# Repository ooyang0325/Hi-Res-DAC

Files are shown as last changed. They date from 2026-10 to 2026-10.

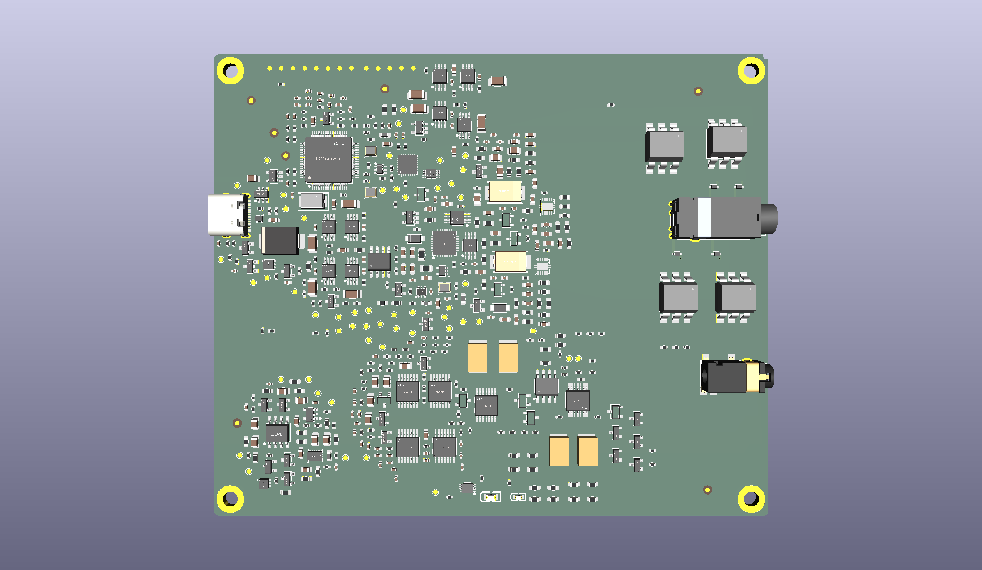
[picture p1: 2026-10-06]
hardware/DAC_HPA_3D_review.png

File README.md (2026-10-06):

# Hi-Res DAC + balanced headphone amplifier

The current layout review candidate is the editable [120 × 100 mm integrated-audio KiCad board](hardware/DAC_HPA_120x100_INTEGRATED_AUDIO_STUDY_ONLY.kicad_pcb), with manual placement and partial routing, paired with the [schematic](hardware/DAC_HPA.kicad_sch). Parts List v0.9 and Calculation Package v1.1 remain the baseline; the [captured ECO](hardware/FUNCTIONAL_ECO_2026-09-28.md) adds buffered supervisor readbacks and local J702 TVS parts. The incoming layout engineer should start with the [29 September handoff](hardware/LAYOUT_ENGINEER_HANDOFF_2026-09-29.md); peer reviewers can use the [reviewer guide](hardware/REVIEWER_START_HERE.md). The full-rate MCU capture guard, physical overlays, output routability and JLCPCB process gates remain open. No PCB manufacturing or PCBA order files are released.

## GitLab CI/CD

`.gitlab-ci.yml` uses the fixed official KiCad 10.0.1 container. Every pipeline checks schematic regeneration, netlist/ERC, the exact ECO delta, attach-charge arithmetic, placement geometry, JLC fabrication/assembly proxies, DRC and 3D model paths. A successful pipeline delivers the nine-page review PDF, the integrated-audio board's 3D GLB and top/L2/L3/bottom SVGs, earlier board GLBs for comparison, reviewer guides, BOM CSVs and a ZIP of the committed source as downloadable artifacts for 30 days.

The GitLab review package is **not** a manufacturing release. The connector and physical gates are tracked in [connector review](hardware/CONNECTOR_REVIEW.md) and [PCBA process review](hardware/PCBA_PROCESS_REVIEW.md). A routed PCB and CPL would be required for a PCBA upload.

The latest [DAC/core checkpoint](hardware/DAC_CORE_ROUTE_STUDY.md) records BCLK/LRCLK/SDATA at 22.213/22.324/22.879 mm and MCLK at 8.381 mm. The current integrated board has 544 footprints, 250 nets, 855 track/via items (143 vias), 864 full ratsnest links, 499 DRC-unconnected items and zero DRC violations. Its manual delta is 138 moves, eight source-copper removals and 828 additions. C622 has local 3V3D and GND copper; the global 3V3D feed remains open. All 12 U609/U610 timer branches pass the ≤8 mm screen without timer-net vias; C635/C636 U609 bypasses are locally connected, while upstream rail feeds and U609 VT/control escapes remain open. The [integrated-audio route study](hardware/INTEGRATED_AUDIO_ROUTE_STUDY.md) covers the DAC/I/V, amplifier-input, U501 and amplifier-to-jack copper including the completed U609/U610 timer branches and U609 local bypass work. Two U202 and five U301 exposed-pad vias are filled and capped; U401/U402 output-amplifier EP thermal routes remain open. The [via-pad audit](hardware/INTEGRATED_AUDIO_VIA_PAD_PROCESS_AUDIT.json) still flags 45 unfilled via-to-SMT-pad sites within 0.35 mm for JLC mask/process review. Full routing, system ESD, EMI and audio tests remain open; zero DRC violations apply to partial copper only.

The [schematic simplification review](hardware/SCHEMATIC_SIMPLIFICATION_REVIEW.md) lists three small DNF options for later review. Both headphone jacks and USB High mode remain required. The [discharge capture review](hardware/DISCHARGE_CAPTURE_REVIEW.md) identifies an open U303 calculation mismatch and links a separate [three-resistor 2512 fit option](hardware/DAC_HPA_120x100_DISCHARGE_FIT_OPTION_ONLY.kicad_pcb); the captured EN connection remains intentional, and the option is not a schematic/BOM change. The [Freerouting probe](hardware/FREEROUTING_PROBE.md) rejected a whole-board route and records two individually reviewed low-speed paths adopted later. The [functional-ECO board](hardware/DAC_HPA_120x100_FUNCTIONAL_ECO_STUDY_ONLY.kicad_pcb) is the preceding placement baseline; the former primary and [macro study](hardware/MACRO_PLACEMENT_REVIEW.md) are earlier comparisons. No PCBA order is authorized.

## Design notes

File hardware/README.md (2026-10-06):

# DAC-HPA KiCad schematic and routing studies

**Sending this design for peer review?** Begin with the [layout handover report](LAYOUT_HANDOVER_REPORT.md) and [REVIEWER_START_HERE.md](REVIEWER_START_HERE.md), then use the [schematic](SCHEMATIC_REVIEW_GUIDE.md), [placement](PLACEMENT_REVIEW_GUIDE.md), and [command-line visual inspection](PCB_CLI_VISUAL_REVIEW.md) guides. The [findings template](REVIEW_FINDINGS_TEMPLATE.md) records actionable review results against one Git commit.

The [functional-ECO placement baseline](DAC_HPA_120x100_FUNCTIONAL_ECO_STUDY_ONLY.kicad_pcb) is a separate 120 × 100 mm review board made from explicit hand-selected coordinates. It includes the [readback, J702 TVS and I/V A/B-channel schematic ECO](FUNCTIONAL_ECO_2026-09-28.md), a tighter DAC bypass row and the local J702 TVS branches. The [integrated audio study](INTEGRATED_AUDIO_ROUTE_STUDY.md) is the current routing review candidate; the newer [DAC/core checkpoint](DAC_CORE_ROUTE_STUDY.md) records its latest clock, I²S and local power routes. The [Freerouting probe](FREEROUTING_PROBE.md) rejects the whole-board result and documents two selectively adopted low-speed routes. [Layout review](FUNCTIONAL_ECO_LAYOUT_REVIEW.md) and [constraint disposition](CONSTRAINT_DISPOSITION_V2.md) state the remaining route work. `DAC_HPA.kicad_pcb` and the [prior macro study](MACRO_PLACEMENT_REVIEW.md) are historical comparisons; they predate the eight added parts.

Open `DAC_HPA.kicad_pro` or `DAC_HPA.kicad_sch` in KiCad 10. The root page links eight circuit sheets following Design Spec v1.1, Schematic Design Notes v1.0, Parts List v0.9, and Capture Update Note v1.0.

`DAC_HPA_review_only.pdf` is a nine-page visual export of the current provisional capture. The expanded protection sheet uses A1; smaller blocks use A2/A3/A4. Each sheet title block identifies v1.1-ECO1 and the open F01/F03/G-1–G-4 holds. The KiCad project is the editable source.

## Current status

- The v0.9 workbook has 526 netlisted designators and 1,445 pin rows; those rows still match Calculation Package v1.1. The [asserted functional ECO](FUNCTIONAL_ECO_2026-09-28.md) adds eight parts and reassigns equivalent U403/U404 A/B channels to match the manual I/V macro. KiCad now has **534 netlisted designators, 1,465 pins, 1,422 connected pins, 43 no-connect pins and 250 named nets**, plus four grounded mounting holes and seven fiducials. The exact **34** workbook-to-capture pin/net differences are checked; they include the earlier D705/D706 polarity fix. J702 pins 5/6 remain no-connect break contacts.
- Per-part MPN, LCSC code, fit class, package, and rating/tolerance properties are included for later [JLCPCB BOM preparation](https://jlcpcb.com/help/article/how-to-generate-the-bom-and-centroid-file-from-kicad). The owner approved changing U403/U404 from workbook OPA2210IDR SOIC-8 to OPA2210IDGKR VSSOP-8, C2876414. `generate_schematic.py` asserts the old workbook entry and applies this explicit override; `IV_7MM_RECHECK.md` records the provisional 7 mm input-route reassessment and sourcing/footprint limitations.
- The review-only JLCPCB BOM contains **463 placed parts**, seven owner-fitted and nine DNF parts. Fourteen placed parts have no LCSC code and need the documented global-sourcing process. The three CSVs are **not** an order package; a routed PCB and CPL are still required.
- The schematic-aligned four-layer **120 × 100 mm functional-ECO baseline** has **544 footprints and 250 named nets**; J703 remains a schematic DNF option with no PCB pads. Its partial copper comprises J701/J702 local TVS branches and the hand-routed X201→R203→U301 MCLK trunk, R227 return and R665→U607 monitor input: **28 F.Cu tracks, seven vias** and one filled L2 GND zone. It has zero geometry DRC violations and 1,144 full ratsnest gaps. The old 536-footprint primary and 100 × 80/100 × 100 mm boards are historical comparisons.
- The [separate 270° output-macro study](OUTPUT_MACRO_ROUTE_STUDY.md) keeps the same schematic/pad map and manually connects all four U401/U402 amplifier outputs and local feedback to K601–K604 relay inputs. Its partial copper passes custom-rule DRC, but the jack outputs, input/T networks, supply returns and L3/L4 audio return remain on hold; it is a comparison, not the primary order board.
- The current [integrated-audio routing study](INTEGRATED_AUDIO_ROUTE_STUDY.md) routes four DAC→I/V inputs, eight I/V→first-T feeds, all eight local input T triplets and all four amplifier-to-jack paths. The current board has **855 track/via items (143 vias), zero DRC violations, 499 DRC-reported unconnected items and 864 full `pcbnew` ratsnest links**. Its manual record has **138 footprint moves, eight removed source-copper items and 828 added items**. DACL/DACLB/DACR/DACRB no-via F.Cu routes measure **4.294/6.030/6.837/4.786 mm** against the provisional 7 mm target, leaving DACR **0.163 mm**. Saved L2 GND is directly below all four input traces at 0.01 mm route samples and offsets 0, ±0.05, ±0.10 mm. The longest I/V→first-T feed is **47.752 mm** on the right; the largest projected 2D I/V feedback area is **4.875 mm²**, excluding vertical and return-current area. DACL's U403→C417 feedback branch still lacks direct L2 for **1.9426 mm** of centreline (**+0.0597 mm** from the like-for-like committed baseline). Central VREF copper reaches **14.422 mm**. Extract summing-node capacitance, the DACL feedback return, 3D loop geometry, right-side cross-layer coupling and VREF noise before I/V sign-off.
- The newer [DAC/core checkpoint](DAC_CORE_ROUTE_STUDY.md) records U202 local bypass routes at 1.103/2.056/3.057 mm, U302 VIN→C301 at 0.875 mm and OUT→C302 at 2.131 mm, and connected U303→DAC 1V3 copper at **25.393 mm with two vias**. C622 at **(108.65, 105.50)** has a **4.615 mm** U604.8→C622.1 path and a **1.020 mm** C622.2→Ø0.7/0.3 mm GND via path at **(110.15, 105.50)**, with saved L2 GND beneath both; the global 3V3D feed remains open. Thirty-five local GND pads reach L2. Two U202 and five U301 EP vias are filled/capped; U401/U402 output-amplifier EP thermal routes remain open. The via-pad audit reports zero unfilled overlaps and zero unfilled gaps below 0.10 mm; **45** unfilled via-to-SMT-pad sites within 0.35 mm need JLC mask/process review. Local film/via/timer geometry gates pass, while those 45 process reviews remain open.
- The integrated checkpoint routes all 12 U609/U610 timer branches under the named-pad ≤8 mm screen without timer-net vias. U609 LP C/Q/R routes are **6.089/5.340/4.943 mm** and LN routes **6.038/5.814/6.685 mm**; U610 LP routes are **6.442/7.607/1.789 mm** and LN routes **7.177/7.712/7.787 mm**. C631/C632/C633/C634 GND returns reach L2 in **3.580/3.656/2.650/2.650 mm**. C635/C636 U609 VPOS/VNEG bypasses connect with 11 new vias (six GND, three VPOS, two VNEG). Upstream rail feeds and U609 VT/control escapes remain open. U605/R675/R676/R679/R677 moved left 1.2 mm and C625 moved beside R666, clearing six measured 5 mm I²S/protection gaps. C638 uses a two-via L3 VNEG bridge to keep the timer paths clear. C636 has a pair-specific **0.60 mm** side-courtyard gap to C631/C632; all four film-cap north/south solder approaches pass at ≥**1.5 mm** (minimum **3.045 mm**) per the [film solder-access audit](INTEGRATED_AUDIO_FILM_SOLDER_ACCESS_AUDIT.json).
- The [schematic simplification review](SCHEMATIC_SIMPLIFICATION_REVIEW.md) lists three small DNF options for later decision. The owner keeps both headphone jacks and USB High mode; no populated output links, relays, protection or hold-up parts are proposed for deletion.
- The [discharge capture review](DISCHARGE_CAPTURE_REVIEW.md) keeps the intended U303 EN=3V3D connection and identifies stale C06/C12 assumptions. A separate [physical fit option](DAC_HPA_120x100_DISCHARGE_FIT_OPTION_ONLY.kicad_pcb) tries three provisional 2512 discharge-resistor bodies. Its [audit](DISCHARGE_FIT_OPTION_SUMMARY.json) passes nominal body-edge, overlap, 3D and DRC screens, but it is not schematic/BOM aligned or a release board; maker/JLC lands, source feeds, thermal behavior and shutdown timing remain open.
- The [29 September layout-engineer handoff](LAYOUT_ENGINEER_HANDOFF_2026-09-29.md) identifies the primary board, CLI inspection sequence, route status, the separate discharge fit option and the next engineer's release gates.
- U501 local switching, VIN, VPOS/VNEG cap and feedback groups now have copper. Three bounded **0.20 mm** WSON VIN escapes precede the wider `5V_ANA_F` feeder. Its B.Cu feeder now detours around F.Cu `N5_FBP`: projected track overlap **0.1663→0 mm²** and unshielded pad-inclusive projection **0.0861→0 mm²**. The original via antipad remains; VIN3→C507 is **6.014 mm** within its 6.1 mm bound. C510/C511 GND vias are **8.160/6.767 mm** from U501's GND via by straight L2 via spacing, not an extracted return path. The board has zero exact or near-90° bends, zero footprint bbox overlaps, and zero classified JLC spacing findings. Full routing, system ESD, EMI/audio tests, measured R-15 and F01–F04/G-3/G-4 remain on HOLD. Courtyard gaps near C423/C426 are **0.150–0.194 mm**; C437/J701/K602 and via mask also need JLC order DFM review.
- Both U401/U402 pin-8 EN inputs have copper to the shared local VPOS bypass network. A custom rule screens 2 mm F.Cu left/right separation before the output links. With the [review-only 1 mΩ-max output-link candidate](OUTPUT_LINK_BOM_ECO.md), conditional worst 4.4 mm estimates are 0.3862/0.3737 Ω (L/R) at 1 kHz and 0.3990/0.3864 Ω in the 20 kHz model sensitivity. Contact/via assumptions, measured R-15 and physical/JLC gates still hold fabrication release.
- Every current footprint/pad net matches the ECO schematic. The new DAC high-frequency capacitors are 1.86–2.30 mm by pad distance from their supply pins; the U621 high-impedance input stubs are 1.69/1.86 mm by pad distance. The J702 TVS signal branches are 3.861/3.250 mm. The custom J701/J702 enlarged slot lands retain ≥0.31 mm worst calculated copper ring under the stated JLC slot tolerance. Physical G-3 overlays and JLC DFM remain open.
- All **478 component bodies** on the current candidate have resolvable 3D models; 66 test/debug/mechanical copper items intentionally have none. `3D_MODEL_REVIEW.md` distinguishes exact JLC/Toshiba sources from approximate oscillator and film-capacitor bodies. Open the current candidate in **View → 3D Viewer**.
- `verify_critical_footprints.py` checks 56 critical pad dimensions, pad types and hole/paste properties, including U202's exposed pad, the new TI DGK and onsemi SOT-23 lands, and J101/J701/J702 slots and locating holes. Physical G-3 overlays are still open.
- `G3_CONNECTOR_OVERLAY_REVIEW_ONLY.svg` and `G3_PART_OVERLAY_REVIEW_ONLY.svg` are printable A4 1:1 overlays for 30 unique footprint patterns, including U621 and the J702 TVS package; first measure each 10 mm reference bar. `G3_OVERLAY_INDEX.md` identifies the patterns and `G3_OVERLAY_CHECKLIST.md` holds editable physical sample results. The two-sample DMM and polarity templates are `G1_G2_CONTINUITY_RECORD.md` and `G4_POLARITY_CHECKLIST.md`.
- KiCad ERC reports zero violations. Confirmed power, logic, oscillator and open-collector outputs are typed; most other generated pins remain passive, so ERC does **not** substitute for a datasheet-level electrical review.
- `verify_design_notes.py` checks 1,002 selected circuit and approved-correction assertions. `SOURCE_RECONCILIATION.md` and the [ECO note](FUNCTIONAL_ECO_2026-09-28.md) record controlled changes from the source set.
- The v1.1 design documents mark schematic capture and provisional placement GO and originally hold routing until G-1–G-4 pass. The owner reports both J101 samples match the USB-C map, both J701 samples match the intended audio and 9/10 switch maps, and both J702 samples match the TRS and break map. On 27 September 2026 the owner waived the G-1/G-2 raw measurement log; these reported results are accepted for layout planning without independent evidence. G-3 overlays and G-4 polarity still hold routing, as do the new routability and audio/EMI placement conflicts. J702 supports TRS plugs only. `PRELAYOUT_GATES.md` tracks the gate evidence and later G-5/G-6 holds. See `CONNECTOR_REVIEW.md` for connector maps and copper-ring decision, `POLARITY_REVIEW.md` for the D705/D706 correction, and `CAD_models_to_upload.md` for exact 3D models still desired.
- `PCBA_PROCESS_REVIEW.md` records the J101/J702 plated slots with no paste apertures and the exact JLCPCB process question to resolve before assembly release. The v1.1 calculation package's starting output-impedance estimates are 0.251 Ω (3.5 mm) and 0.383 Ω (4.4 mm), with 50 mΩ budgeted per output link. The candidate link's 1 mΩ maximum reduces that model term; routed copper and illustrative vias give the current conditional 4.4 mm estimates above. The 3.5 mm signal-only lower bounds are 0.2255/0.2188 Ω (L/R), with sleeve return unextracted. Both jacks still need measurement against R-15, and the 50 mΩ per jack-contact estimate has no maker maximum.

The included JLCPCB library data came from LCSC codes through `dsa-t/jlc-kicad-lib-loader` 1.0.11. `JLC_Source/JLC_DAC_HPA.elibz` now keeps **42 source CAD entries**, including exact C507231 for U621; `JLC_Imported.pretty` contains native KiCad footprints, and `jlc_footprints.json` records pad comparisons. The TI DCK example land and JLC C507231 land differ, so U621 remains a G-3 overlay item. The project footprints are in `DAC_HPA.pretty`; custom land sources are in `FOOTPRINT_SOURCES.md`.

## Regenerate and verify

With Python 3, `openpyxl`, and KiCad 10 installed:

```sh
python3 hardware/audit_jlc_library.py
python3 hardware/derive_connector_footprints.py
python3 hardware/generate_schematic.py
python3 hardware/verify_schematic.py
python3 hardware/verify_design_notes.py
python3 hardware/export_assembly_review.py
python3 hardware/check_attach_charge.py
python3 hardware/check_spi2_capture_contract.py
/Applications/KiCad/KiCad.app/Contents/Frameworks/Python.framework/Versions/Current/bin/python3 hardware/verify_critical_footprints.py
/Applications/KiCad/KiCad.app/Contents/Frameworks/Python.framework/Versions/Current/bin/python3 hardware/audit_placement.py hardware/DAC_HPA_120x100_FUNCTIONAL_ECO_STUDY_ONLY.kicad_pcb --height 100 > /tmp/dac-eco-placement.json
/Applications/KiCad/KiCad.app/Contents/Frameworks/Python.framework/Versions/Current/bin/python3 hardware/audit_dfa_dfm.py hardware/DAC_HPA_120x100_FUNCTIONAL_ECO_STUDY_ONLY.kicad_pcb > /tmp/dac-eco-dfa.json
/Applications/KiCad/KiCad.app/Contents/Frameworks/Python.framework/Versions/Current/bin/python3 hardware/audit_jlc_fab.py hardware/DAC_HPA_120x100_FUNCTIONAL_ECO_STUDY_ONLY.kicad_pcb > /tmp/dac-eco-fab.json
/Applications/KiCad/KiCad.app/Contents/MacOS/kicad-cli pcb drc --format json --severity-error --severity-warning -o /tmp/dac-eco-drc.json hardware/DAC_HPA_120x100_FUNCTIONAL_ECO_STUDY_ONLY.kicad_pcb
/Applications/KiCad/KiCad.app/Contents/Frameworks/Python.framework/Versions/Current/bin/python3 hardware/check_functional_eco_layout.py hardware/DAC_HPA_120x100_FUNCTIONAL_ECO_STUDY_ONLY.kicad_pcb /tmp/dac-eco-placement.json /tmp/dac-eco-dfa.json /tmp/dac-eco-fab.json /tmp/dac-eco-drc.json
/Applications/KiCad/KiCad.app/Contents/Frameworks/Python.framework/Versions/Current/bin/python3 hardware/audit_3d_models.py hardware/DAC_HPA_120x100_FUNCTIONAL_ECO_STUDY_ONLY.kicad_pcb
/Applications/KiCad/KiCad.app/Contents/MacOS/kicad-cli sch export pdf -o hardware/DAC_HPA_review_only.pdf hardware/DAC_HPA.kicad_sch
```

`generate_schematic.py` reads `doc/DAC_HPA_Parts_List_v0.9.xlsx`, asserts the source pin maps, applies the ECO and rewrites the generated sheets/symbol library. Run the CAD audits before regeneration when source data changes. Manual KiCad edits to generated schematic files are replaced on regeneration; edit the generator's asserted ECO or make a controlled new workbook revision. `manual_functional_eco_layout.py` records all additional hand-selected positions and local J702 tracks; its UUIDs may differ on reproduction, while `check_functional_eco_layout.py` checks the committed geometry and schematic pad map. `manual_integrated_audio_study.py` replays the frozen manifest of **138 footprint moves, eight source-copper removals and 828 added copper items**; `check_integrated_audio_study.py` compares them with the review board. The command block above verifies the earlier functional-ECO baseline; the [integrated CI job](../.gitlab-ci.yml) audits the current candidate. `place_board.py --force` is only for historical automatic comparisons.

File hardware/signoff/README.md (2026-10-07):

# Independent sign-off suite

A self-contained review of the Hi-Res DAC board, built from published
criteria rather than from the repository's existing CI. Nothing here imports
or re-uses the other checks in this repo; the intent is a second opinion that
can disagree with the first.

## Running it

```powershell
# Extract the board model (positional argument, not --pcb)
python hardware/signoff/extract.py <board.kicad_pcb> -o hardware/signoff/out/model_integrated.json

# Run every gate
python -m hardware.signoff.run

# A single gate, or skip the simulations
python -m hardware.signoff.run --gate G40
python -m hardware.signoff.run --no-spice
```

Outputs land in `hardware/signoff/out/`:

| File | Contents |
| --- | --- |
| `signoff_result.json` | Full machine-readable result: metrics, findings, assumptions |
| `SIGNOFF_REPORT.md` | Human-readable summary |
| `spice/*.cir` | Every generated LTspice deck |
| `spice/*.log` | Measurement logs backing the simulation verdicts |

The exit code follows the worst gate status, so this works as a CI step.

## Design

```
extract.py   -- the only module that imports pcbnew; emits plain JSON
     |
     v
model_integrated.json  (tool-independent board model)
     |
     +-- geom.py        pad/track/drill geometry
     +-- netgraph.py    resistive network solver per net
     +-- parasitics.py  capacitor ESL/ESR and mounting inductance
     +-- rules.py       published numeric criteria
     +-- design_intent.py  what each net is for
     |
     v
gates_*.py  -->  run.py  -->  JSON + Markdown
```

Keeping KiCad behind `extract.py` means the gates are testable without the
EDA tool, and the same model feeds the geometric checks and the simulations,
so they cannot silently disagree about the board.

## Validation

A review tool that is wrong is worse than no review, so the geometric engine
was checked against KiCad's own DRC before any verdict was trusted:

```powershell
kicad-cli pcb drc --format json --severity-all -o hardware/signoff/out/kicad_drc.json <board.kicad_pcb>
```

| Check | KiCad | This suite |
| --- | --- | --- |
| Unconnected items | 0 | 0 opens across all 12 rails |
| `hole_clearance` errors | 4 (all at J101) | the same 4, same pads, same gaps |

Reaching that agreement found three real bugs in this suite, all of which had
produced confident but wrong output:

1. **T-junctions.** Tracks were modelled as a single endpoint-to-endpoint
   edge, so copper landing part way along another track was treated as
   unconnected. 70 of 333 VPOS endpoints land mid-span, which invented 53
   phantom islands and a 45-billion-millivolt IR drop. Tracks are now split at
   every node that touches them.
2. **Slot drills.** J701/J101 use oval slots. Treating them as circles of the
   major axis produced a false hole-to-hole failure and a physically
   impossible negative annular ring. Slots are now modelled as capsules.
3. **Rounded pad corners.** 762 pads are roundrect. Treating them as sharp
   produced a drill-to-copper violation KiCad did not report; with the real
   corner radius it disappears.

The LTspice measurement parser was likewise validated against a series R-L-C
circuit whose impedance is analytically known, before being pointed at the
board:

| Frequency | Analytic | LTspice via this parser | Error |
| --- | --- | --- | --- |
| 1 MHz | 1.65626 ohm | 1.65656 ohm | 0.02% |
| 10 MHz | 0.50112 ohm | 0.50212 ohm | 0.20% |

That test also caught a regex that let a log preamble line swallow the
following measurement's value.

## What the simulations do differently

`hardware/sim/dac_1v3_bypass.cir` states in its own header that its
inductances are "explicit assumptions" (5 nH and 20 nH). The decks in
`spice/` are generated instead from the board:

- **Capacitance** parsed from the placed part's value field.
- **ESL and ESR** from the actual package (`C_0402_1005Metric` -> 0402).
- **Mounting inductance** from the real via pair under each capacitor --
  measured pitch, measured drill, measured pad-to-via run -- via the
  loop-inductance result in C. R. Paul, *Inductance*.
- **Series resistance and path length** from the solved copper network, so a
  capacitor 33 mm away through copper is modelled as 33 mm away.

Measured mounting inductances come out at 1.0-2.1 nH, so the existing deck's
5 nH best case was pessimistic while its 20 nH case was unrepresentative.

## Handling what cannot be known

The board declares **no stackup**, so the height from the outer layer to the
first plane is unknowable from the design. Rather than pick a number, every
PDN deck sweeps `h` over the plausible construction range (0.09 / 0.12 /
0.20 mm) with `.step` and the gate reports the worst case. The same principle
is applied elsewhere:

- **G10** reports what each conductor would carry at 1 oz inner copper as
  well as the assumed 0.5 oz, which separates findings that survive the
  assumption from those that do not.
- **G40** reports, for every failing rail, the transient current at which it
  *would* pass, so the finding can be settled against a datasheet figure
  instead of against an estimate.

Current budgets in `design_intent.RAILS` are estimates and are marked
`assumed: True`. They should be reconciled with the Calculation Package.

## Gates

| ID | Title | Basis |
| --- | --- | --- |
| G01 | Fabricator process window | JLCPCB capability sheet |
| G02 | Electrical clearance | IPC-2221B Table 6-1 |
| G03 | Plated-hole geometry | IPC-6012 |
| G04 | Assembly geometry | IPC-7351B |
| G05 | Fabrication documentation | IPC-2614 / controlled-impedance practice |
| G06 | Drill-to-copper clearance | JLCPCB 0.28 mm; validated against KiCad DRC |
| G10 | Conductor ampacity | IPC-2221B `I = k dT^0.44 A^0.725` |
| G11 | Via ampacity | IPC-2221B applied to barrel cross-section |
| G12 | DC IR drop | Solved network against a per-rail budget |
| G13 | Decoupling placement and mounted resonance | Mounted self-resonant frequency |
| G20 | USB high-speed pair | USB 2.0 spec: 90 ohm +/-15%, 3.81 mm skew |
| G21 | Clock routing and aggressor spacing | 3W rule; jitter-limited SNR |
| G22 | Return path continuity | Ott, *EMC Engineering* |
| G23 | Switching-node keep-out | Analogue/digital separation floor |
| G30 | Output path resistance and channel matching | Self, *Audio Power Amplifier Design* |
| G31 | I/V and feedback loop geometry | Loop area as a magnetic antenna |
| G32 | External port ESD protection | IEC 61000-4-2 stub let-through |
| G40 | PDN impedance (LTspice) | Smith/Bogatin target impedance |
| G41 | Output loading and damping (LTspice) | Damping factor into the rated load |

`G06`, `G40` and `G41` are the gates with no counterpart in the existing CI.

## Known limits

- Copper weight is assumed (no stackup); G10/G11/G12 inherit that.
- `infer_rail_sources()` is a heuristic. G40 instead identifies regulators by
  their feedback net, which correctly separates the 1V3 LDO (U303, which has
  `N3_1V3_FB`) from the DAC that consumes the rail.
- G40 models each rail at its single worst-case pin, not as a distributed
  plane; it is a lumped study, not a 3D field solve.
- Zones are included in the solved network, but the board routes its rails as
  0.4 mm traces rather than poured planes, so this matters little here.

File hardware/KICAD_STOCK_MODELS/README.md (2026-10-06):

# Bundled KiCad package models

These 12 unchanged STEP models come from the installed KiCad 10 3D library,
whose upstream source is the [official KiCad Packages3D repository](https://gitlab.com/kicad/libraries/kicad-packages3D).
The KiCad community is credited as the library author. The files retain their
original library-relative names and directories. `MODEL_SOURCES.json` lists
each file and SHA-256 digest.

These models are distributed under KiCad's CC BY-SA 4.0 library license and
design exception, reproduced in [LICENSE.md](LICENSE.md). The project copies
only the shapes referenced by the current PCB and the discharge-fit option so
a fresh GitLab runner can resolve them while exporting review-only GLBs. The
2512 resistor body was added for the three-part power fit study. No 3D
geometry was changed.

To refresh this directory from an installed KiCad 10 library, run
`vendor_kicad_stock_3d_models.py` with KiCad's Python interpreter. By default
it scans the primary, integrated and discharge-fit boards; pass board paths
to restrict the scan. Set
`KICAD_STOCK_3D_SOURCE` if the installed 3D library is not in a standard
location. Review upstream revisions and license details before replacing the
copied files.

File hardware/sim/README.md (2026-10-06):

# DAC 1V3 bypass sensitivity (review model)

This study compares the fitted C312 1 µF bulk capacitor in the old remote
placement with the hand-moved position beside U301/C309. The old position was
**unrouted**: its straight pad-to-U301 distance was about 16.3 mm. The trial
position has about 4.3 mm of drawn C312→C309→U301 F.Cu centreline. C310
2.2 µF stays beside regulator U303, so its regulator output capacitance is
preserved. C309 is the DAC's local 100 nF part. The routes and filled L2
ground must be inspected on the current PCB study; these distances alone do
not specify branch inductance.

The latest [DAC/core route audit](../DAC_CORE_ROUTE_AUDIT.json) also reports
a connected U303→DAC 1V3 link whose L3 portion is 25.393 mm, with two
vias, 35 local DAC/CPLD/LDO GND pads connected to L2, and short
U302-to-capacitor routes.
These drawn connections do not supply the upstream ferrite rails or measure
the regulator, capacitor, or return impedance; the simulations below remain
assumption-based sensitivity results.

The [LTspice deck](dac_1v3_bypass.cir) and
[MATLAB sweep](dac_1v3_bypass.m) use three passive capacitor branches at
U301 pin 21. They assume C309 100 nF/50 mΩ/2 nH, C312 1 µF/50 mΩ with
either 5 nH (local) or 20 nH (remote), and C310 2.2 µF/60 mΩ/20 nH.
Inductances include **assumed** capacitor, trace and return effects; they
were not extracted from a quoted stackup or measured board. The 1 GΩ DC
bleeders in LTspice only define the operating point. A 1 A AC test source
therefore makes its simulated node-voltage magnitude equal to impedance in
ohms.

| Frequency | Local 5 nH, MATLAB | Remote 20 nH, MATLAB | LTspice check |
| --- | ---: | ---: | --- |
| 100 kHz | 0.4778 Ω | 0.4769 Ω | Within 0.01% |
| 1 MHz | 0.0832 Ω | 0.0431 Ω | Within 0.57% |
| 10 MHz | 0.0654 Ω | 0.0631 Ω | Within 1.36% |
| 80 MHz | 0.6619 Ω | 0.8249 Ω | Within 0.01% |

Across 100 kHz–80 MHz, the remote case has an **illustrative** 1.045 Ω
antiresonance near 4.66 MHz; the local case's largest sampled value is
0.662 Ω at the 80 MHz upper boundary. Moving a capacitor can also shift a
resonance unfavourably: the local case is higher at 1 MHz. See the
[MATLAB plot](dac_1v3_bypass_sweep.png),
[sweep data](dac_1v3_bypass_sweep.csv), and
[LTspice log](dac_1v3_bypass_ltspice.log).

The model excludes the regulator's output impedance, power-plane geometry,
MLCC capacitance versus bias/temperature, DAC load spectrum, other rail
coupling, dielectric loss and any audio transfer function. It does not
predict hum, RF ingress, jitter, or THD+N. Extract the routed supply and
ground loop, obtain capacitor impedance/derating data and measure ripple at
U301 under operating loads before accepting the rail.

There is a separate **component-value hold**. [ESS's ES9018K2M datasheet,
DVDD Supply](https://www.esstech.com/wp-content/uploads/2024/09/ES9018K2M-Datasheet-v3.7.pdf)
recommends a 2.2 µF ±20% local DVDD decoupler that retains at least 1 µF
at 1.2 V over operating temperature. Fitted C312 is 1 µF nominal. The
remote C310 is 2.2 µF, but cannot establish a local high-frequency return
by capacitance alone. Review a 2.2 µF C312 ECO or another local bulk part,
using verified effective-capacitance data and an updated schematic/BOM.
The captured 2.2 µF Samsung part is a 0603 X5R 16 V MLCC; its [manufacturer
page](https://product.samsungsem.com/mlcc/CL10A225KO8NNN.do) lists the
nominal ratings but does not establish the required effective capacitance
at this board's bias and temperature.

## Reproduce

On macOS with the installed tools, run from the repository root:

```sh
cp hardware/sim/dac_1v3_bypass.cir /tmp/dac_1v3_bypass.cir
/Applications/LTspice.app/Contents/MacOS/LTspice -b /tmp/dac_1v3_bypass.cir
/Applications/MATLAB_R2025a.app/bin/matlab -batch "run('hardware/sim/dac_1v3_bypass.m')"
```

The LTspice log reports AC magnitude in dB; convert with `10^(dB/20)` to
obtain ohms for its 1 A source. LTspice 26.0.2 and MATLAB R2025a completed
on 29 September 2026. Direct simulator invocation required normal macOS app
registration on this host; a sandboxed CLI launch had failed before either
simulation started.

# EMS review simulations (30 September 2026)

These review models support [EMS_VERIFICATION_2026-09-30.md](../EMS_VERIFICATION_2026-09-30.md).
They are assumption-based sensitivity studies, not extracted or measured
results. LTspice 26.0.2 (Windows build under Wine) runs from macOS with:

```bash
CX_BOTTLE_PATH="$HOME/Library/Application Support/LTspice/Bottles" \
  /Applications/LTspice.app/Contents/SharedSupport/ltspice/LTspice/wine --bottle=ltspice \
  --wait-children 'C:\Program Files\ADI\LTspice\LTspice.exe' -b -ascii 'Z:\path\to\deck.cir'
```

| Deck | Question | Result |
| --- | --- | --- |
| [ems_headphone_rf.cir](ems_headphone_rf.cir) | RF on the headphone cable (150 Ω common-mode source) reaching the OPA1622 inverting input, 10 MHz–6 GHz; R417 0 Ω vs ferrite bead, with/without a LEG C0G | As built, the output network (TVS 12 pF, relay and trace inductance, OPA1622 open-loop Z<sub>O</sub> 5.5 Ω + 63 nH from datasheet Fig. 40) resonates near 350–450 MHz with about 0 dB coupling. Coupling is −30 dB at 900 MHz and −61 dB at 2.4 GHz ([log](ems_headphone_rf_ltspice.log)). |
| [ems_rf_sweep.cir](ems_rf_sweep.cir), [ems_rf_best.cir](ems_rf_best.cir) | Bead impedance and LEG capacitor sweep | [sweep log](ems_headphone_rf_sweep_ltspice.log), [best-case log](ems_headphone_rf_best_ltspice.log) |
| [ems_5vana_filter.cir](ems_5vana_filter.cir) | FB501 + R531/C513 damper feeding the LM27762 | With the damper and 10 µF parts derated to 40 %, the line-transfer peak falls from +5.4 dB to +1.8 dB and the U501 input impedance peak from 1.25 Ω to 0.74 Ω. The 2 MHz charge-pump ripple stays 52–60 dB down on 5V_ANA ([log](ems_5vana_filter_ltspice.log)). |

[ems_budget.m](ems_budget.m) (MATLAB R2025a) turns the RF transfer into an output-referred
217 Hz buzz with TI's EMIRR square law. It uses the OPA2210 EMIRR curve as a proxy,
because the OPA1622 publishes none, and a −20 dB cable common-mode to tip conversion.
It also computes the USB-ripple and VREF paths from the LM27762, LP5907 and OPA1622 PSRR
curves ([summary](ems_budget_summary.txt), [plot](ems_rf_demod.png)). Regenerate
`ems_headphone_rf.raw` with the command above before running it.
[../review_output_rf_filter.py](../review_output_rf_filter.py) checks the proposed output
filter with the unchanged calibrated OPA1622 model from Calculation Package v1.1
([results](../OUTPUT_RF_FILTER_STABILITY_REVIEW.json)).

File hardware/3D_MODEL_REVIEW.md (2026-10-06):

# PCB 3D model review

The current **120 × 100 mm** schematic-aligned board is
`DAC_HPA_120x100_INTEGRATED_AUDIO_STUDY_ONLY.kicad_pcb`. Open it in KiCad 10 and
choose **View → 3D Viewer**. GitLab CI exports
`DAC_HPA_INTEGRATED_AUDIO_REVIEW.glb` for this candidate; the functional-ECO,
output-macro, macro-study and primary GLBs are earlier comparisons. A separate
[discharge fit option](DAC_HPA_120x100_DISCHARGE_FIT_OPTION_ONLY.kicad_pcb)
exports `DAC_HPA_DISCHARGE_FIT_OPTION_REVIEW.glb` with three provisional 2512
resistor bodies; it is not schematic/BOM aligned. Its GLB uses the bundled
KiCad stock 2512 STEP, while the separately retained [exact JLC R2512 STEP](EASYEDA_MODELS/R2512_L6.3-W3.2-H0.6.step)
and [CAD audit](DISCHARGE_JLC_CAD_AUDIT.json) support a later land/model
comparison. The prior
[full-board preview](DAC_HPA_3D_review.png) and [J101 closeup](DAC_HPA_J101_3D_detail.png)
show the historical primary after the USB-C model alignment correction.

The [manual macro-placement study](MACRO_PLACEMENT_REVIEW.md) has the older 536-footprint population. The [functional-ECO placement baseline](DAC_HPA_120x100_FUNCTIONAL_ECO_STUDY_ONLY.kicad_pcb) added D707/D708 with the existing SOD-523 model and U621 with a new exact-JLC C507231 SC70-6 body; the integrated board retains that 544-footprint population. These models remain subject to G-3 fit and JLC order checks.

## Coverage and sources

`audit_3d_models.py` checks model paths, file headers, and the JLC file hashes.
On the current integrated-audio board, **478 component bodies resolve**
(474 STEP and four VRML), while 66 copper-only items intentionally have no
model. Of the 478, 385 use KiCad stock models and 93 use project-local files.
The five historical review boards each have 536 footprints: **470 component bodies resolve**
(466 STEP and four VRML), while 66 copper-only items intentionally have no
model (53 test pads, seven fiducials, four mounting holes, and J201/J202 debug
pads). Of the 470, 380 use KiCad 10 stock models and 90 use files kept in this
project. The 90 project-file instances are 82 instances of 30 JLC package
models, four Toshiba relays, and four Panasonic body envelopes. The 380 stock
instances use only 11 distinct KiCad STEP files; unchanged copies are bundled
in `KICAD_STOCK_MODELS` for headless CI, with KiCad's license and hashes. The
fit option adds a twelfth distinct stock STEP shape for 2512 resistors; its
CI artifact includes the 3D audit, which resolves 478 populated bodies.

| Parts | 3D source and alignment | Confidence for 3D inspection |
| --- | --- | --- |
| J701, J702 and the imported JLC footprints | STEP from the component's EasyEDA/JLC CAD entry. The 31 files, source URLs, LCSC codes, conversions, and SHA-256 hashes are in `EASYEDA_MODELS/MODEL_SOURCES.json`. | Source package bodies; the modified jack copper and slots still require G-3 sample overlay and JLC DFM. |
| U621 | Exact C507231 JLC SC70-6 body and native pad geometry, normalized to STEP. | Model and pads match the JLC CAD entry, but TI's DCK example land has a wider pad-row span. Resolve the physical G-3/JLC DFM discrepancy before order. |
| J101 | KiCad 10 `USB_C_Receptacle_GCT_USB4105-xx-A_16P_TopMnt_Horizontal.step`, with −1.295 mm local Y offset for the custom footprint origin. A J101-only STEP probe puts the shell front at x = 40.03 mm beside the x = 40.00 mm board edge. | Exact connector family body; visually aligned in KiCad 3D Viewer. The footprint and solder lands remain at the GCT PCB-edge datum. G-3 physical overlay still open. |
| K601–K604 | User-supplied Ultra Librarian `TLP3545A_LF1__TOS.step`, stored as `DAC_HPA_3D/TLP3545A_LF1_UltraLibrarian.step`. Local Z rotation is −90° to align the model's pad-1 side to the custom LF1 footprint. | Exact Toshiba LF1 body; visually aligned in KiCad 3D Viewer. Source STEP SHA-256: `3534740be81c87bf067b67926e57872bb9693455f3bbc5ab0c75e69f7ab00c74`. |
| X201–X203 | KiCad stock `Crystal_SMD_2520-4Pin_2.5x2.0mm.step`. | 2520 four-pad package approximation; maker-exact oscillator bodies remain desirable. |
| C631–C634 | `DAC_HPA_3D/ECHU1H224GX9_envelope_only.wrl`, a 6.0 × 4.1 × 2.8 mm Panasonic body envelope. | Review-only shape without terminals. It renders in KiCad 3D Viewer but is omitted from non-mesh STEP export. Maker STEP remains desirable. |
| D102 and other stock-footprint parts | KiCad 10 standard package STEP models. | Package shapes for 3D inspection; confirm exact part dimensions at G-3. |

The original user-downloaded Ultra Librarian ZIP is not required by KiCad after
extracting its STEP. Its source ZIP SHA-256 is
`9c409738e9fb11241a2306db80b8167d6a3af8ac0be0cab408640a1d2ce81f1d`.
`fetch_jlc_3d_models.py` can restore the original 30 JLC STEP files from the saved
`JLC_Source/JLC_DAC_HPA.elibz` identifiers when network access is available;
it does not move footprints. `attach_3d_models.py` adds the twelve custom
model links to the five board snapshots if absent. GitLab CI sets
`KICAD10_3DMODEL_DIR` to the bundled stock library so its GLB includes the
same package shapes as the KiCad desktop installation, including the option's
new 2512 model.

## Limits

The 3D view verifies that model files load and permits visual package and
clearance review. It does **not** prove pad numbering, solder-joint geometry,
height tolerance, connector mating, or routability. G-3 overlays, the JLCPCB
DFM review, and routing/ESD gates in `PRELAYOUT_GATES.md` remain open. The
current integrated-audio board is a partial-route review, not a PCBA
release package.

KiCad's GLB exporter currently skips the four VRML film-capacitor envelopes;
use the KiCad 3D Viewer to see those bodies. An earlier primary-board GLB was
checked with Assimp as a valid 480-node, 6,042-mesh model after correcting
J101's offset.

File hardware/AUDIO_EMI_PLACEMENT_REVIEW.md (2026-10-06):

# Audio integrity and EMI placement review — 27 September 2026

For the current hand-placed 120 × 100 mm primary and its routed J701 TVS escapes, see `MANUAL_PLACEMENT_REVIEW.md`. The pad-gap findings below describe the earlier 100 × 100 mm automatic baseline unless that review reports a correction.

The later [manual macro-placement candidate](MACRO_PLACEMENT_REVIEW.md) regroups the most sensitive analog/protection parts; [constraint disposition](CONSTRAINT_DISPOSITION_V2.md) proposes an effective shared-return impedance test in place of treating a 3 mm strip width as a sign-off. This file's routed-audio discussion remains a primary-board historical screen until the candidate's full paths are drawn.

**Historical baseline status: HOLD.** The earlier 100 × 100 mm board had no tracks, ground plane, power pours or stitching vias. Its analog/digital isolation, impedance, channel separation, noise and crosstalk could not be certified from placement. `PLACEMENT_100x100_BASELINE_AUDIT.json` is its reproducible pad-level screen. The new primary has an L2 GND zone and four TVS routes but remains mostly unrouted and unqualified for audio or EMI performance.

## Ground and return architecture to implement

The v1.1 Spec R07/R10 and Notes §9.3.2 specify **one GND net and an unbroken L2 ground plane**. Digital devices stay west, analog signal paths east, and power conversion south-west. Separation comes from component placement and controlled signal/return paths; no ground-plane split is permitted. L1 carries USB, clocks, I²S and audio; L3 carries regional power and slow controls, L4 slow analog/control over a stitched GND pour. The historical 100 × 100 mm baseline had no copper. The 120 × 100 mm primary now has one filled L2 GND zone, four TVS signal tracks, four GND stubs and four vias; the remaining architecture is still a routing requirement.

At the DAC, DGND, AGND and AGND_L/R need local L2 vias and the exposed pad needs five vias. Each fast signal must retain its L2 return beneath the entire route, including at the digital-to-DAC boundary. The earlier source rule prescribed a dedicated ≥3 mm L1 headphone-return strip with at least four L2 vias at each jack ground pin. The new [constraint disposition](CONSTRAINT_DISPOSITION_V2.md) requires an effective shared-impedance and crosstalk assessment instead; a wide L1 strip may supplement the continuous L2 plane. USB surge, LED-string and jack ESD currents must be kept away from quiet analog/reference returns. These are concrete topology checks for eventual copper, not connections inferred from the GND net name.

## Measured placement conflicts

The earlier audit measured minimum copper-to-copper gaps between *pad bounding rectangles* on high-impedance protection nets and clock nets. It found **15 nets below the Notes' 5 or 10 mm separation targets** on the historical 100 × 100 mm automatic board, versus 19 on the 100 × 80 mm comparison. The current 120 × 100 mm manual primary reports zero pad-gap findings; routed-copper review is still required. The earlier examples are:

| Sensitive pad/net | Clock pad/net | Pad gap | Required separation |
| --- | --- | ---: | ---: |
| R680.2 `N6_V3AG_A` | C624.1 `N6_MCK_BUF` | 0.96 mm | 5 mm |
| R678.1 `N6_V3R_A` | C624.2 `N6_PMP` | 1.02 mm | 5 mm |
| R939.1 `N6_VLLP` | TP715.1 `BCLK` | 1.20 mm | 10 mm |
| R947.2 `N6_TWRPN` | J703.2 `BCLK` | 1.79 mm | 5 mm |
| R932.2 `N6_LWRP` | J703.4 `SDATA` | 1.98 mm | 5 mm |
| U620.3 `N6_VLLN` | D609.3 `N6_PMP` | 3.08 mm | 10 mm |

Moving R940/R941 away from the MCLK corridor removed the previous 0.83 mm `N6_VLLN`–`N6_MCK_IN` pad conflict. In that historical baseline, C624, D609 and their 80 MHz surveillance network were scattered around the LPW/high-impedance group rather than clustered around U607. J703 was a DNF service header with copper pads and branches on high-speed I²S nets. A fixed-footprint search found no free position near U202; the nearest alternative was about 24 mm from the CPLD centre, adding a long clock branch. The owner subsequently removed J703's physical pads from the 120 × 100 mm primary while keeping the schematic DNF option; that board reports zero pad-level sensitive-to-clock gap findings.

The independent 0.20 mm grid probes estimate R204/R205/R206 to DAC BCLK/LRCLK/SDATA at 19.60/18.57/21.10 mm, within 25 mm individually. They omit the three signal branches and do not establish 3W spacing, length matching within 5 mm, uninterrupted L2 returns or guard copper. FAM_CLK probes at 3.25 mm, also individually. The USB pair has no valid probe result because the conservative rectangular obstacle model cannot resolve the fine-pitch connector escape; a real 0.235/0.15 mm, 90 Ω pair with permitted short neck-downs and zero vias must be routed and field-solver checked.

## Quiet DAC/I/V and headphone output

The owner-approved VSSOP U403/U404 gives four independent 0.20 mm DAC-to-I/V grid estimates of 6.37/5.73/4.01/4.81 mm, below a **provisional** 7 mm input limit. It does not yet show simultaneous routes, matched DAC output neighbourhoods, GND guards, the 2 mm no-digital-copper envelope, a four-way VREF star, or the <5 mm² Rf/Cf feedback loops. Feedback-part pad distances reach 6.85 mm in the present placement, so loop area needs an explicit copper-polygon calculation after routing. The model recheck and its limitations are in `IV_7MM_RECHECK.md`.

The headphone output rule calls for 0.5 mm L1 paths from each relay through the jack ESD pad to the jack contact, each ≤20 mm, L/R never interleaved and separated by ≥2 mm with grounded copper between. Moving K602/K604 closer to J701 improved their individual 0.5 mm probes to 12.74/7.94 mm while preserving the 1.5 mm soldering-iron clearance. K601→J702 probes at 19.50 mm. The same conservative probe still found `JACK_LP` K601→J701 at 20.48 mm, `JACK_RP` K603→J701 at 27.69 mm, and K603→J702 blocked. These are screening estimates, but the placement cannot be called routable. J701's second contact pads on the same nets also need local copper branches, and the jack sleeve return needs its own wide L1 path. Relay LED-current routing must keep ≥2 mm from the audio output copper.

## Route acceptance checks

1. Keep J703's service-header pads off the primary and resolve the MCLK test-point path. A no-stub X201→R203→DAC path probes at 9.60 mm; forcing TP711 through it has a 10.77 mm straight-line lower bound against the absolute 10 mm rule.
2. Preserve the primary's zero pad-level U607/C624/D609 versus LPW/3V3A gap findings while routing the clock monitor. Rerun the copper-gap audit after traces and pours are drawn. Keep MCLK and I²S above continuous L2 GND.
3. Route the four DAC inputs together with guards, VREF, feedback and supply decoupling; measure actual lengths, neighbourhood symmetry, feedback-loop copper area and the 2 mm digital exclusion. Recheck the provisional 7 mm model envelope with extracted capacitance.
4. Route every relay-to-ESD-to-jack output with at least 0.5 mm pad neck-downs and show length, L/R separation, ESD return and actual shared-return impedance. The earlier 20 mm output target is replaced by a full conductor/load/crosstalk budget in the [constraint disposition](CONSTRAINT_DISPOSITION_V2.md); report actual copper length and width.
5. Fill and inspect L2/L4, place the local ground/stitch vias, run full KiCad DRC, review return-current continuity and near-field/crosstalk risk, then validate noise, THD+N, output impedance and channel separation on hardware against the Spec's limits.

Manufacturer guidance is consistent with the source documents' continuous return-plane approach: [TI's mixed-signal grounding note](https://www.ti.com/lit/an/slyt512/slyt512.pdf) and [Analog Devices' mixed-signal grounding article](https://www.analog.com/en/resources/technical-articles/2022/07/16/11/32/successful-pcb-grounding-with-mixedsignal-chips--follow-the-path-of-least-impedance.html). The numerical distances and hold decisions above come from the project's design notes and KiCad geometry audit.

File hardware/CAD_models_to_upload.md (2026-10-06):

# Exact CAD models still useful

The command-line JLCPCB KiCad loader supplied 42 LCSC CAD entries, including TI TLV3402IDGKR, TI SN74AUP2G17DCKR and onsemi MMBT3904LT1G. Manufacturer drawings supplied the 2D land dimensions for D102, X201–X203, C631–C634, K601–K604 and the connector slot corrections. All assigned footprints pass the symbol-pin/pad-number check. **No CAD upload is needed to continue schematic capture.**

The boards now resolve 3D bodies for every component footprint; see
`3D_MODEL_REVIEW.md`. The user-supplied exact Toshiba LF1 STEP is integrated.
No additional CAD upload is needed for the KiCad 3D view. These manufacturer
models would improve fidelity where a generic package or body envelope is used:

| Designators | Exact MPN | Optional upload |
| --- | --- | --- |
| X201 | Kyocera KC2520K80.0000C1GE00 | Manufacturer STEP |
| X202 | NDK NZ2520SDA-49.152MHZ-NSC5083D | Manufacturer STEP |
| X203 | NDK NZ2520SDA-45.1584MHZ-NSC5083D | Manufacturer STEP; X202 geometry may be reused after checking |
| C631–C634 | Panasonic ECH-U1H224GX9 | Manufacturer STEP |

A 3D body cannot replace the G-3 physical sample overlay or the remaining
pad-number checks. D102 already displays with KiCad's SMC package STEP.

## Physical and electrical decisions still required

- **J101:** The GCT USB4105 drawing has 12 PCB solder lands, four shell stakes, and two locating holes. JLCPCB C3020560 CAD splits four paired solder lands into separate pad IDs. The project footprint follows GCT's composite 12-land map. The owner reports both G-1 samples match but waived the raw log; G-3 physical overlay remains open.
- **J701:** Parts List v0.9 carries the approved 12-pad G-Switch map. The custom footprint keeps the maker slots and pad centres, enlarges copper for ≥0.31 mm worst ring under JLC's +0.13 mm slot tolerance, and adds two NPTH peg holes. Pads 11/12 are soldered mounting tabs with no-connect flags. The owner reports two-sample G-2 continuity (tabs common with bushing and isolated from sleeve); G-3 still checks the physical overlay and enlarged copper.
- **J702:** Parts List v0.9 carries the HRO maker map: pins 1/2 GND, 3 `JACK_RP`, 4 `JACK_LP`, and 5/6 break contacts with no-connect flags. The custom footprint keeps the slots and pad centres, enlarges copper for a 0.30 mm ring, and adds two NPTH peg holes. The owner reports both samples match the TRS contact and break behavior and waived the G-2 raw log; G-3 overlay and G-6 slot soldering remain open.

Do not release PCB manufacturing or PCBA data from the provisional connector mapping.

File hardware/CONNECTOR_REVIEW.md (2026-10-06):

# Connector pin-map review (capture v1.1)

The schematic follows Parts List v0.9 for connectivity. J701 and J702 use the maker-drawing maps recorded in that workbook. The owner reports two-sample G-1/G-2 continuity checks and explicitly waived their raw measurement log on 27 September 2026; these are owner-accepted results, not independently evidenced passes. G-3 overlays remain open before routing.

| Ref | Finding | Current capture | Required action |
| --- | --- | --- | --- |
| J101 | The [GCT USB4105 drawing](https://mm.digikey.com/Volume0/opasdata/d220001/medias/docus/5492/USB4105.pdf) gives 12 PCB solder lands: A1/B12, A4/B9, A5–A8, B1/A12, B4/A9, B5–B8; four shell-stake slots; and two 0.65 mm locating holes. JLCPCB C3020560 CAD splits the four shared lands into separate touching pads, giving 16 signal-pad IDs. | Workbook composite pad labels and nets are retained. `DAC_HPA:J101_USB4105-GF-A_12lands_4stakes` is a provisional footprint from the GCT layout, with all 16 named pads plus two unnumbered locating holes. Its four plated shell slots currently have no F.Paste apertures. | G-1 two-sample result is owner-accepted without raw log; G-3 1:1 overlay remains, then confirm pin-in-paste process and apertures with JLCPCB at G-6. |
| J701 | The [G-Switch GT-3321667P-01 drawing](https://atta.szlcsc.com/upload/public/pdf/source/20210324/C2762984_895B09C838D8EF4D4228BF97BFC29634.pdf) maps pad 1 to GND, 2/3 to R−, 4/5 to R+, 6 to L−, and 7/8 to L+. Pads 9/10 are switch/detect contacts; 11/12 are mounting tabs. | Parts List v0.9 carries the approved 12-pad map. Pads 9–12 have no-connect flags, yet 11/12 retain solder lands. `DAC_HPA:J701_GT-3321667P-01_maker_slots` keeps the maker's 0.50 × 1.40 mm plated slots and pad centres, adds two Ø1.20 mm NPTH peg holes, and uses owner-approved 2.15 × 1.25 mm copper pads. | The owner reports both samples: tabs 11/12 short to each other and bushing, open to sleeve; switch pads 9/10 short without plug, open inserted, changing during insertion/removal while isolated from audio pads 1–8 in both end states. G-2 raw log waived; G-3 checks revised copper, slots, holes and pegs. |
| J702 | The [HRO PJ-332A-6A drawing](https://datasheet.lcsc.com/datasheet/pdf/ae194aee17b3d1e2f10994958208a91f.pdf?productCode=C2848643) maps pad 1 to sleeve, 2 to ring 2, 3 to ring 1, 4 to tip, and 5/6 to break contacts. | Parts List v0.9 assigns 1/2 to GND, 3 to `JACK_RP`, 4 to `JACK_LP`, and 5/6 to no-connect. **Never connect 5/6 to GND:** with no plug, they close to the driven contacts. `DAC_HPA:J702_PJ-332A-6A_peg_holes` keeps the 0.60 × 1.50 mm slots and pad centres, enlarges the copper on pads 1/2 to 2.25 × 1.35 mm, and adds two Ø1.20 mm NPTH peg holes. | The owner reports both physical samples match the TRS contact and break maps; G-2 raw log waived. TRRS use is excluded. G-3 overlays revised copper, slots and pegs. JLCPCB confirms slot soldering at G-6. |

The workbook's internal clean check and KiCad ERC confirm capture consistency; neither verifies a connector's physical contact map. No manufacturing data follows from the provisional connector assignments.

## J701 correction approved and captured

| JLC/G-Switch pad | Published contact name | Captured DAC-HPA net |
| --- | --- | --- |
| 1 | GND | `GND` |
| 2, 3 | R− | `JACK_RN` on both |
| 4, 5 | R+ | `JACK_RP` on both |
| 6 | L− | `JACK_LN` |
| 7, 8 | L+ | `JACK_LP` on both |
| 9 | SWITCH | No-connect flag |
| 10 | DETECT | No-connect flag |
| 11, 12 | `ep` in JLC symbol; mounting tabs in maker drawing | No-connect flags; soldered lands; owner reports both samples short to each other and bushing, open to sleeve pad 1 |

The map is now present in Parts List v0.9 and captured without a J701 override. The owner reports two-sample checks of pads 9/10 and waived the raw G-2 log before schematic freeze.

## Slot-pad copper ring decision

Design Spec v1.1 left the maker-pad copper rings open: J701 0.25 mm nominal and 0.20 mm at the source's +0.10 mm slot tolerance; J702 0.20 mm. On 27 September 2026, the owner chose to enlarge **copper only** before G-3. JLCPCB's published plated-slot tolerance is +0.13/−0.08 mm, so the review footprints use J701 2.15 × 1.25 mm copper around unchanged 1.40 × 0.50 mm slots and J702 pads 1/2 2.25 × 1.35 mm around unchanged 1.50 × 0.60 mm slots. Both have ≥0.31 mm worst ring at the +0.13 mm size tolerance. Pad centres and locating holes stay fixed. The closest J701 copper-to-copper gap is 0.25 mm between pads 7 and 10. `verify_critical_footprints.py` checks the pad dimensions; G-3 must still verify the physical overlay and JLCPCB DFM must accept the revised lands and gap. The ring calculation does not include slot-to-copper registration error. [JLCPCB's capabilities page](https://jlcpcb.com/capabilities/pcb-capabilities) lists a multilayer 1 oz PTH-ring absolute minimum of 0.15 mm and recommends 0.20 mm; this design retains the separate 0.30 mm target and uses ENIG, pending project-specific DFM review.

## J702 sample check reported by the owner

The owner reports that **both J702 samples** show pads 3–5 and 4–6 closed with no plug and open with the intended TRS plug fully inserted. With that plug inserted, pads 1/2 contact the sleeve, pad 3 the right ring, and pad 4 the left tip, with no other pad-to-contact connections. On both samples, a slow insertion/removal check found only the expected break-pair transitions; pads 5/6 did not touch the sleeve or the opposite audio channel. Neither sample has an accessible metal shell to probe. The owner decided that J702 supports **TRS plugs only**, so a TRRS contact test is outside the accepted use. The owner waived sample IDs, raw DMM readings and a signed table for G-2; these results are accepted for layout planning without independent evidence.

The owner also reports that **both J701 samples** match the intended 4.4 mm plug contacts: pad 1 sleeve, 2/3 R−, 4/5 R+, 6 L−, and 7/8 L+. The owner meter-tested both samples: pads 11↔12 and each pad↔metal bushing are short, while pads 11/12↔sleeve pad 1 are open; pad 9↔10 is short with no plug, open when fully inserted and changes during slow insertion/removal; each remains open to audio pads 1–8 in both end states. This replaces an earlier documentation-only inference for pads 9/10. Pads 9–12 remain no-connect in KiCad, and the mechanical bushing is not deliberately tied to audio GND by those pads. The owner waived sample IDs, raw readings and the signed G-2 table for layout planning.

## G-2 continuity protocol retained for reproducibility

The original protocol calls for two samples of each jack, labelled physical terminals using the JLC footprint top view, and a signed continuity table with no plug, fully inserted and slow insertion/removal. For J702, the intended TRS plug is used; TRRS use is excluded. The owner-reported results above are now the accepted basis for the provisional pin map, with the raw table waived. Any future evidence of a different contact or common pair requires a net/footprint correction before routing or fabrication.

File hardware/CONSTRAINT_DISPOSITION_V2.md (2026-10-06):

# Routing and fabrication constraints for the integrated-audio study

**Status:** engineering review policy for the 120 × 100 mm candidate. The [DAC/core checkpoint](DAC_CORE_ROUTE_STUDY.md) and [audit](DAC_CORE_ROUTE_AUDIT.json) supersede this document's earlier DAC/CPLD route measurements. The current board has 855 track/via items (143 vias), 864 full ratsnest links, 499 DRC-unconnected items and zero DRC violations; current geometry checks find zero exact/near-90° bends, zero bbox overlaps and zero classified JLC spacing findings. It remains partial copper and is not a manufacturing release. The four-layer stack keeps one continuous L2 GND plane; analog/digital separation is by placement and controlled current paths, with no ground-plane split.

| Topic | Disposition for the next route trial | Evidence still needed |
| --- | --- | --- |
| USB D+/D− | Keep 90 Ω differential target, L1 and no vias. `USB_DIFF` now sets 0.235 mm nominal width, 0.15 mm gap and 0.15 mm clearance; short local 0.15 mm neck-downs remain allowed. | Fix JLC stack-up/copper/mask and use a field solver, then check actual width, spacing, skew and continuous L2 return. KiCad netclass values are router settings, not an impedance proof. |
| MCLK | Keep ≤10 mm and controlled probe loading. The hand-drawn L1 X201→R203→TP711→U301 path is **8.381 mm** total (1.832 + 6.549 mm), with no vias. R227's oscillator-side branch is 1.509 mm and has a local L2 GND via; R665→U607 pin 2 is connected. DNF R703 remains unrouted. | Extract/load the complete clock network, inspect L2 return and oscillator supply loop, then measure edge shape, duty and DAC/monitor behavior. The geometric route pass is not a signal-integrity sign-off. |
| I²S | Keep the 25 mm path target and ±5 mm matching screen, with no unnecessary meanders. The drawn U202→R204/R205/R206→U301 BCLK/LRCLK/SDATA paths measure **22.213/22.324/22.879 mm**, with **0.666 mm** spread, on 0.15 mm F.Cu and no vias. Their central parallel lanes have 0.45 mm copper-edge gaps and sampled L2 support. | Complete remaining branches and controls, then check edge-rate timing, actual branch loading and the L2 return. Path and spacing screens do not establish signal integrity. |
| Local clock/power bypass | C213/C214/C215→U202 pins 32/16/6 measure **1.103/2.056/3.057 mm**. U302 VIN→C301 is **0.875 mm**, OUT→C302 **2.131 mm**, and OUT→FB302 **5.025 mm**. U303→DAC 1V3 PWR is connected at **25.393 mm with two vias**. C622 at **(108.65, 105.50)** has 4.615 mm U604.8→C622.1 and 1.020 mm C622.2→GND-via paths, with saved L2 beneath both; its global 3V3D feed remains open. Thirty-five local GND pads reach L2. | Finish upstream ferrite/source rails, the global 3V3D feed and remaining bypass routes; extract supply/return impedance and verify under load. These are local 2D copper measures, not rail qualification. |
| VBUS/5V_SYS High-mode feeds | Retain the ≥1.0 mm power-trunk rule. The two 0.60 mm J101 VBUS lands may launch one ≥0.50 mm, ≤2.0 mm L1 neckdown each. U102 pins 1/6 and U504 pin 6 may launch one ≥0.30 mm, ≤1.2 mm L1 neckdown each before widening. The [pad-escape audit](audit_power_pad_escapes.py) checks actual pad endpoints and lengths; the current board has no such escapes yet. | Route the complete feeds, then calculate worst-case High-mode voltage drop, heating and attach/inrush behavior from actual copper and obtain JLC DFM acceptance. Courtyard-local DRC exceptions alone do not bound neckdown length. |
| Exposed pads and nearby vias | The current board has **143 vias**; two U202 and five U301 exposed-pad vias are flagged filled and capped. The via-pad process audit still finds 45 unfilled via-to-SMT-pad sites closer than 0.35 mm, zero unfilled pad overlaps and zero unfilled gaps below 0.10 mm. | Obtain JLC mask/process review for the 45 sites and order-specific acceptance, pricing, stencil-aperture and assembly confirmation for via-in-pad. U401/U402 output-amplifier exposed-pad thermal routing remains open. |
| DAC → I/V | Keep the owner-approved **provisional** ≤7 mm bound. The [explicit schematic ECO](FUNCTIONAL_ECO_2026-09-28.md) assigns DACL/DACR to physical amplifier B and DACLB/DACRB to A. No-via F.Cu routes measure **DACL 4.294, DACLB 6.030, DACR 6.837, DACRB 4.786 mm**; DACR has **0.163 mm** margin. At 0.01 mm route samples and offsets 0, ±0.05, ±0.10 mm, saved filled L2 GND is directly below all four input traces. Central VREF copper reaches **14.422 mm**. | Extract summing-node capacitance against the 6 pF model envelope, verify guards/2 mm digital-copper separation, VREF noise and actual return impedance, then test step response. Sampled L2 support is not an extracted return path. |
| Bypass/feedback | Replace “every capacitor within 1 mm” with a short supply-and-return **loop** requirement for HF bypass, local regulator output capacitors and directly placed feedback components. Bulk reservoirs may sit behind local HF parts. U403/U404 R423–R426/C417–C420 feedback copper is drawn; its maximum **projected 2D centreline** area is **4.875 mm²** with straight part/pad closures. DACL's U403→C417 feedback branch still lacks direct L2 beneath **1.9426 mm** of centreline, **0.0597 mm** more than the like-for-like prior committed baseline. | Extract vertical and return-current loop area, pad-to-via/plane paths and output-capacitor stability requirements; test I/V stability. The plan-view area is not a 3D or stability proof; the DACL return detour remains on HOLD. C423/C426 courtyard gaps of **0.150–0.194 mm** need assembly review. |
| I/V → output-amplifier input T | Four I/V output nets now reach all eight first T resistors; the longest feed is **47.752 mm** (`N4_IVR_P`→R409). The right `N4_IVR_N` feeds to R411/R413 measure **27.289/41.648 mm**. All eight local T triplets have F.Cu copper to U401/U402 inputs with L2 shunt returns. Routed local maxima are 6.53/7.25/8.29 mm (Rin→Rout/capacitor→Rout/Rout→amplifier). | Extract the long right-side cross-layer feed capacitance, coupling and return path, then test stability and loaded behavior. R444/C433 avoid T/ground crossings; inspect C437/J701/K602 clearance and via mask in JLC DFM. Copper connectivity does not prove analog performance. |
| U501 local charge pump and feedback | Switching capacitors, VIN, VPOS/VNEG caps, dividers and GND-to-L2 connections have local copper. Permit only three bounded **0.20 mm** `5V_ANA_F` WSON pin escapes at U501 pins 12/3/8 (1.050/0.860/1.146 mm); the remaining feeder stays ≥0.8 mm. C510/C511 GND vias sit **8.160/6.767 mm** from U501's GND via by straight L2 spacing. A B.Cu feeder detour removes projected overlap with F.Cu `N5_FBP` (track **0.1663→0 mm²**; unshielded pad-inclusive **0.0861→0 mm²**) while VIN3→C507 rises to **6.014 mm**, below its 6.1 mm bound. | Extract switching supply-and-return current loops and noise; the original power-via antipad remains and via spacing is not a return-current path length. Complete upstream input and main amplifier VPOS/VNEG distribution, then test regulation and stability. |
| U609/U610 protection timer branches | All 12 named-pad timer branches pass the ≤8 mm screen without timer-net vias. U609 LP C/Q/R routes are **6.089/5.340/4.943 mm** and LN routes **6.038/5.814/6.685 mm**; U610 LP is **6.442/7.607/1.789 mm** and LN **7.177/7.712/7.787 mm**. C631/C632/C633/C634 GND returns reach L2 in **3.580/3.656/2.650/2.650 mm**. C635/C636 U609 VPOS/VNEG local bypasses connect through 11 vias (six GND, three VPOS, two VNEG). | Complete upstream rail feeds and U609 VT/control escapes; check leakage, cleaning/guarding and coupled clock noise. Timer copper connectivity is not a powered or EMI qualification. |
| U605 readback and timer clearances | U605/R675/R676/R679/R677 moved **1.2 mm** left and C625 moved near R666, clearing six measured 5 mm I²S/protection gaps. | Recheck the actual U605/U610 corridor and local mask/solder access at board review; timer signal branches pass, while U609 VT/control escapes remain open. |
| Film-cap bypass clearance | C638 uses a short two-via L3 VNEG bridge to keep timer routes clear. C636 has a pair-specific **0.60 mm** side-courtyard gap to C631/C632. All four film capacitors C631–C634 retain at least **1.5 mm** north/south solder approach (minimum **3.045 mm**) per the [film solder-access audit](INTEGRATED_AUDIO_FILM_SOLDER_ACCESS_AUDIT.json). | Review the exception against the actual film-cap body and soldering process at G-3/JLC order DFM. It is a project-specific allowance, not a published JLC package-pair limit. |
| Sensitive nets versus clocks | The 10 mm clearance covers high-value `N6_VLL*` and `N6_VOR*` divider nodes. The 5 mm clearance covers analog `N6_V3*` nodes, timer `N6_TW*`/`N6_LW*` nodes and the six OR analog nodes, including `N6_ORTB`/`N6_ORQC`. Four U621 buffered logic readbacks (`N6_V3AG_{A,B}_{BUF_OUT,MCU}`) are exempt from this analog keepout. The placement audit and KiCad DRC now classify the same nets. | Route these branches with L2 return, inspect coupling and verify the supervisor readback thresholds with clocks active. The spacing rule is a susceptibility screen, not a complete EMI qualification. |
| Headphone conductors | Treat the old blanket 20 mm length as a screening target. U401/U402 VSON output pads have 0.50 mm pitch and 0.30 mm pad width: a 0.50 mm trace at the pad violates the 0.20 mm clearance rule. Permit an explicit **0.25 mm local pad escape for at most about 1 mm**, then widen to ≥0.50 mm and trial 1.0–1.5 mm trunks where room permits. Keep `LEG_*` and `JACK_*` on L1. The [integrated audio study](INTEGRATED_AUDIO_ROUTE_STUDY.md) trials four low-impedance `N4_*_OUT` L4 trunks with eight signal vias and all four jack paths; its custom DRC also requires 2 mm F.Cu left/right clearance for pre-link `N4_*_OUT` against the opposite channel. K601/R417 shifted 2.4 mm with rerouted output copper; this remains review-only. | A 0.25 mm neck at a centred pad leaves 0.225 mm clearance to its neighbour, just 0.025 mm over the current rule. Review JLC process tolerance, reserve the L3/L4 return corridor, then extract the complete jack output-impedance budget, amplifier stability and L/R coupling from actual copper. With the [review-only 1 mΩ-max output links](OUTPUT_LINK_BOM_ECO.md), the 4.4 mm model's conditional 20 kHz worst paths are 0.3990/0.3864 Ω (L/R), assuming the same ≤0.5 Ω limit applies there. The 3.5 mm 0.2255/0.2188 Ω signal-only lower bounds omit sleeve return. Jack-contact maxima, L3/L4 returns and measured R-15 remain open. |
| Headphone return | Keep L2 continuous and connect jack sleeves locally with robust vias. Assess effective common impedance instead of treating a ≥3 mm L1 strip as proof of isolation. An L1 strip can supplement L2, without cutting the plane. | Extract or measure common resistance/inductance including vias and contacts, and measure loaded crosstalk. Target ≤5.7 mΩ shared impedance for −75 dB into 32 Ω in the simple resistive estimate. |
| J701/J702 ESD | Keep all six TVS branches under the provisional ≤4.2 mm routed limit and system ESD gate. The [named-pad copper audit](LOCAL_TVS_ROUTE_AUDIT.json) measures the current J701 paths at 3.83–4.03 mm and J702 paths at 3.255/3.864 mm. A generic KiCad `length` rule reported false excesses when a JACK net acquired paired contacts and relay branches; the six limits are now enforced by `audit_local_tvs_paths.py` in CI. | Complete [J702 local TVS review](J702_LOCAL_TVS_OPTION.md): discharge/ground return, capacitance/leakage/nonlinearity, JLC assembly, full routes and IEC system ESD. |
| Thermal/density | Treat 15 mm heat separation and 60% room fill as warning screens. The current study has 0.150–0.194 mm courtyard gaps near C423/C426 despite zero bounding-box overlaps. | Evaluate losses, thermal copper and access on the real placed/routed board; obtain JLC order DFM for the tight I/V group and retain required body and solder-access clearances. |

## KiCad and JLCPCB geometry reconciliation

`DAC_HPA.kicad_pro` now uses a Ø0.60/0.20 mm default signal via and a Ø0.80/0.40 mm power preset; both give a 0.20 mm nominal ring. A separate `FINE_ESCAPE` class offers 0.15 mm width/clearance when deliberately assigned during fanout. No 0.10 mm track is approved by the current project floor. The integrated board's U501 courtyard rule permits only its three short 0.20 mm VIN escapes below the usual 0.8 mm `5V_ANA_F` width; the checker bounds each branch. The scoped J101/U102/U504 VBUS/5V_SYS exceptions above preserve ≥1 mm trunks and are checked by [a separate pad-level audit](audit_power_pad_escapes.py). The jack's elongated plated-slot ring target ≥0.30 mm is a **different** mechanical land rule and is not imposed on every signal via. [Routing-policy check](verify_routing_policy.py) verifies the settings and actual USB/power/audio net assignments.

The published [JLCPCB multilayer capability limits](https://jlcpcb.com/capabilities/Capab) include 0.09/0.09 mm trace/space for 1 oz and a 0.15 mm absolute / 0.20 mm recommended PTH ring. The project retains 0.15 mm track/clearance and 0.20 mm via-ring design floors. The [JLC impedance calculator](https://jlcpcb.com/help/article/user-guide-to-the-jlcpcb-impedance-calculator) requires the quoted stack-up and spacing; no one width guarantees 90 Ω for every order. [JLC assembly terms](https://jlcpcb.com/help/article/terms-and-conditions-of-jlcpcb-assembly-service) and its package-spacing table still require an order-specific review, particularly for edge connectors and plated slots.

At 50 °C, the calculation package uses 0.551 mΩ per square for 35 µm copper. Thus 20 mm × 0.5 mm and 60 mm × 1.5 mm are both about 22.0 mΩ, while 50 mm × 1.0 mm is 27.5 mΩ. A 1 mm × 0.25 mm VSON escape is about 2.20 mΩ, approximately 1.10 mΩ more than a 1 mm × 0.5 mm segment. These are **DC resistance comparisons only**. A standalone 40 mm × 3 mm strip is about 7.35 mΩ before vias, beyond the simple 5.7 mΩ common-return ceiling; the real L2 plane contributes parallel paths and requires extraction/measurement.

The source Spec/Notes and older reviews still state some superseded 20 mm/3 mm/1 mm numerical instructions. This table is the routing-study disposition; their controlled document revision remains open before manufacturing freeze. Physical G-3/G-4 and JLC process gates do not change.

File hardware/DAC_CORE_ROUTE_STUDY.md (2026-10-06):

# DAC core and CPLD clock routing checkpoint

**29 September 2026 · Review only · 120 × 100 mm, four layers.** The
[integrated PCB](DAC_HPA_120x100_INTEGRATED_AUDIO_STUDY_ONLY.kicad_pcb) is
the current editable partial routing candidate. Every new component position
and copper waypoint was chosen manually and recorded in the
[replay manifest](INTEGRATED_AUDIO_MANUAL_DELTA.json). It has **544
footprints, 250 named nets, 855 track/via items (143 vias), zero KiCad DRC
violations, 499 DRC-reported unconnected items and 864 full ratsnest links**.
The current manual delta records 138 moves, eight removed source-copper items and 828
added copper items. The
[critical-route audit](DAC_CORE_ROUTE_AUDIT.json) is the numeric evidence;
these partial-board results do not authorize a PCBA order.

## What moved and what now has copper

- All 12 U609/U610 named-pad timer signal branches now pass the ≤8 mm limit
  without timer-net vias. U609 LP C/Q/R measures **6.089/5.340/4.943 mm**
  and LN **6.038/5.814/6.685 mm**; see the integrated route study for U610
  lengths. C631/C632 GND returns reach L2 in
  **3.580/3.656 mm**. C635/C636 local U609 VPOS/VNEG bypasses connect through
  11 vias (six GND, three VPOS, two VNEG); upstream rails and U609 VT/control
  escapes remain open.

- C622 moved to **(108.65, 105.50, 0°)**. Its 0.30 mm F.Cu path from
  U604.8 to C622.1 is **4.615 mm**; C622.2 reaches a Ø0.7/0.3 mm GND via at
  **(110.15, 105.50)** in **1.020 mm**. The saved continuous L2 GND plane
  supports both paths. The global 3V3D feed remains open.

- U202 was rotated **270° in place**. Its physical pins 20/19/18 now face
  east in SDATA/LRCLK/BCLK order, matching U301's west-edge pin order.
  R204/R205/R206 and TP715/TP716 were hand-regrouped below it. TP712 now
  lies on the R215→U202 FAM_CLK path. C214 was moved to U202 pin 16 and
  given its own L2 GND via. U302/C302 shifted west to reserve three straight
  I²S lanes. C213→U202 pin 32, C214→pin 16 and C215→pin 6 are locally routed
  at 1.103/2.056/3.057 mm. Two U202 exposed-pad GND vias are flagged filled
  and capped. The schematic pin map and resistor values did not change.
- The five U301 100 nF capacitors C305–C309 now form a 1.45 mm pitch row
  with supply pads facing their matching DAC pins. Four 0.25 mm north-side
  source paths enter the row through 0.75 mm gaps between GND via copper.
  C303/C304 and C439/C440 were regrouped above them, and R301/R302 now
  face their analog output rails south. U301's nine perimeter GND pins join
  its exposed pad; **five 0.70/0.30 mm GND vias inside the EP are explicitly
  filled and capped** in KiCad. Across U202 and U301, seven EP vias are
  explicitly filled and capped. C312 1 µF moved beside C309, while C310
  2.2 µF remains at U303's output.
- U303, C311, C310 and its R533/R534 feedback divider now form a local
  regulator group. VIN1/VIN3, the output capacitor, divider, and their
  GND connections to the single L2 polygon have drawn copper. The L3 portion
  of the U303→DAC 1V3 link is **25.393 mm**, with two through vias. R305 was parked
  away from this group; its final reset pull-up placement and route remain
  to be reviewed with DAC_RESETB.
- Local supply-cap routes include U302 VIN→C301 at **0.875 mm** copper
  contact, U302 OUT→C302 at **2.131 mm**, and U302 OUT→FB302 at **5.025 mm**.
  Thirty-five DAC/CPLD/LDO local GND pads connect to L2 in the route audit.
- Filtered DVCC and VCCA use two short **L3** feeders from FB301/FB302
  toward the bulk capacitors, underneath continuous L2 GND. Their F.Cu
  escapes stay outside the I²S passage. The ferrites' upstream 3V3D/3V3A
  pins remain unconnected to their upstream source rails; local U303-to-DAC
  1V3 copper is now connected as measured above.

## Critical-route measurements

| Path | Current drawn result | Screen |
| --- | ---: | ---: |
| U202→R204→U301 BCLK, including resistor pad span | 22.213 mm | ≤25 mm |
| U202→R205→U301 LRCLK, including resistor pad span | 22.324 mm | ≤25 mm |
| U202→R206→U301 SDATA, including resistor pad span | 22.879 mm | ≤25 mm |
| I²S length spread | 0.666 mm | ≤5 mm |
| X201→R203→U301 MCLK | 8.381 mm (1.832 + 6.549) | 2/8/10 mm segments/total |
| R215→U202 FAM_CLK | 3.039 mm | Review, no separate limit |
| MCLK-to-DACR F.Cu track edge gap beyond U301 courtyard | 2.1468 mm | Provisional ≥2 mm |
| MCLK-to-DACR track edge gap inside the U301 fanout | 1.6264 mm | Provisional ≥1 mm |

The I²S source and output traces use **0.15 mm F.Cu with no vias**. Their
parallel central lanes have **0.45 mm copper-edge gap = 3 × trace width**
at y = 74, 76, 78 and 80 mm. Pin and component fanouts have their own
package-clearance limits. The saved filled L2 polygon lies directly below
MCLK, FAM_CLK and all six I²S net segments at 0.01 mm centreline samples
and ±0.075 mm offsets. This screen does not extract return impedance or
prove digital timing. The eight source/post segments coexist with the
regrouped DAC supply and L3 feed copper under KiCad's current rules.

The Notes contain both a 2 mm DAC/digital separation paragraph and a 1 mm
MCLK-specific clearance. This review uses **2 mm outside U301's fixed
package courtyard and 1 mm for F.Cu fanout tracks inside it**. The
[audit](DAC_CORE_ROUTE_AUDIT.json) clips the tracks at that boundary and
also checks outside MCLK pads against DAC-input tracks. The closest
external pad-to-track gap is 2.1329 mm. A different interpretation of the
Notes needs a controlled constraint update before routing freeze.

The four DAC-to-I/V input lengths are now
**4.294/6.030/6.837/4.786 mm** for DACL/DACLB/DACR/DACRB, all below the
owner-approved provisional 7 mm limit. DACR retains **0.163 mm** of that
screen. Their sampled L2 support remains complete. The separate DACL
feedback branch still has **1.9426 mm without direct L2 beneath its
centreline**; its three-dimensional return and I/V loop stability remain
unqualified.

## Electrical and manufacturing holds

1. **DVDD capacitance:** The fitted C312 is 1 µF nominal. [ESS's ES9018K2M
   datasheet](https://www.esstech.com/wp-content/uploads/2024/09/ES9018K2M-Datasheet-v3.7.pdf)
   calls for a local nominal 2.2 µF DVDD decoupler that retains at least
   1 µF at 1.2 V over operating temperature. C310 is 2.2 µF at U303 and
   must remain a local LDO output capacitor. Review a C312 2.2 µF
   schematic/BOM ECO with verified effective-capacitance data. The
   [LTspice/MATLAB passive sweep](sim/README.md) compares assumed loop
   inductances; it is not a measured supply impedance or audio result.
2. **Via and EP assembly:** [JLCPCB's via-covering guidance](https://jlcpcb.com/help/article/pcb-via-covering)
   treats filled/capped vias as suitable for via-in-pad, and asks the
   customer to identify them in the order. The current board has 143 vias;
   two U202 and five U301 EP vias are flagged filled/capped in the PCB. The
   [via-pad process audit](INTEGRATED_AUDIO_VIA_PAD_PROCESS_AUDIT.json)
   identifies 45 unfilled via-to-SMT-pad sites closer than 0.35 mm. It finds
   zero unfilled SMT-pad copper overlaps and zero unfilled gaps below 0.10 mm;
   those 45 sites still need JLC mask/process review. Confirm via-in-pad process,
   price, stencil aperture and QFN solder result in the order preview; DRC
   does not establish acceptance.
3. **Incomplete power and return:** the listed U202 bypass and U302 local
   capacitor paths, and the U303→DAC 1V3 trunk, are drawn. Upstream ferrite
   source feeds and U401/U402 main VPOS/VNEG distribution remain open, as do
   the U401/U402 output-amplifier exposed-pad thermal routes. The 35 audited
   local GND-to-L2 connections do not mean every fitted GND pad is routed.
   Co-route and extract the L3/L4 audio returns before judging hum, RF pickup,
   crosstalk or output impedance.
4. **Clock/capture function:** The U205→R215 clock source, R228–R230
   capture taps, CPLD SPI/capture links, reset controls and most of the
   digital network remain open. Check each branch's stub/loading, final
   edge shape and timing. The all-rate post-CPLD guard is still a separate
   functional ECO with absent verified firmware/RTL.
5. **Release:** USB routing/90 Ω stackup, protection timer/reset branches,
   DACL feedback return, I/V and output-stage stability, G-3/G-4 physical
   gates, system ESD, EMI, measured jack impedance and audio/RF/hum tests
   remain open. There are 864 full ratsnest links; zero DRC violations and
   499 DRC-reported unconnected items describe partial-board status only and
   do not authorize Gerber/CPL/PCBA release.

The separate [Freerouting probe](FREEROUTING_PROBE.md) rejected the bulk
session. Its input copy had 753 track/via items; the imported session had
2,460, but also 53 reported violations and lost named KiCad custom rules.
Only two reviewed low-speed local paths were adopted afterward; the bulk
session did not replace the board. Its historical 962→499 unrouted count
uses a different connectivity definition from the current 864 ratsnest links
and 499 DRC unconnected items.

## Review visually from the command line

```sh
KICAD_CLI=/Applications/KiCad/KiCad.app/Contents/MacOS/kicad-cli \
  bash hardware/make_review_views.sh /tmp/dac-critical-review \
  hardware/DAC_HPA_120x100_INTEGRATED_AUDIO_STUDY_ONLY.kicad_pcb

/Applications/KiCad/KiCad.app/Contents/Frameworks/Python.framework/Versions/Current/bin/python3 \
  hardware/check_dac_core_routes.py \
  hardware/DAC_HPA_120x100_INTEGRATED_AUDIO_STUDY_ONLY.kicad_pcb
```

Zoom the exported F.Cu and L2 SVGs together around x = 78–95, y = 62–85 mm.
Inspect U202→R204–R206→U301, TP712/715/716, the C305–C309 returns, the
five EP vias, and the L3 DVCC/VCCA routes. The [general visual workflow](PCB_CLI_VISUAL_REVIEW.md)
also exports mirrored B.Cu and a 3D GLB. State every finding by reference,
pad, layer and board coordinate.

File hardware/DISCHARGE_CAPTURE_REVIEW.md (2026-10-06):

# Discharge capture and calculation review · 29 September 2026

**Release state: HOLD.** This is a source-to-model discrepancy report for the
current review-only schematic and PCB. It does not change the owner-supplied
Parts List, Spec, Notes or calculation ZIP. Use the machine-readable
[capture audit](DISCHARGE_CAPTURE_AUDIT.json) to see the exact fitted parts and
capacitor inventory read from the v0.9 workbook.

## Captured circuit versus the calculation package

| Item | Captured source / latest design intent | Calculation package v1.1 |
| --- | --- | --- |
| U504 EN pin 4 | `AUD_EN` | `AUD_EN` |
| U303 EN pin 3 | `3V3D`, tied to its IN | `c06_discharge.py` and `c12_u303_tlv758p.py` assume `AUD_EN` |
| 1V3 discharge | R530/Q506 can load U303 while 3V3D is falling | C06 assumes U303 is already disabled, then quotes 1V3 <0.1 V by 0.134 ms |
| Current prose | [Spec v1.1](../doc/DAC_HPA_Design_Spec_v1.1.docx) §3.2 deliberately ties EN to 3V3D to protect DVDD/DVCC rail order, yet still prints the 0.134 ms result. [Notes v1.0](../doc/DAC_HPA_Schematic_Design_Notes_v1.0.docx) describes an approximately 0.76 ms 1V3 sequence. | `verify_release.py` reproduces the shipped C06 output but does not compare its EN assumption with the captured netlist. |

The EN tie was an intentional later design correction for 3V3D fault and
hard-unplug ordering. Keep the present U303 pin map while rebuilding the
discharge evidence. Connecting EN back to `AUD_EN` would reopen the DAC supply
order fault that the latest Spec says was closed.

## Source-derived inventory and first power screen

The workbook connects **11.81 µF nominal directly to 3V3D**, **1.30 µF** on
the FB202 CPLD branch and **2.30 µF** on the FB301 DVCC branch, including
C439's 2.2 µF. The total is **15.41 µF nominal** or **16.951 µF** if each is
10% high. The package's C06 high-capacitance expression evaluates to
**15.09 µF including its 1 µF reserve**, and does not enumerate all the
captured capacitors. Voltage bias, supplier tolerance and bead dynamics still
need a qualified model.

For illustration only, if U504 is already off and the rail acts as one
16.951 µF capacitor discharged through 10.1 Ω plus 55.2 mΩ FET resistance,
an assumed 89 µs gate delay gives **0.693 ms** to 0.1 V from 3.333 V. Adding
a separate 1 µF reserve gives **0.728 ms**. These are **not guaranteed shutdown
times**: they exclude U303 sourcing current into R530, regulator turn-off
delay, reverse current, load variation and rail separation by the beads.

| Fitted resistor | Initial electrical screen | Why it remains open |
| --- | ---: | --- |
| R527, 10 Ω 0603, 0.1 W | 1.145 W at 3.366 V and −1% R | Pulse rating for this exact part and regulator overlap need verification. |
| R529, 10 Ω 0603, 0.1 W | 1.122 W at 3.333 V and −1% R | The summed 3V3D capacitor energy alone is 94.2 µJ at +10% C, before any LDO drive; the workbook's 0.1 mJ pulse annotation lacks an identified manufacturer pulse limit. |
| R530, 4.7 Ω 0603, 0.1 W | 0.400 W at 1.365 V and −1% R | U303 can regulate into this load while its 3V3D input remains high enough. |

The power figures are *instantaneous* (V²/R), not proof of damage or a
qualified pulse rating. The capacitor energy is not an upper bound on the
energy in R529 if a regulator continues to supply the rail.

## Physical ECO study and next evidence

The [separate 120 × 100 mm fit-option board](DAC_HPA_120x100_DISCHARGE_FIT_OPTION_ONLY.kicad_pcb)
uses provisional KiCad 2512 lands for **all three** discharge resistors. Its
[replay script](manual_discharge_fit_option.py) records hand-selected positions
R527 (44.4, 113.0, 270°), R529 (44.4, 125.5, 90°), R530 (57.3, 135.8,
180°), plus moves to R512/C514/R531/TP738/Q506/R535. A 0.50 mm F.Cu track
joins R527.2→Q503.3 in **5.600 mm**, and a 0.30 mm track joins
Q506.3→R530.2 in **4.862 mm**. The upstream
3V3A/3V3D/1V3 feeds and R529 discharge leg remain open.

The [fit audit](DISCHARGE_FIT_OPTION_SUMMARY.json) and KiCad DRC report **zero
geometry violations**. R527/R529/R530 F.Fab body-to-board-edge clearances
measure **2.75/2.75/2.55 mm** against [JLCPCB's 2.5 mm assembly term](https://jlcpcb.com/help/article/terms-and-conditions-of-jlcpcb-assembly-service).
R530's nominal body gap to Q506 is only **0.945 mm** and its edge margin only
**0.05 mm**. Part-body tolerance, panel process, actual solder access and
heat-spreading copper need review; this is a fit study, not manufacturability
approval. All **478** populated model bodies resolve, including a newly
bundled KiCad 2512 STEP model. The GitLab review artifact carries the option
GLB and raw 3D audit.

The JLC-listed 10 Ω candidate for R527/R529 is [Milliohm HoCR2512-2W-10R-1%,
C5123624](https://jlcpcb.com/partdetail/Milliohm-HoCR2512_2W_10R_1/C5123624),
2 W, ±1%. The currently stocked 4.7 Ω candidate for R530 is [FOJAN
FRC2512J4R7 TS, C2907584](https://jlcpcb.com/partdetail/FOJAN-FRC2512J4R7TS/C2907584),
1 W, ±5%. At 1.365 V and −5% R, its initial V²/R power is **0.417 W**;
its tolerance also requires a new discharge-time analysis. The latter page
showed stock at the 29 September 2026 lookup, which must be rechecked at
ordering. Both JLC entries share the exact [imported R2512 land](JLC_Imported.pretty/R2512.kicad_mod)
and [STEP model](EASYEDA_MODELS/R2512_L6.3-W3.2-H0.6.step), retained with the
[source archive](JLC_Source/JLC_Discharge_2512.elibz) and a reproducible
[CAD audit](DISCHARGE_JLC_CAD_AUDIT.json). The JLC land has a **4.8505 mm
inner gap** and **7.4155 mm outer span**. The [FOJAN maker datasheet linked
from its JLC listing](https://jlcpcb.com/partdetail/FOJAN-FRC2512J4R7TS/C2907584)
(printed page 12) recommends **3.60–4.20 mm** and **7.60–8.60 mm** respectively.
Thus the imported JLC land also needs a resolved maker/JLC assembly review;
it is not an approved replacement for the option board's provisional KiCad
lands. The Milliohm maker land drawing and both 1:1 body overlays remain open.
These are **fit-study candidates**, not approved BOM substitutions; the main
schematic and integrated PCB still carry 0603 parts.

Before replacing the 0603 parts or claiming discharge timing:

1. Rebuild C06/C12 from the captured U303 EN=3V3D topology and complete
   3V3D/1V3 capacitor inventory. Include U504 turn-off and U303 output/load
   behavior, MOSFET gate timing, fault cases and bead branches.
2. Resolve the Spec's 0.134 ms statement against the later Notes' approximate
   0.76 ms sequence. Keep the ≥1 ms firmware re-enable interval unless a new
   worst-case bound and DAC rail-order analysis justify a change.
3. Select pulse/steady-rated R527/R529/R530 parts with current JLC assembly
   availability. Resolve the maker/JLC land conflict, then fit, route and
   thermally check the qualified footprints.
4. Scope 3V3D, DVCC, 1V3, `AUD_EN`, Q505/Q506 gates and 5V_SYS current during
   reset, suspend, unplug, brown-out and a 3V3D fault. Measure resistor and
   U303/U504 temperatures through repeated cycling. Do not label a C06 rerun
   or a zero-DRC partial board as electrical qualification.

The [TI TLV758P datasheet](https://www.ti.com/lit/ds/symlink/tlv758p.pdf)
specifies its enable and output-discharge behavior; its 95 Ω internal
pulldown figure is typical, so the captured R530/Q506 path remains relevant.

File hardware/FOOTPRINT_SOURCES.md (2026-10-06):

# Custom footprint source record

These 2D land patterns support schematic capture and pad-number checking. G-3 still requires a 1:1 drawing overlay and physical sample check before PCB routing. `3D_MODEL_REVIEW.md` records the separate model sources and inspection limits.

| KiCad footprint | Source and dimensions used | Local change or unresolved check |
| --- | --- | --- |
| `J101_USB4105-GF-A_12lands_4stakes` | [GCT USB4105 drawing](https://mm.digikey.com/Volume0/opasdata/d220001/medias/docus/5492/USB4105.pdf): 12 electrical solder lands, four shell stake slots, two Ø0.65 locating holes | Four shared contacts use workbook composite pad IDs; JLC CAD splits them. The owner reports both G-1 samples match and waived the raw log. G-3 overlay and JLC pin-in-paste confirmation remain open. |
| `J701_GT-3321667P-01_maker_slots` | [G-Switch GT-3321667P-01 drawing](https://atta.szlcsc.com/upload/public/pdf/source/20210324/C2762984_895B09C838D8EF4D4228BF97BFC29634.pdf) and JLCPCB C2762984 CAD: 12 plated 0.50 × 1.40 mm slots, two Ø1.20 mm peg holes; maker copper 1.00 × 1.90 mm | `derive_connector_footprints.py` keeps the JLC pad centres and maker slot drills and converts graphical peg holes to NPTH. The owner chose 2.15 × 1.25 mm copper pads to give ≥0.31 mm worst ring at JLC's +0.13 mm slot tolerance. Pads 9–12 have no nets; 11/12 are soldered mounting tabs. G-3 overlay and JLC DFM of the enlarged copper remain open. |
| `J702_PJ-332A-6A_peg_holes` | [HRO PJ-332A-6A drawing](https://datasheet.lcsc.com/datasheet/pdf/ae194aee17b3d1e2f10994958208a91f.pdf?productCode=C2848643) and JLCPCB C2848643 CAD: pads 1/2 plated 0.60 × 1.50 mm slots, maker copper 1.00 × 1.90 mm; pads 3–6 surface lands, two Ø1.20 mm peg holes | `derive_connector_footprints.py` keeps JLC pad centres and slot drills, enlarges only pads 1/2 to 2.25 × 1.35 mm copper for a ≥0.31 mm ring at JLC's +0.13 mm slot tolerance, replaces graphical peg holes with NPTH, and moves a partial board-edge guide to Dwgs.User. The imported silkscreen is trimmed clear of the enlarged pads. Pins 5/6 remain no-connect break contacts. Pads 1/2 have no F.Paste until G-6 resolves soldering. G-3 overlay and JLC DFM remain open. |
| `VSSOP-8_L3.0-W3.0-P0.65-LS5.0-BL` (U403/U404, U613–U620) | JLCPCB C140314 CAD for TI TLV3402IDGKR; DGK 3.0 × 3.0 mm body, 0.65 mm pitch. [TI's OPA2210 D/DGK pin table](https://www.ti.com/lit/ds/symlink/opa2210.pdf) confirms pins 1–8 for owner-approved OPA2210IDGKR/C2876414. | The same TI DGK package land is reused for U403/U404; the exact C2876414 CAD was not imported. JLC pads are about 1.662 × 0.364 mm at 4.262 mm row spacing; TI's example land is 1.4 × 0.45 mm at 4.4 mm row spacing. Resolve the final land at G-3/JLC DFM. U605's SOIC-8 land is not reused. |
| `SOT-23-3_L2.9-W1.6-P1.90-LS2.8-BR` (Q623–Q627) | JLCPCB C81464 CAD for onsemi MMBT3904LT1G | Imported with the supplied JLC loader; pad numbers 1 B, 2 E, 3 C checked against the workbook. G-3 overlay remains open. |
| `Capacitor_SMD:C_1206_3216Metric` (C647–C654) | KiCad nominal IPC land for FH 1206CG104J500NT, 100 nF C0G 50 V | New low-level persistence timers need C0G in 1206. G-3 checks sample or maker land. |
| `Resistor_SMD:R_2512_6332Metric` (R527/R529/R530 **fit option only**) | KiCad 10 IPC nominal: two 1.225 × 3.35 mm pads at x=±2.9625 mm, provisional 6.35 × 3.10 mm body. Candidate JLC parts are [Milliohm C5123624](https://jlcpcb.com/partdetail/Milliohm-HoCR2512_2W_10R_1/C5123624) for R527/R529 and [FOJAN C2907584](https://jlcpcb.com/partdetail/FOJAN-FRC2512J4R7TS/C2907584) for R530. | The [separate option board](DAC_HPA_120x100_DISCHARGE_FIT_OPTION_ONLY.kicad_pcb) is not schematic/BOM aligned. Its pads are not the [exact JLC import](JLC_Imported.pretty/R2512.kicad_mod). The [CAD audit](DISCHARGE_JLC_CAD_AUDIT.json) finds that the exact JLC A/B land dimensions conflict with FOJAN's maker recommendation; Milliohm's maker land remains unavailable. Body tolerance and 1:1 overlays remain open; R530 has only 0.05 mm nominal margin over JLC's 2.5 mm body-edge condition. |
| `D102_SMDJ12A_HandSolder` | KiCad's `Diode_SMD:D_SMC` base footprint and [Littelfuse SMDJ12A package](https://www.littelfuse.com/products/overvoltage-protection/tvs-diodes/surface-mount/smdj/smdj12a) | Outer pad toes extended 0.3 mm for owner soldering; sample polarity and clearance G-3/G-4 remain open. |
| `X201_KC2520K80_Kyocera` | [Kyocera KC2520K80 drawing](https://ele.kyocera.com/assets/products/crystal-device/specification/KC2520K80.0000C1GE00_e.pdf): recommended pad centres 1.85 × 1.45 mm, pads 1.05 × 0.95 mm | Replaced JLC's larger 1.9 × 1.5 mm pitch and 1.2 × 1.1 mm pads. |
| `X202_X203_NDK_NZ2520SDA` | [NDK NZ2520SDA drawing](https://www.ndk.com/en/products/upload/lineup/pdf/NDKT02-00008_en.pdf): recommended pad centres 1.65 × 1.25 mm, pads 1 × 1 mm | Pin 1 is standby; same geometry used for both frequency variants. |
| `QFN-32_L4.0-W4.0-P0.40-BL-EP2.7_EP` (U202) | [AGM AGRV2K datasheet, Fig. 5-4](https://datasheet.lcsc.com/datasheet/pdf/ba442eca75b078e6f12a3031e72261a3.pdf?productCode=C18208899): exposed metal D2/E2 = 2.60 min, 2.70 nominal, 2.80 max mm | The JLC land is 2.8 × 2.8 mm, despite `EP2.7` in its name; U202 `EP` is on GND. This is consistent with the maker's maximum metal size but still needs G-3 overlay/X-ray review. |
| `C631_ECHU1H224GX9_D4` | [Panasonic ECH-U data](https://industrial.panasonic.com/cdbs/www-data/pdf/RDI0000/ABD0000C173.pdf): D4 6.0 × 4.1 mm body, land dimensions A=4.0 mm inner gap, B=7.0 mm overall, C=3.8 mm pad height | Two 1.5 × 3.8 mm lands at x=±2.75 mm; L-13 reflow-time gate remains open. |
| `K601_TLP3545A_LF1_HandSolder` | [Toshiba DIP6(LF1) land diagram](https://toshiba.semicon-storage.com/ap-en/semiconductor/design-development/package/detail.DIP6%28LF1%29.html): x pitch 2.54 mm, row pitch 8.7 mm, 1.5 × 1.6 mm lands; [TLP3545A datasheet](https://toshiba.semicon-storage.com/info/TLP3545A_datasheet_en_20230526.pdf?did=60318&prodName=TLP3545A) confirms LF1/11-7A801S package | Each pad is 0.3 mm longer at the outer toe per Parts List v0.9; courtyard includes 1.5 mm iron clearance. G-3 sample overlay remains open. |

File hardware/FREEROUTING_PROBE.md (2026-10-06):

# Freerouting routeability probe

**29 September 2026 · Whole-board session rejected.** A copy of the 120 × 100 mm
integrated study was exported through KiCad 10's Specctra DSN API and routed
with locally installed Freerouting 2.4.1. The `.ses` result was imported into
another temporary PCB for inspection. The bulk result was not promoted to the
[review board](DAC_HPA_120x100_INTEGRATED_AUDIO_STUDY_ONLY.kicad_pcb).

| Probe measure | Input copy | Imported session |
| --- | ---: | ---: |
| Fully pad-connected nets with at least two pads | 44 / 249 | 112 / 249 |
| KiCad connectivity links | 896 | 472 |
| Tracks and vias | 753 | 2,460 |
| Vias | 125 | 228 |

The one-pass, no-fanout, no-optimizer run started with 962 Freerouting
unrouted items and ended with **499 unrouted and 53 Freerouting-reported
violations** after 3 min 10 s. Peak Java heap was about 1.22 GB. These counts
use different connectivity definitions from KiCad's partial-board DRC and are
not interchangeable. The protected-wire DSN experiment produced the same
session apart from its header; it did not preserve existing copper.

The result is **not a routable replacement**. The exported DSN has the four
layers, a GND plane, and four basic net classes, but omits the project's
named `.kicad_dru` constraints. In the imported copy, `LEG_LP` and `LEG_LN`
each gained two vias and B.Cu traces despite the L1-only rule. Some new
`VBUS` and `5V_SYS` tracks are below the required 1.0 mm width. Freerouting
also changed 57 existing copper items. Its new vias left the original saved
L2 zone fill stale until KiCad refilled it. The imported board has no
successful KiCad DRC: the temporary headless DRC crashed in macOS AppKit.

The probe is useful as a **congestion signal**: even with custom rules lost,
137 of 249 multi-pad nets remained incomplete. The next placement pass should
inspect the failed corridors and move complete subcircuits manually.

## Selective low-speed adoption after review

Only two local, low-speed paths from a disposable imported copy were selected
for the current study. Their unchanged pad locations and nets were checked
against the captured schematic, then their exact 0.20 mm F.Cu segments were
recorded in the [frozen route manifest](INTEGRATED_AUDIO_MANUAL_DELTA.json):

| Path | Selected segments | Named-pad copper length | Vias |
| --- | ---: | ---: | ---: |
| `N2_AUD_EN_MCU`, R237.1→U201.51 | 5 | 4.285 mm | 0 |
| `N7_LEDR_A`, R702.2→D706.1 | 2 | 4.649 mm | 0 |

The selected paths keep saved filled L2 GND under their centreline and
±0.075/0.10 mm offsets at 0.01 mm samples. KiCad DRC reports zero geometry
violations, the integrated track-bend screen finds no exact or near-90°
corners, and the full `pcbnew` ratsnest fell **866→864**. KiCad's separate
DRC-unconnected count remains 499; these metrics have different definitions.
No placement was automated. USB, clock, audio, protection, and high-current
power paths from the bulk Freerouting result remain rejected. `CC2` had sharp
corners in the selective probe; `N5_DIS_D_R` is deferred because the R529
discharge-resistor footprint is under review.

## Reproduce on a disposable copy

KiCad's Python API exports DSN on this host; the `kicad-cli pcb export` menu
does not expose Specctra. The command-line flags follow the
[Freerouting CLI documentation](https://github.com/freerouting/freerouting/blob/master/docs/command_line_arguments.md)
and [settings reference](https://github.com/freerouting/freerouting/blob/master/docs/settings.md).

```sh
/Applications/KiCad/KiCad.app/Contents/Frameworks/Python.framework/Versions/Current/bin/python3 - <<'PY'
import pcbnew
board = pcbnew.LoadBoard('hardware/DAC_HPA_120x100_INTEGRATED_AUDIO_STUDY_ONLY.kicad_pcb')
pcbnew.ExportSpecctraDSN(board, '/tmp/dac-route-probe.dsn')
PY

/Applications/freerouting.app/Contents/runtime/Contents/Home/bin/java \
  -Djava.awt.headless=true -Xmx4g \
  -jar /Applications/freerouting.app/Contents/app/freerouting-executable.jar \
  -de /tmp/dac-route-probe.dsn -do /tmp/dac-route-probe.ses \
  --gui.enabled=false --router.fanout.enabled=false \
  --router.optimizer.enabled=false -mp 1 -mt 1
```

Keep the output outside the repository and import it into a disposable KiCad
board only. Refill L2 and apply the project DRC, placement, via-process and
critical-route audits before interpreting any proposed copper. Transfer only
individually accepted segments to the explicit route manifest.

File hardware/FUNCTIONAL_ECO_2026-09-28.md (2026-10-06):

# Functional schematic ECO: readbacks, J702 ESD and I/V channel assignment

**Status:** captured in the KiCad schematic and review BOM, with the I/V channel assignment updated on 29 September 2026. The unchanged Parts List v0.9 and Calculation Package v1.1 remain the baseline. `generate_schematic.py` asserts the baseline pin maps before applying this ECO; `verify_schematic.py` checks the exact 34 source-to-schematic pin/net differences. This is a review capture, not a schematic or fabrication release. The full-rate capture guard, measured 3V3M attach current and physical gates remain open.

## I/V macro: equivalent amplifier channels reassigned

The two channels of each OPA2210IDGKR are functionally equivalent. The manually selected VSSOP placement assigns each positive DAC current leg to physical amplifier B and each negative leg to amplifier A. The feedback R/C, clamps, common-mode taps, DAC pads and downstream T inputs remain on their original named nets; only four U403 pins and four U404 pins change net assignment. This is an explicit schematic ECO so the PCB pad map can be checked against the captured circuit.

| Op amp | Physical A: pins 2 input / 1 output | Physical B: pins 6 input / 7 output |
| --- | --- | --- |
| U403 | `DACLB` / `N4_IVL_N` | `DACL` / `N4_IVL_P` |
| U404 | `DACRB` / `N4_IVR_N` | `DACR` / `N4_IVR_P` |

The [integrated route study](INTEGRATED_AUDIO_ROUTE_STUDY.md) checks the corresponding copper and the provisional ≤7 mm DAC-to-I/V routes. Its plan-view feedback-area screen is a placement check, not extracted stability or a fabrication approval.

## F02: supervisor readback isolation

The independent functional review identified insufficient worst-case logic margin where U605's open-collector 3V3A-good outputs reach U201 PA12/PB9 through R688/R689 = 470 kΩ. These resistors remain in place to avoid changing the comparator's existing pull-up/hysteresis network. A dual noninverting Schmitt buffer now senses the isolated nodes and drives the MCU inputs:

| Reference | Value / JLC code | Pin or connection |
| --- | --- | --- |
| R688/R689 | Existing 470 kΩ | Pin 1 stays on `N6_V3AG_A/B`; pin 2 now goes to `N6_V3AG_A/B_BUF_IN`. |
| U621 | TI SN74AUP2G17DCKR, C507231 | Pin 1 = A input; 2 = GND; 3 = B input; 4 = B output; 5 = 3V3M; 6 = A output. Noninverting channels preserve the existing fault-high polarity. |
| R952/R953 | 10 kΩ, C25744 | Between each U621 output and the existing MCU readback net `N6_V3AG_A/B_MCU`. |
| R954/R955 | 100 kΩ, C25741 | From 3V3M to each MCU-side readback net; an open U621 output reads high. |
| C667 | 100 nF, C1525 | 3V3M to GND at U621 pin 5; placement must keep the supply/return loop local. |
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

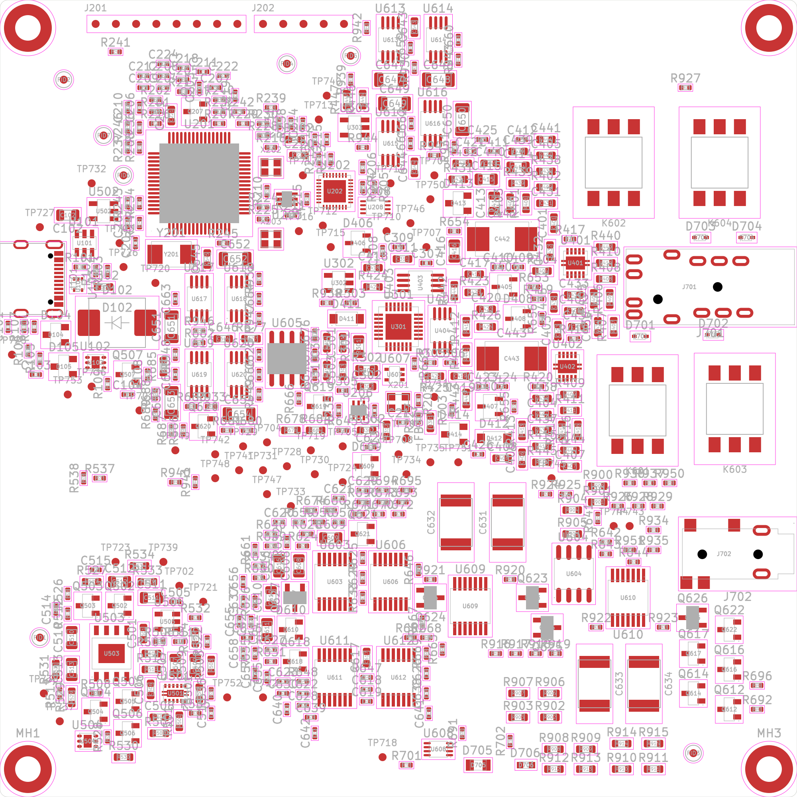
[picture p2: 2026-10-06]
hardware/DAC_HPA_100x100_timer_preview.png

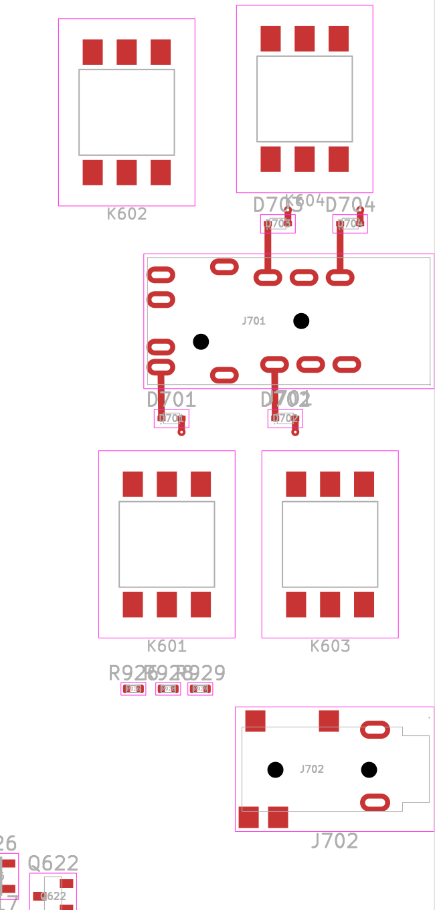
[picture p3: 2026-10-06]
hardware/DAC_HPA_120x100_output_zoom.png

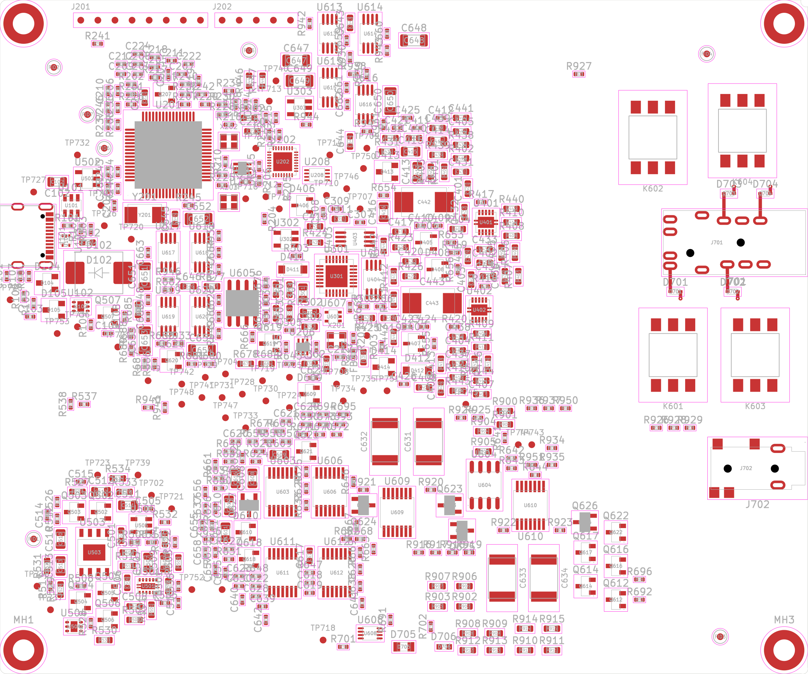
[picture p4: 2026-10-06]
hardware/DAC_HPA_placement_preview.png

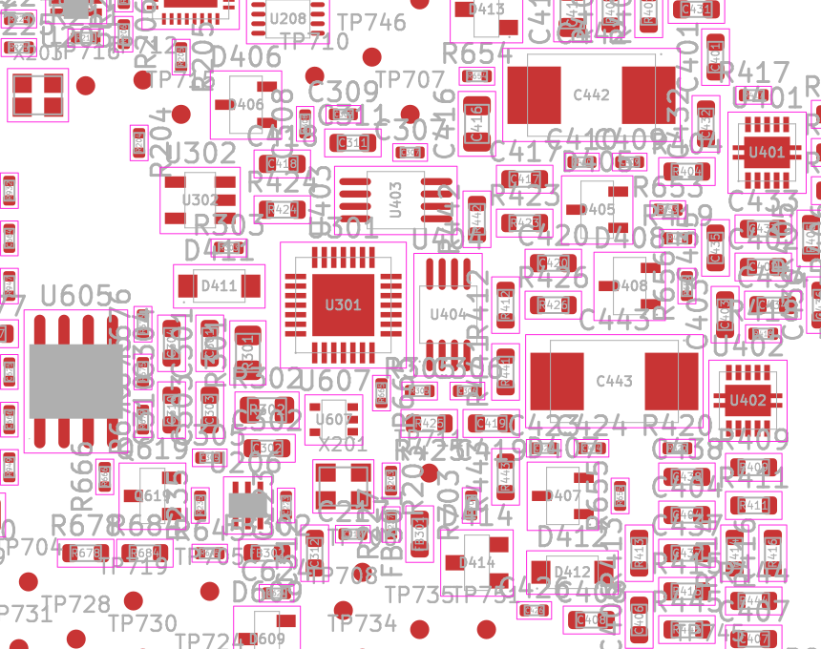
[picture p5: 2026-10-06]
hardware/DAC_HPA_120x100_clock_zoom.png

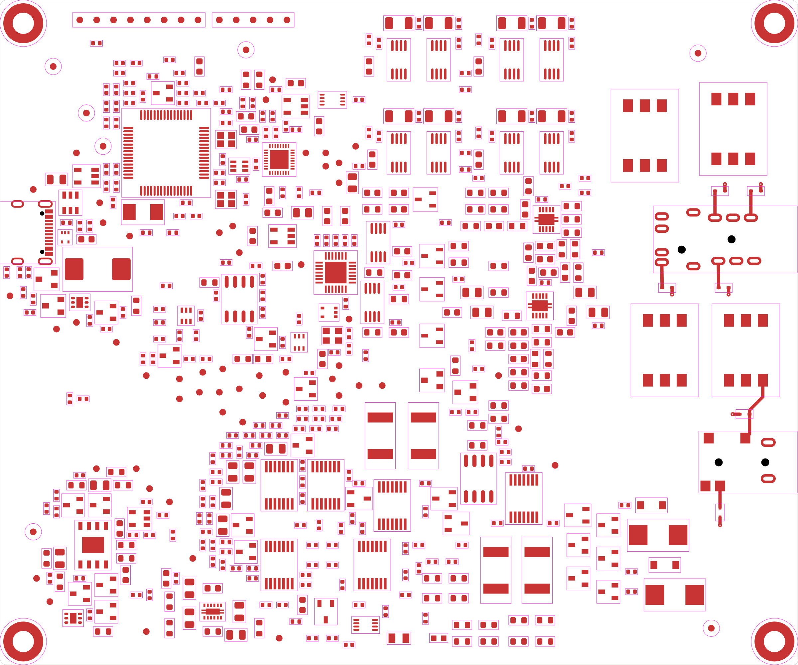
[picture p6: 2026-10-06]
hardware/DAC_HPA_FUNCTIONAL_ECO_PLACEMENT_REVIEW.png

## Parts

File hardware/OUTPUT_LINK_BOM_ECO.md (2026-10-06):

# R417–R420 output-link BOM candidate — 28 September 2026

This is a review-only, same-value substitution for the four removable 0 Ω
design-for-test links. The pin nets and `R_0402_1005Metric` land stay the same.
R107, the USB shield link, remains on the original part. The controlled v0.9
Parts List and v1.1 Calculation Package remain unchanged; the generated
schematic and review BOM assert this overlay explicitly.

| Item | Source workbook | Review candidate |
| --- | --- | --- |
| R417–R420 | UNI-ROYAL 0402WGF0000TCE, JLC C17168, 0 Ω / ≤50 mΩ link budget | [YAGEO PA0402-R-070RL, JLC C4044221](https://jlcpcb.com/partdetail/YAGEO-PA0402_R070RL/C4044221), 0 Ω / [≤1 mΩ manufacturer maximum](https://www.yageogroup.com/content/Resource%20Library/Datasheet/PYU-PA_JUMPER_L_51_ROHS.pdf) |
| Assembly | 0402 SMT | 0402, JLC Extended SMT; stock was observed on 28 September 2026 and must be checked again at order |

Yageo's PA0402 code-07 table rates the jumper at 11 A and 1/8 W. JLC's
catalogue instead displays 62.5 mW, so the power-field discrepancy needs
order-stage clarification. The PCB trace, pads and relay contacts have their
own current and thermal limits; the component rating does not establish a
board rating. Check the actual JLC land/rotation and paste preview against
the current generic 0402 footprint before assembly release.

## Electrical budget

The v1.1 R-15 model uses **50 mΩ per fitted output link**. Replacing that
term with the Yageo **1 mΩ maximum** subtracts 49 mΩ per leg or 98 mΩ
from a balanced loop. The model's nominal starting values consequently
change from 0.25133 to 0.20233 Ω at the 3.5 mm jack and from 0.38266 to
0.28466 Ω at the 4.4 mm jack, before this PCB's routed-copper adjustment.
This is a comparison of specified maxima in an engineering model. It does
not predict a 49 mΩ measured improvement over the original physical
jumpers, whose actual resistance may be well below their maximum.

For the [manually routed integrated study](INTEGRATED_AUDIO_ROUTE_STUDY.md),
the [copper audit](INTEGRATED_AUDIO_TRACE_BUDGET.json) replaces the model's
20 mΩ trace allowance with the routed signal-path estimate and illustrative
via barrels. Its worst J701 pad paths with the candidate are:

| Channel | 1 kHz model | 20 kHz model sensitivity |
| --- | ---: | ---: |
| Left | 0.3862 Ω | 0.3990 Ω |
| Right | 0.3737 Ω | 0.3864 Ω |

The 20 kHz estimate uses the calculation package's OPA1622 closed-loop
output impedance. It is conditional on the **50 mΩ per jack-contact
engineering estimate**, 35 µm copper at 50 °C, illustrative via plating,
and the modelled amplifier response. The 3.5 mm audit gives signal-only
lower bounds of 0.2255 Ω left and 0.2188 Ω right; its sleeve return is not
routed/extracted. No maker maximum for the jack contact is available.
**Neither jack has a measured ≤0.5 Ω R-15 result.**

## Model sensitivity beyond R-15

An isolated temporary extraction of the v1.1 calculation package was used.
For `r2_power.py` and `r10_fixes.py`, `r2_common.R_LINK` and its derived
series terms were rebound from 0.050 to 0.001 Ω in memory. Temporary
copies of `r3_fixes.py` and `stability_switch.py` changed only their
0.05 Ω output-link element to 0.001 Ω; their 5 nH link/trace parasitic
stayed fixed. The rounded High-mode peak
power changed from 54.9 to 55.0 mW at the 3.5 mm/32 Ω load and from
114.3 to 114.7 mW at the 4.4 mm/60 Ω load. At a **fixed Default
firmware/leg-drive ceiling**, the 3.5 mm/32 Ω jack rises from 38.000 to
38.116 mW. The modelled `5V_ANA` peak including `ANA_SENSE` rises from
178.961 to 179.114 mA, reducing the thin eFuse margin from 1.090 to
0.937 mA. Retuning the drive to hold exactly 38 mW would instead reduce
the current slightly, but that is a separate firmware action and is not
assumed for this BOM-only ECO. The eFuse/current result depends on the
LM27762 and auxiliary-current estimates and remains a bench gate.
The closed-switch amplifier/cable model retained about 51.3° phase margin,
with gain margin changing from 7.7 to 7.6 dB; its 2 nF case changed
from 47.2° to 47.1° phase margin. These are model sensitivities with the
same assumed parasitics, not a routed-board stability result.

The LEG protection taps sit after the links. At the calculation package's
190 mA output-current bound, the lower maximum link drop shifts LEG by at
most 9.31 mV relative to the amplifier output. Detector thresholds and
timers are unchanged, but normal-content false trips and fault timing
still require the stated bring-up tests.

The package's protection-energy equations use ideal load `V²/R` and do
not take credit for the old 50 mΩ link. A separate fixed-source illustrative
32 Ω balanced case changed from 14.546 to 14.634 mJ, below the 15 mJ
screen, but the existing no-swing-credit High-mode frozen-word case can
still exceed it. A-45 and the short-circuit gate remain **open**. The
lower-DCR jumper is not a fuse and does not provide the optional ferrite's
33 Ω at 100 MHz ESD impedance.

## Acceptance before choosing the part for PCBA

1. Recheck JLC assembly stock, exact footprint/rotation and the power
   catalogue discrepancy, then confirm the intended four designators in the
   final BOM and placement file. A stock count from 28 September cannot
   reserve order quantity.
2. Recheck the above model sensitivities against the finalized output-stage
   copper, cable/load parasitics and fault timing. Preserve the removable
   link function for rail-stuck emulation. The 50 mΩ source model is not
   a qualified contact, relay or fault-energy bound for the new board.
3. Route the remaining amplifier power, input/T and return networks, then
   extract both jack paths and measure output impedance, stability, THD+N,
   crosstalk and system ESD. The optional 33 Ω-at-100 MHz ferrite is a
   separate ESD design alternative, not part of this substitution.

The review BOM selects C4044221 so that the four output links can be
evaluated as a concrete assembly candidate. It is **not a fabrication
approval**; G-3/G-4, JLC DFM and the board-level qualification remain open.

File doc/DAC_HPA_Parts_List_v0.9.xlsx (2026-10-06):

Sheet: Parts list
Parts list — every BOM line, grouped by block
One part per line, grouped by block. Fit: Yes = placed by JLCPCB; Owner = owner-fitted (bought by the owner, hand-soldered after delivery, not in the JLCPCB order); No = DNF; Pads = copper only; No part = layout items; Board = bare PCB. Unit prices in US$ (LCSC/JLCPCB sample tier; distributor prices for global-sourced and owner-bought parts). No spare-parts stock: JLCPCB lines buy the exact 5-board quantity plus attrition (Cost sheet inputs); a pre-ordered LCSC line buys at least its LCSC order quantity. Helper columns Z–AG feed the Checks sheet (AC–AG: the value decoded from the part number against the Value column).
Block | Designators | Qty per board | Description | Value | Package | Rating / tolerance | Part number (MPN) | LCSC no. | JLCPCB class | Source | Stock and sourcing | Fit (Yes = JLCPCB, Owner = owner-fitted) | Leadless (X-ray) | SMT joints per part | Through-hole joints per part | Unit price US$ | Qty for 5 boards | Line cost US$, 5 boards (exact) | Attrition rule | LCSC order quantity (input) | Qty to buy (5 boards + attrition) | Line cost US$ (qty to buy) | Datasheet | Notes | Designator list (helper) | Designators on line (helper) | New MPN (helper) | Value-code family (helper) | Value code (helper) | Value from part number, Ω or F (helper) | Value as entered, Ω or F (helper) | Value check (helper)
1 USB-C input, OVP and sensing | C101 | 1 | DNF: shell-to-GND RF capacitor (only if R107 becomes a bleed resistor) | 4.7 nF | 0402 | 50 V X7R | FH 0402B472K500NT | C1538 | Basic | — (DNF) | As in Parts List v0.6 | No |  | 2 | 0 | 0.0020 | 0 | 0.00 | — |  | 0 | 0.00 | https://www.lcsc.com/product-detail/C1538.html | Unchanged | ,C101, | 1 | 0 | FH | 472 | 4.7e-09 | 4.7e-09 | OK
1 USB-C input, OVP and sensing | C102 | 1 | VBUS input capacitor at J101 / U102 IN, also the U502 input capacitor (attach region A ≤ 29.6 µC with the 3V3M charge; hard-short kick with D102: U102 IN ≤ 17.08 V) | 2.2 µF | 0805 | 25 V X5R ±10 % | Samsung CL21A225KAFNNNE | C87994 | Extended | JLCPCB library | LCSC C87994; DigiKey 80,862 (23 Sep 2026) — confirm the stock in the JLCPCB BOM tool at order | Yes |  | 2 | 0 | 0.0200 | 5 | 0.10 | Passive: +5 %, min +2 |  | 7 | 0.14 |  | Changed 4.7 µF → 2.2 µF (suspend power cut: the 3V3M capacitors now charge at plug-in through U502) | ,C102, | 1 | 1 | Samsung CL | 225 | 2.2e-06 | 2.2e-06 | OK
1 USB-C input, OVP and sensing | C103 | 1 | VBUS_SENSE ADC input capacitor at PA1 (tau 3.6 µs with R105/R106; brown-out watchdog acts before the MCU reset) | 100 pF | 0402 | 50 V C0G ±5 % | Samsung CL05C101JB5NNNC | C1546 | Basic | JLCPCB library | JLCPCB Basic | Yes |  | 2 | 0 | 0.0020 | 5 | 0.01 | Passive: +5 %, min +2 |  | 7 | 0.01 | https://www.lcsc.com/product-detail/C1546.html | Changed from 10 nF X7R to 100 pF C0G (fast brown-out detection) | ,C103, | 1 | 1 | Samsung CL | 101 | 1e-10 | 1e-10 | OK
1 USB-C input, OVP and sensing | C104 | 1 | U102 EN delay capacitor (EN to GND, with R109 470 k): U102 switches on 3.31–55.3 ms after plug-in at every corner | 100 nF | 0402 | 16 V X7R ±10 % | Samsung CL05B104KO5NNNC | C1525 | Basic | JLCPCB library | JLCPCB Basic | Yes |  | 2 | 0 | 0.0045 | 5 | 0.02 | Passive: +5 %, min +2 |  | 7 | 0.03 | https://www.lcsc.com/product-detail/C1525.html | New; the two plug-in charge regions stay ≥ 1.96 ms apart | ,C104, | 1 | 1 | Samsung CL | 104 | 1e-07 | 1e-07 | OK
1 USB-C input, OVP and sensing | D102 | 1 | VBUS TVS at J101 (VBUS-GND, unidirectional, cathode to VBUS): U102 IN ≤ 17.08 V at a 5V_SYS hard short with no tIOS credit (20 V absolute maximum); VRWM 12 V so a mis-set 9 V source is below stand-off | 12 V | DO-214AB (SMC) | VRWM 12 V, VBR 13.3-14.7 V, VC 19.9 V at 150.8 A, IR ≤ 2 µA at 12 V (25 °C), 3000 W | Littelfuse SMDJ12A | — | — | Owner purchase (DigiKey) | Owner purchase (DigiKey): 5,498 in stock (Sep 2026), US$ 1.01 at 10+; LCSC SMDJ12A (MDD C2994091, TSC C3717799) out of stock; LGE C5806873 not adopted (IR/VBR maximum not verifiable) | Owner |  | 2 | 0 | 1.0100 | 5 | 5.05 | Owner purchase: 5 × qty |  | 5 | 5.05 | https://www.littelfuse.com/products/overvoltage-protection/tvs-diodes/surface-mount/smdj/smdj12a | Owner-fitted: hand-soldered after delivery, not placed by JLCPCB; fitted first, before the first USB plug-in; SMC lands with toes +0.3 mm, ≥ 1.5 mm iron clearance, ≤ 5 mm from J101; polarity gate G-4 (band = cathode = VBUS) | ,D102, | 1 | 1
1 USB-C input, OVP and sensing | J101 | 1 | USB-C receptacle, USB 2.0: 16 contacts on the 12 composite GCT solder lands (shared A1/B12, A4/B9, B4/A9, B1/A12; single A5, A6, A7, A8, B5, B6, B7, B8) plus the plated shell stakes S1–S4; the provisional footprint uses the 16 JLCPCB pad IDs (each shared land is two touching pads on one net), plus two Ø0.65 mm non-plated locating holes; pin-in-paste on S1–S4 only after JLCPCB confirms the process and the aperture geometry (G-6); fallback: the owner hand-solders S1–S4 from the bottom side before the first plug-in (the stakes carry the shell and the mechanical retention); shell to GND via R107 | — | SMD horizontal top mount, 0.95 mm shell stakes | 48 V DC (GCT page; drawing 20 V), VBUS 5 A, GND 6.25 A, others 0.25 A, 40 mΩ max; solder peak 255 °C (-0/+5) max 5 s | GCT USB4105-GF-A | C3020560 | Extended | Global sourcing | LCSC out of stock (14 Sep 2026); DigiKey 127,933 (24 Sep 2026) → JLCPCB global sourcing; JLCPCB lists it as Economic and Standard, assembly difficulty high | Yes |  | 12 | 4 | 1.0900 | 5 | 5.45 | Other: +1 |  | 6 | 6.54 | https://gct.co/connector/usb4105 (drawing text: https://www.mouser.com/datasheet/2/837/USB4105-1948910.pdf) | Changed from the SHOU HAN receptacle; pads named by contact per the GCT drawing; Standard PCBA reflow 240 °C (JLCPCB to confirm the dwell, order remark); provisional footprint J101_USB4105-GF-A_12lands_4stakes (label ↔ JLCPCB pad-ID mapping on the Notes sheet); gates G-1 continuity (2 samples) and G-3 1:1 overlay; the S1–S4 soldering process is a G-6 order-release item | ,J101, | 1 | 1
1 USB-C input, OVP and sensing | R101, R102 | 2 | CC1/CC2 Rd pull-down (USB-C sink) | 5.1 kΩ | 0402 | 1 % | UNI-ROYAL 0402WGF5101TCE | C25905 | Basic | JLCPCB library | As in Parts List v0.6 | Yes |  | 2 | 0 | 0.0020 | 10 | 0.02 | Passive: +5 %, min +2 |  | 12 | 0.02 | https://www.lcsc.com/product-detail/C25905.html | Unchanged | ,R101,R102, | 2 | 1 | UNI-ROYAL | 5101 | 5100 | 5100 | OK
1 USB-C input, OVP and sensing | R103, R104 | 2 | CC1/CC2 series resistor to MCU ADC (CC1_ADC, CC2_ADC) | 10 kΩ | 0402 | 1 % | UNI-ROYAL 0402WGF1002TCE | C25744 | Basic | JLCPCB library | As in Parts List v0.6 | Yes |  | 2 | 0 | 0.0020 | 10 | 0.02 | Passive: +5 %, min +2 |  | 12 | 0.02 | https://www.lcsc.com/product-detail/C25744.html | Unchanged | ,R103,R104, | 2 | 1 | UNI-ROYAL | 1002 | 10000 | 10000 | OK
1 USB-C input, OVP and sensing | R105 | 1 | VBUS_SENSE divider top, from 5V_SYS | 100 kΩ | 0402 | 1 % | UNI-ROYAL 0402WGF1003TCE | C25741 | Basic | JLCPCB library | As in Parts List v0.6 | Yes |  | 2 | 0 | 0.0033 | 5 | 0.02 | Passive: +5 %, min +2 |  | 7 | 0.02 | https://www.lcsc.com/product-detail/C25741.html | Now on 5V_SYS (after the OVP) | ,R105, | 1 | 1 | UNI-ROYAL | 1003 | 100000 | 100000 | OK
1 USB-C input, OVP and sensing | R106 | 1 | VBUS_SENSE divider bottom (k = 0.3197; 5.55 V → 1.77 V) | 47 kΩ | 0402 | 1 % | UNI-ROYAL 0402WGF4702TCE | C25792 | Basic | JLCPCB library | As in Parts List v0.6 | Yes |  | 2 | 0 | 0.0020 | 5 | 0.01 | Passive: +5 %, min +2 |  | 7 | 0.01 | https://www.lcsc.com/product-detail/C25792.html | Unchanged value | ,R106, | 1 | 1 | UNI-ROYAL | 4702 | 47000 | 47000 | OK
1 USB-C input, OVP and sensing | R107 | 1 | USB-C shell to GND (0 Ω) | 0 Ω | 0402 | jumper | UNI-ROYAL 0402WGF0000TCE | C17168 | Basic | JLCPCB library | As in Parts List v0.6 | Yes |  | 2 | 0 | 0.0020 | 5 | 0.01 | Passive: +5 %, min +2 |  | 7 | 0.01 | https://www.lcsc.com/product-detail/C17168.html | Unchanged | ,R107, | 1 | 1 | UNI-ROYAL | 0000 | 0 | 0 | OK
1 USB-C input, OVP and sensing | R108 | 1 | U102 current-limit resistor (IOS 870/970/1077 mA ≥ the 760.77 mA of state S4: +109 mA to the minimum; 765.27 mA with the NDK X201 second source) | 100 kΩ | 0402 | 1 %, 62.5 mW | UNI-ROYAL 0402WGF1003TCE | C25741 | Basic | JLCPCB library | JLCPCB Basic (same type as R105, R303, R511–R513) | Yes |  | 2 | 0 | 0.0033 | 5 | 0.02 | Passive: +5 %, min +2 |  | 7 | 0.02 | https://www.lcsc.com/product-detail/C19709.html | Cost patch: changed 86.6 k (Extended) → 100 k (Basic) | ,R108, | 1 | 0 | UNI-ROYAL | 1003 | 100000 | 100000 | OK
1 USB-C input, OVP and sensing | R109 | 1 | U102 EN pull-up to VBUS (TI: ≥ 300 k; with C104, U102 switches on 3.3–55 ms after plug-in) | 470 kΩ | 0402 | 1 %, 62.5 mW | UNI-ROYAL 0402WGF4703TCE | C25790 | Basic (not verified) | JLCPCB library | Same type as R532 | Yes |  | 2 | 0 | 0.0020 | 5 | 0.01 | Passive: +5 %, min +2 |  | 7 | 0.01 | https://www.lcsc.com/product-detail/C25774.html | Cost patch: changed 300 k → 470 k (one part type less); USB D+ attach ≤ 79.2 ms against the 100 ms USB limit | ,R109, | 1 | 1 | UNI-ROYAL | 4703 | 470000 | 470000 | OK
1 USB-C input, OVP and sensing | U101 | 1 | ESD array D+/D−; VBUS pin (5) tied to 3V3M (5V_SYS is off in suspend; on 5V_SYS the D+ pull-up would back-feed it through the upper diode) | — | SOT-23-6 | IRM ≤ 150 nA at 5.25 V, 3.5 pF | ST USBLC6-2SC6 | C7519 | Extended | JLCPCB library | As in Parts List v0.6 | Yes |  | 6 | 0 | 0.1844 | 5 | 0.92 | Other: +1 |  | 6 | 1.11 | https://www.st.com/resource/en/datasheet/usblc6-2.pdf | Pin 5 moved from 5V_SYS to 3V3M (suspend power cut) | ,U101, | 1 | 1
1 USB-C input, OVP and sensing | U102 | 1 | Input OVP eFuse: 5.25-5.55 V output clamp, OVLO 6.8-8.45 V, 20 V abs max IN, 99 mΩ max, built-in soft start | — | WSON-6 2 × 2 (DRV) + pad | IOS 0.87–1.08 A with R108 100 k | TI TPS25200DRVR | C128401 | Extended | JLCPCB library | JLCPCB 19,166 available (Aug 2026) | Yes | Yes | 7 | 0 | 0.4400 | 5 | 2.20 | Other: +1 |  | 6 | 2.64 | https://www.ti.com/lit/ds/symlink/tps25200.pdf | New: VBUS → 5V_SYS; FAULT (pin 3) not connected; pad to GND | ,U102, | 1 | 1
1 USB-C input, OVP and sensing | U103 | 1 | CC1/CC2 ESD, 2 channels, low capacitance, at J101 | — | SOT-5X3 (DRL) 5-pin | VRWM 5.5 V, VBR ≥ 6.5 V, 10 nA at 2.5 V, 1.5 pF, IEC ±25 kV | TI TPD2E2U06DRLR | C1972959 | Extended (not verified) | JLCPCB library | JLCPCB 4,257 (Apr 2025); DigiKey 87,628 | Yes |  | 5 | 0 | 0.2200 | 5 | 1.10 | Other: +1 |  | 6 | 1.32 | https://www.ti.com/lit/ds/symlink/tpd2e2u06.pdf | New; pin 1/2 NC, 3 CC1, 4 GND, 5 CC2 | ,U103, | 1 | 1
2 USB audio bridge (CH32V307 + AGRV2K CPLD + clocks) | C201, C202 | 2 | Crystal load capacitors | 33 pF | 0402 | 50 V C0G | FH 0402CG330J500NT | C1562 | Basic | JLCPCB library | JLCPCB Basic | Yes |  | 2 | 0 | 0.0020 | 10 | 0.02 | Passive: +5 %, min +2 |  | 12 | 0.02 | https://www.lcsc.com/product-detail/C1562.html | 2 × (20 − 3.5) pF | ,C201,C202, | 2 | 1 | FH | 330 | 3.3e-11 | 3.3e-11 | OK
2 USB audio bridge (CH32V307 + AGRV2K CPLD + clocks) | C203-C210, C212-C215, C218, C219, C222-C224 | 17 | 100 nF: decoupling (MCU ×8, CPLD ×3, X202/X203, U205, U206, U208) and NRST filter C212 | 100 nF | 0402 | 16 V X7R | Samsung CL05B104KO5NNNC | C1525 | Basic | JLCPCB library | JLCPCB Basic | Yes |  | 2 | 0 | 0.0045 | 85 | 0.38 | Passive: +5 %, min +2 |  | 90 | 0.40 | https://www.lcsc.com/product-detail/C1525.html | C216 retired; C213–C215 at CPLD pins 6/16/32; C212 = NRST filter; C217 now its own 10 nF line; C224 new (U208) | ,C203,C204,C205,C206,C207,C208,C209,C210,C212,C213,C214,C215,C218,C219,C222,C223,C224, | 17 | 0 | Samsung CL | 104 | 1e-07 | 1e-07 | OK
2 USB audio bridge (CH32V307 + AGRV2K CPLD + clocks) | C211 | 1 | MCU 3V3M bulk | 2.2 µF | 0402 | 6.3 V X5R (≈ 1.1 µF at 3.3 V DC bias) | Samsung CL05A225MQ5NSNC | C12530 | Basic | JLCPCB library | JLCPCB Basic | Yes |  | 2 | 0 | 0.0050 | 5 | 0.03 | Passive: +5 %, min +2 |  | 7 | 0.04 | https://www.lcsc.com/product-detail/C12530.html | Kept (counted in the attach-charge budget) | ,C211, | 1 | 1 | Samsung CL | 225 | 2.2e-06 | 2.2e-06 | OK
2 USB audio bridge (CH32V307 + AGRV2K CPLD + clocks) | C217 | 1 | X201 high-frequency bypass at the VCC pad | 10 nF | 0402 | 50 V X7R | Samsung CL05B103KB5NNNC | C15195 | Basic | JLCPCB library | JLCPCB Basic | Yes |  | 2 | 0 | 0.0020 | 5 | 0.01 | Passive: +5 %, min +2 |  | 7 | 0.01 | https://www.lcsc.com/product-detail/C15195.html | Changed 100 nF → 10 nF; Kyocera: "mount high frequency type capacitor 0.01 µF to the nearest position of oscillator" | ,C217, | 1 | 1 | Samsung CL | 103 | 1e-08 | 1e-08 | OK
2 USB audio bridge (CH32V307 + AGRV2K CPLD + clocks) | C220, C221 | 2 | Bulk: CPLD FB202 branch; MCU VDDA | 1 µF | 0603 | 50 V X5R | Samsung CL10A105KB8NNNC | C15849 | Basic | JLCPCB library | JLCPCB Basic | Yes |  | 2 | 0 | 0.0060 | 10 | 0.06 | Passive: +5 %, min +2 |  | 12 | 0.07 | https://www.lcsc.com/product-detail/C15849.html |  | ,C220,C221, | 2 | 1 | Samsung CL | 105 | 1e-06 | 1e-06 | OK
2 USB audio bridge (CH32V307 + AGRV2K CPLD + clocks) | FB202 | 1 | Ferrite bead 3V3D → CPLD VDD33/VDDA33 (AGM: bead-isolated feed) | 600 Ω @ 100 MHz | 0603 | 200 mA, 0.45 Ω | Sunlord GZ1608D601TF | C1002 | Basic | JLCPCB library | JLCPCB Basic | Yes |  | 2 | 0 | 0.0127 | 5 | 0.06 | Passive: +5 %, min +2 |  | 7 | 0.09 | https://www.lcsc.com/product-detail/C1002.html | ≤ 40 mA CPLD budget → 18 mV drop | ,FB202, | 1 | 1
2 USB audio bridge (CH32V307 + AGRV2K CPLD + clocks) | J201 | 1 | Pads: MCU 2-wire SDI debug (WCH-LinkE) + BOOT0 + USART1 | — | 8 SMD pads | — | PCB pads (no component) | — | — | PCB copper | — | Pads |  | 0 | 0 | 0.0000 | 0 | 0.00 | — |  | 0 | 0.00 |  | Copper pads only — exclude from the JLCPCB BOM/CPL; pin 1 = N2_J201_3V3 via the DNF R241 (never power the board from the probe) | ,J201, | 1 | 0
2 USB audio bridge (CH32V307 + AGRV2K CPLD + clocks) | J202 | 1 | Pads: CPLD 2-wire Compact-JTAG (J-Link / AGM DAP-Link) | — | 5 SMD pads | — | PCB pads (no component) | — | — | PCB copper | — | Pads |  | 0 | 0 | 0.0000 | 0 | 0.00 | — |  | 0 | 0.00 |  | Copper pads only — exclude from the JLCPCB BOM/CPL; 3V3D sense only | ,J202, | 1 | 0
2 USB audio bridge (CH32V307 + AGRV2K CPLD + clocks) | Q207 | 1 | N-MOSFET, open-drain DAC_RESETB driver (on = DAC reset; gate PA8 + R240 pull-up to 3V3M) | AO3400A | SOT-23 | 30 V, VGS ±12 V, VGS(th) 0.65-1.45 V, RDS(on) ≤ 48 mΩ at 2.5 V | AOS AO3400A | C20917 | Basic | JLCPCB library | JLCPCB Basic (same part as Q502-Q506, Q616, Q617) | Yes |  | 3 | 0 | 0.0524 | 5 | 0.26 | Other: +1 |  | 6 | 0.31 | https://www.aosmd.com/res/datasheets/AO3400A.pdf | New; replaces R233; pins 1 G, 2 S, 3 D (as Q502–Q506) | ,Q207, | 1 | 1
2 USB audio bridge (CH32V307 + AGRV2K CPLD + clocks) | R201, R202, R207, R208, R212, R213, R216-R218, R227, R231, R232, R234, R236, R238, R239 | 16 | 10 k: pull-ups/downs (NRST, BOOT0, BOOT1, I²C SCL/SDA, osc enables, mux inputs, MCLK_EN, MCLK, CPLD_NRST, MCLK_PERMIT, JTMS, JTCK) and the AVCC_EN series R236 | 10 kΩ | 0402 | 1 % | UNI-ROYAL 0402WGF1002TCE | C25744 | Basic | JLCPCB library | JLCPCB Basic | Yes |  | 2 | 0 | 0.0020 | 80 | 0.16 | Passive: +5 %, min +2 |  | 84 | 0.17 | https://www.lcsc.com/product-detail/C25744.html | R212/R213/R218 changed from 2.2 k; R216/R217 now fitted; R227, R231, R232, R234, R236, R238, R239 new; R207/R208 changed to 10 k (I²C at 100 kHz) | ,R201,R202,R207,R208,R212,R213,R216,R217,R218,R227,R231,R232,R234,R236,R238,R239, | 16 | 0 | UNI-ROYAL | 1002 | 10000 | 10000 | OK
2 USB audio bridge (CH32V307 + AGRV2K CPLD + clocks) | R203-R206, R210, R211, R215, R224, R225 | 9 | Series source terminations (MCLK, I²S, osc→mux, mux→CPLD, link) | 33 Ω | 0402 | 1 %, 62.5 mW | UNI-ROYAL 0402WGF330JTCE | C25105 | Basic | JLCPCB library | JLCPCB Basic | Yes |  | 2 | 0 | 0.0020 | 45 | 0.09 | Passive: +5 %, min +2 |  | 48 | 0.10 | https://www.lcsc.com/product-detail/C25105.html | R215 now fitted | ,R203,R204,R205,R206,R210,R211,R215,R224,R225, | 9 | 1 | UNI-ROYAL | 330J | 33 | 33 | OK
2 USB audio bridge (CH32V307 + AGRV2K CPLD + clocks) | R228-R230, R242-R246 | 8 | 330 Ω: I²S capture taps to MCU I²S2 (CPLD side); ADC pin injection limiters PC0-PC4 | 330 Ω | 0402 | 1 %, 62.5 mW | UNI-ROYAL 0402WGF3300TCE | C25104 | Basic | JLCPCB library | JLCPCB Basic | Yes |  | 2 | 0 | 0.0020 | 40 | 0.08 | Passive: +5 %, min +2 |  | 42 | 0.08 | https://www.lcsc.com/product-detail/C25104.html | R242–R246 new (at the MCU pins); LCSC C25104, JLCPCB Basic | ,R228,R229,R230,R242,R243,R244,R245,R246, | 8 | 1 | UNI-ROYAL | 3300 | 330 | 330 | OK
2 USB audio bridge (CH32V307 + AGRV2K CPLD + clocks) | R235, R240 | 2 | 100 k: pull-down at U206 Y (X201 INH / PB1 readback / Q616 gate via R645); Q207 gate pull-up to 3V3M | 100 kΩ | 0402 | 1 % | UNI-ROYAL 0402WGF1003TCE | C25741 | Basic | JLCPCB library | JLCPCB Basic | Yes |  | 2 | 0 | 0.0020 | 10 | 0.02 | Passive: +5 %, min +2 |  | 12 | 0.02 | https://www.lcsc.com/product-detail/C25741.html | R235 and R240 new; same part as R646/R648 | ,R235,R240, | 2 | 0 | UNI-ROYAL | 1003 | 100000 | 100000 | OK
2 USB audio bridge (CH32V307 + AGRV2K CPLD + clocks) | R237 | 1 | AUD_EN series resistor from MCU PC10 | 4.7 kΩ | 0402 | 1 % | UNI-ROYAL 0402WGF4701TCE | C25900 | Basic | JLCPCB library | JLCPCB Basic | Yes |  | 2 | 0 | 0.0020 | 5 | 0.01 | Passive: +5 %, min +2 |  | 7 | 0.01 | https://www.lcsc.com/product-detail/C25900.html | New (lets the 3V3A-good supervisor override the MCU); LCSC number to be confirmed at order | ,R237, | 1 | 1 | UNI-ROYAL | 4701 | 4700 | 4700 | OK
2 USB audio bridge (CH32V307 + AGRV2K CPLD + clocks) | R241 | 1 | J201 pin 1 link to 3V3M (DNF: WCH-LinkE 3V3 is a power output) | 0 Ω | 0402 | jumper | UNI-ROYAL 0402WGF0000TCE | C17168 | Basic | — (DNF) | JLCPCB Basic | No |  | 2 | 0 | 0.0020 | 0 | 0.00 | — |  | 0 | 0.00 | https://www.lcsc.com/product-detail/C17168.html | New DNF link; net N2_J201_3V3 | ,R241, | 1 | 0 | UNI-ROYAL | 0000 | 0 | 0 | OK
2 USB audio bridge (CH32V307 + AGRV2K CPLD + clocks) | U201 | 1 | MCU, RISC-V V4F 144 MHz, USB2.0 HS PHY, own UAC2 firmware | CH32V307RCT6 | LQFP-64M 10 × 10 | 3.3 V, -40…85 °C | WCH CH32V307RCT6 | C2988083 | Extended | JLCPCB library | JLCPCB 364 / LCSC 193 (Sep 2026): thin stock, single source — pre-order 6 (5 boards + 1) | Yes |  | 64 | 0 | 3.4700 | 5 | 17.35 | Other: +1 |  | 6 | 20.82 | https://www.wch-ic.com/downloads/CH32V307DS0_PDF.html | MSL 3 (bake) | ,U201, | 1 | 1
2 USB audio bridge (CH32V307 + AGRV2K CPLD + clocks) | U202 | 1 | CPLD 2K LUT (AG32 silicon): SPI link, FIFO, I²S master, osc/mux/MCLK enables | AGRV2KQ32 | QFN-32 4 × 4, EP 2.7 | 3.3 V, TJ -40…85 °C | AGM AGRV2KQ32 | C18208899 | Extended | JLCPCB library | LCSC 980 (Sep 2026): thin stock, single source — pre-order 6 (5 boards + 1) | Yes | Yes | 33 | 0 | 1.6503 | 5 | 8.25 | Other: +1 |  | 6 | 9.90 | https://www.ag32mcu.com/wp-content/uploads/2026/02/AGRV2K_Rev_3_0.pdf | Programmed via J202 (J-Link / AGM DAP-Link); AGM ships AGRV2K parts marked as the AG32VF303 of the same package (order remark); exposed-pad size and net checked at gate G-3; X-ray | ,U202, | 1 | 1
2 USB audio bridge (CH32V307 + AGRV2K CPLD + clocks) | U205 | 1 | 2:1 clock mux (family select), now fitted | 74LVC1G157 | SOT-363 (TSSOP6) | 1.65-5.5 V, IOFF | Nexperia 74LVC1G157GW,125 | C135822 | Extended | JLCPCB library | LCSC stock | Yes |  | 6 | 0 | 0.2106 | 5 | 1.05 | Other: +1 |  | 6 | 1.26 | https://assets.nexperia.com/documents/data-sheet/74LVC1G157.pdf | S = OSC44_EN; S = L → I0 (X202) | ,U205, | 1 | 1
2 USB audio bridge (CH32V307 + AGRV2K CPLD + clocks) | U206 | 1 | 3-input AND: X201 E/D = MCLK_EN AND AVCC_EN AND MCLK_PERMIT (hardware MCLK stop) | 74LVC1G11 | SOT-363 (TSSOP6) | 1.65-5.5 V, IOFF, inputs 5.5 V tolerant, Schmitt action, tpd ≤ 4.9 ns | Nexperia 74LVC1G11GW-Q100H | C548242 | Extended | JLCPCB library | LCSC 3,690 (Sep 2026) | Yes |  | 6 | 0 | 0.0768 | 5 | 0.38 | Other: +1 |  | 6 | 0.46 | https://assets.nexperia.com/documents/data-sheet/74LVC1G11.pdf | Was 74LVC1G08GW (C12512, SOT353 5-pin); 6-pin SOT363-2 footprint: 1 A, 2 GND, 3 B, 4 Y, 5 VCC, 6 C; input B = N2_AVCC_EN_G; VOH ≥ VCC − 0.1 V vs Kyocera VIH 0.7 VCC; Y also feeds R645 → Q616 | ,U206, | 1 | 1
2 USB audio bridge (CH32V307 + AGRV2K CPLD + clocks) | U208 | 1 | Triple buffer, Ioff (partial power-down), 3V3M → 3V3D domain crossing of LINK_SCK/LINK_MOSI/LINK_FRAME, placed at U202 | 74LVC3G34 | VSSOP-8 0.5 mm (SOT765-1, DC) | 1.65–5.5 V, Ioff ±10 µA (VCC = 0, VI/VO 5.5 V), inputs 5.5 V tolerant, tpd 1.4–4.1 ns (3.3 V ± 0.3 V, −40…85 °C), ICC ≤ 10 µA, MSL 1 260 °C | TI SN74LVC3G34DCUR | C130024 | Extended | JLCPCB library | LCSC 550 (25 Sep 2026), min/multiple 5 — pre-order 10 | Yes |  | 8 | 0 | 0.2012 | 5 | 1.01 | Other: +1 | 10 | 10 | 2.01 | https://assets.nexperia.com/documents/data-sheet/74LVC3G34.pdf | Cost patch: replaces the Nexperia 74LVC3G34DC,125 (C548774, US$ 0.7647) — same DCU pinout 1 1A, 2 3Y, 3 2A, 4 GND, 5 2Y, 6 3A, 7 1Y, 8 VCC (TI datasheet pin table); the Nexperia part is the approved alternate | ,U208, | 1 | 1
2 USB audio bridge (CH32V307 + AGRV2K CPLD + clocks) | X201 | 1 | Oscillator 80 MHz CMOS SPXO (crystal), stand-by pin 1 (oscillation stop) - DAC MCLK only | 80.000 MHz | 2.5 × 2.0 mm 4-pad, plain 2520 land (no 3225 pads) | ±50 ppm (-40…85 °C incl. initial/temp/supply/load/1-yr aging), ICC ≤ 8.0 mA loaded 15 pF (2.8-3.63 V, over temp), stand-by ≤ 5 µA, SYM 45-55 %, tr/tf ≤ 4.5 ns (10-90 %), t_dis ≤ 200 ns, enable/start-up ≤ 2 ms (spec; 3 ms catalogue), VIH ≥ 0.7 VCC, VIL ≤ 0.3 VCC, abs max 4.0 V, reflow 260 °C ×2, MSL 1 | Kyocera KC2520K80.0000C1GE00 | C1988889 | Extended | Global sourcing | LCSC C1988889 not stocked → JLCPCB global sourcing: DigiKey 2,964 (Aug 2026), Mouser 1,375 (+10,000 on order) | Yes | Yes | 4 | 0 | 1.3900 | 5 | 6.95 | Other: +1 |  | 6 | 8.34 | https://ele.kyocera.com/assets/products/crystal-device/specification/KC2520K80.0000C1GE00_e.pdf | Replaces the obsolete Epson SG-210STF 75 MHz (25 Sep 2026); conditional second source NDK NSC5338D-80M (bring-up checks of disable time and edges; 12.7 mA budget; 2520 land; no R509 change); TXC 7X-80.000MBE-T withdrawn; SCTF SX3M80 (C5179978, 3225) not approved and has no land; stand-by driven by U206 | ,X201, | 1 | 1
2 USB audio bridge (CH32V307 + AGRV2K CPLD + clocks) | X202 | 1 | Oscillator 49.152 MHz ultra-low phase noise, stand-by (Hi-Z, osc stops) | 49.152 MHz | 2.5 × 2.0 mm 4-pad, plain 2520 land | ±50 ppm overall, 15 mA max, 35 µA stand-by | NDK NZ2520SDA-49.152MHZ-NSC5083D | — | Extended | Global sourcing | JLCPCB global sourcing: DigiKey 644-NSC5083D-49.152M, 3,438 in stock (24 Sep 2026); JLCPCB record C9900006427 | Yes | Yes | 4 | 0 | 2.0000 | 5 | 10.00 | Other: +1 |  | 6 | 12.00 | https://www.ndk.com/en/products/upload/lineup/pdf/NDKT02-00008_en.pdf | Replaces the 24.576 MHz OT3225 (C2831388); compliant second source SiT8008BI-xx-33S-49.152000 (2.5 × 2.0 mm, 4.3 µA stand-by); SCTF SX3M49.152M20F30TNN (C2901591, 3225) is a non-compliant fallback (output-disable only, both oscillators run, +25 mA: Default power targets not met) and does not fit the 2520 land | ,X202, | 1 | 1
2 USB audio bridge (CH32V307 + AGRV2K CPLD + clocks) | X203 | 1 | Oscillator 45.1584 MHz ultra-low phase noise, stand-by (Hi-Z, osc stops) | 45.1584 MHz | 2.5 × 2.0 mm 4-pad, plain 2520 land | ±50 ppm overall, 15 mA max, 35 µA stand-by | NDK NZ2520SDA-45.1584MHZ-NSC5083D | — | Extended | Global sourcing | JLCPCB global sourcing: DigiKey NSC5083D-45.158M 3,166 (Sep 2026), 24-week factory lead | Yes | Yes | 4 | 0 | 2.0000 | 5 | 10.00 | Other: +1 |  | 6 | 12.00 | https://www.ndk.com/en/products/upload/lineup/pdf/NDKT02-00008_en.pdf | Replaces the 22.5792 MHz SX2M (C5452663); compliant second source SiT8008BI-xx-33S-45.158400; SCTF SX3M45.1584M20F30TNN (C2901589, 3225) is a non-compliant fallback (output-disable only, both oscillators run, +25 mA: Default power targets not met) and does not fit the 2520 land | ,X203, | 1 | 1
2 USB audio bridge (CH32V307 + AGRV2K CPLD + clocks) | Y201 | 1 | Crystal, MCU HSE (USBHS PLL ref = HSE/2 = 4 MHz) | 8 MHz | 5.0 × 3.2 mm 2-pad | ±10 ppm, CL 20 pF | YXC X50328MSB2GI | C115962 | Basic | JLCPCB library | JLCPCB Basic | Yes |  | 2 | 0 | 0.2452 | 5 | 1.23 | Other: +1 |  | 6 | 1.47 | https://www.lcsc.com/product-detail/C115962.html | Kept | ,Y201, | 1 | 1
3 DAC (ES9018K2M) and its supplies | C301 | 1 | LP5907 input (5V_SYS); ≥ 1.04 µF effective at 5.5 V | 2.2 µF | 0603 | 16 V X5R ±10 % | Samsung CL10A225KO8NNNC | C23630 | Basic | JLCPCB library | JLCPCB Basic | Yes |  | 2 | 0 | 0.0120 | 5 | 0.06 | Passive: +5 %, min +2 |  | 7 | 0.08 | https://www.lcsc.com/product-detail/C23630.html | Changed 1 µF → 2.2 µF | ,C301, | 1 | 1 | Samsung CL | 225 | 2.2e-06 | 2.2e-06 | OK
3 DAC (ES9018K2M) and its supplies | C302 | 1 | LP5907 output (3V3A total ≤ 7.6 µF upper bound ≤ 10 µF) | 2.2 µF | 0603 | 16 V X5R ±10 % | Samsung CL10A225KO8NNNC | C23630 | Basic | JLCPCB library | JLCPCB Basic | Yes |  | 2 | 0 | 0.0120 | 5 | 0.06 | Passive: +5 %, min +2 |  | 7 | 0.08 | https://www.lcsc.com/product-detail/C23630.html | Changed 1 µF → 2.2 µF | ,C302, | 1 | 0 | Samsung CL | 225 | 2.2e-06 | 2.2e-06 | OK
3 DAC (ES9018K2M) and its supplies | C303, C304, C310, C439, C440 | 5 | AVCC_L, AVCC_R and DVDD bulk at the DAC pins; C439 DVCC / C440 VCCA after FB301/FB302 | 2.2 µF | 0603 | 16 V X5R ±10 % | Samsung CL10A225KO8NNNC | C23630 | Basic | JLCPCB library | JLCPCB 3.2 M (Sep 2026) | Yes |  | 2 | 0 | 0.0191 | 25 | 0.48 | Passive: +5 %, min +2 |  | 27 | 0.52 | https://www.lcsc.com/product-detail/C23630.html | C439/C440 new (damp the ferrite / 100 nF resonance) | ,C303,C304,C310,C439,C440, | 5 | 0 | Samsung CL | 225 | 2.2e-06 | 2.2e-06 | OK
3 DAC (ES9018K2M) and its supplies | C305-C309 | 5 | HF decoupling at AVCC_L, AVCC_R, VCCA, DVCC, DVDD pins | 100 nF | 0402 | 16 V X7R ±10 % | Samsung CL05B104KO5NNNC | C1525 | Basic | JLCPCB library | JLCPCB stock | Yes |  | 2 | 0 | 0.0045 | 25 | 0.11 | Passive: +5 %, min +2 |  | 27 | 0.12 | https://www.lcsc.com/product-detail/C1525.html |  | ,C305,C306,C307,C308,C309, | 5 | 0 | Samsung CL | 104 | 1e-07 | 1e-07 | OK
3 DAC (ES9018K2M) and its supplies | C311 | 1 | TLV758P input (3V3D) | 1 µF | 0603 | 50 V X5R ±10 % | Samsung CL10A105KB8NNNC | C15849 | Basic | JLCPCB library | As in Parts List v0.6 | Yes |  | 2 | 0 | 0.0060 | 5 | 0.03 | Passive: +5 %, min +2 |  | 7 | 0.04 | https://www.lcsc.com/product-detail/C15849.html | Unchanged part | ,C311, | 1 | 0 | Samsung CL | 105 | 1e-06 | 1e-06 | OK
3 DAC (ES9018K2M) and its supplies | C312 | 1 | TLV758P output (1V3) | 1 µF | 0603 | 50 V X5R ±10 % | Samsung CL10A105KB8NNNC | C15849 | Basic | JLCPCB library | As in Parts List v0.6 | Yes |  | 2 | 0 | 0.0060 | 5 | 0.03 | Passive: +5 %, min +2 |  | 7 | 0.04 | https://www.lcsc.com/product-detail/C15849.html | Unchanged part | ,C312, | 1 | 0 | Samsung CL | 105 | 1e-06 | 1e-06 | OK
3 DAC (ES9018K2M) and its supplies | C441 | 1 | DNF 3V3A capacitor: slows a current-limited 3V3A rise for power-up pop margin | 1 µF | 0603 | 50 V X5R ±10 % | Samsung CL10A105KB8NNNC | C15849 | Basic | — (DNF) | DNF (JLCPCB stock when fitted) | No |  | 2 | 0 | 0.0000 | 0 | 0.00 | — |  | 0 | 0.00 | https://www.lcsc.com/product-detail/C15849.html | With C440 fitted, 3V3A stays ≤ 10 µF effective (LP5907 limit) only with DC-bias credit — confirm before fitting (fallback for the power-up pop, fitted only after the bring-up measurement) | ,C441, | 1 | 0 | Samsung CL | 105 | 1e-06 | 1e-06 | OK
3 DAC (ES9018K2M) and its supplies | FB301, FB302 | 2 | Ferrite beads: 3V3D → DVCC (FB301, 14.2 mA) and 3V3A → VCCA (FB302, 0.8 mA at 22 MHz, ≤ 2.9 mA at 80 MHz (assumption), XI buffer) | 600 Ω @ 100 MHz | 0603 | 200 mA, 0.45 Ω DCR | Sunlord GZ1608D601TF | C1002 | Basic | JLCPCB library | JLCPCB stock | Yes |  | 2 | 0 | 0.0127 | 10 | 0.13 | Passive: +5 %, min +2 |  | 12 | 0.15 | https://www.lcsc.com/product-detail/C1002.html | FB302 new (VCCA branch) | ,FB301,FB302, | 2 | 0
3 DAC (ES9018K2M) and its supplies | R301, R302 | 2 | AVCC_L / AVCC_R feed from 3V3A (separate branches) | 2.2 Ω | 0805 | 1 %, 0.125 W | UNI-ROYAL 0805W8F220KT5E | C17521 | Basic | JLCPCB library | JLCPCB stock | Yes |  | 2 | 0 | 0.0030 | 10 | 0.03 | Passive: +5 %, min +2 |  | 12 | 0.04 | https://www.lcsc.com/product-detail/C17521.html |  | ,R301,R302, | 2 | 1 | UNI-ROYAL | 220K | 2.2 | 2.2 | OK
3 DAC (ES9018K2M) and its supplies | R303 | 1 | AVCC_EN pull-down (LP5907 EN and Q502 gate) | 100 kΩ | 0402 | 1 % | UNI-ROYAL 0402WGF1003TCE | C25741 | Basic | JLCPCB library | As in Parts List v0.6 | Yes |  | 2 | 0 | 0.0033 | 5 | 0.02 | Passive: +5 %, min +2 |  | 7 | 0.02 | https://www.lcsc.com/product-detail/C25741.html | Unchanged; R307 deleted | ,R303, | 1 | 0 | UNI-ROYAL | 1003 | 100000 | 100000 | OK
3 DAC (ES9018K2M) and its supplies | R305 | 1 | DAC RESETB pull-UP to DVCC for the Q207 open-drain driver; 0.33 mA from DVCC only while Q207 holds reset | 10 kΩ | 0402 | 1 % | UNI-ROYAL 0402WGF1002TCE | C25744 | Basic | JLCPCB library | JLCPCB stock | Yes |  | 2 | 0 | 0.0033 | 5 | 0.02 | Passive: +5 %, min +2 |  | 7 | 0.02 | https://www.lcsc.com/product-detail/C25744.html | Changed from a 100 k pull-down to GND; VIH ≥ DVCC/2 + 0.4 V met with ≥ 3.0 V; VOL ≤ 7 mV with Q207; rise 0.4 µs (10–90 %) | ,R305, | 1 | 0 | UNI-ROYAL | 1002 | 10000 | 10000 | OK
3 DAC (ES9018K2M) and its supplies | R533 | 1 | U303 feedback top (OUT → FB) | 15.0 kΩ | 0603 | 0.1 %, 25 ppm/°C, thin film | YAGEO RT0603BRD0715KL | C326733 | Extended (not verified) | JLCPCB library | LCSC 209,580 (25 Sep 2026) | Yes |  | 2 | 0 | 0.0296 | 5 | 0.15 | Passive: +5 %, min +2 |  | 7 | 0.21 | https://www.lcsc.com/product-detail/C326733.html | New | ,R533, | 1 | 1 | YAGEO | 15K | 15000 | 15000 | OK
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

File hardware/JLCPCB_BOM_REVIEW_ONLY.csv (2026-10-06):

Comment | Designator | Footprint | LCSC Part # | MPN
2.2 µF | C102 | Capacitor_SMD:C_0805_2012Metric | C87994 | Samsung CL21A225KAFNNNE
100 pF | C103,C516,C624 | Capacitor_SMD:C_0402_1005Metric | C1546 | Samsung CL05C101JB5NNNC
100 nF | C104,C203,C204,C205,C206,C207,C208,C209,C210,C212,C213,C214,C215,C218,C219,C222,C223,C224,C305,C306,C307,C308,C309,C409,C410,C411,C412,C423,C424,C425,C426,C505,C515,C618,C619,C622,C623,C626,C627,C628,C630,C635,C636,C637,C638,C655,C656,C657,C658,C659,C660,C661,C662,C663,C664,C665,C666,C667 | Capacitor_SMD:C_0402_1005Metric | C1525 | Samsung CL05B104KO5NNNC
33 pF | C201,C202,C421 | Capacitor_SMD:C_0402_1005Metric | C1562 | FH 0402CG330J500NT
2.2 µF | C211 | Capacitor_SMD:C_0402_1005Metric | C12530 | Samsung CL05A225MQ5NSNC
10 nF | C217,C514,C620,C621 | Capacitor_SMD:C_0402_1005Metric | C15195 | Samsung CL05B103KB5NNNC
1 µF | C220,C221,C311,C312,C501,C506,C508,C617 | Capacitor_SMD:C_0603_1608Metric | C15849 | Samsung CL10A105KB8NNNC
2.2 µF | C301,C302,C303,C304,C310,C439,C440,C502 | Capacitor_SMD:C_0603_1608Metric | C23630 | Samsung CL10A225KO8NNNC
10 pF | C401,C402,C403,C404,C405,C406,C407,C408 | Capacitor_SMD:C_0603_1608Metric | C1634 | Samsung CL10C100JB8NNNC
10 µF | C413,C414,C415,C416,C507,C509,C510,C511,C512 | Capacitor_SMD:C_0805_2012Metric | C15850 | Samsung CL21A106KAYNNNE
820 pF | C417,C418,C419,C420 | Capacitor_SMD:C_0603_1608Metric | C2169093 | KEMET C0603C821J5GACTU
1.8 nF | C431,C432,C433,C434,C435,C436,C437,C438 | Capacitor_SMD:C_0603_1608Metric | C97878 | Murata GRM1885C1H182JA01D
220 µF | C442,C443 | JLC_Imported:CASE-D_7343 | C8024 | Kyocera AVX TAJD227K010RNJ
4.7 µF | C608,C609,C610,C611,C616 | Capacitor_SMD:C_0805_2012Metric | C1779 | Samsung CL21A475KAQNNNE
82 pF | C625 | Capacitor_SMD:C_0402_1005Metric | C45501 | FH (Fenghua) 0402CG820J500NT
1 nF | C629,C639,C640,C641,C642 | Capacitor_SMD:C_0402_1005Metric | C307441 | Samsung CL05C102JB5NNNC
220 nF | C631,C632,C633,C634 | DAC_HPA:C631_ECHU1H224GX9_D4 |  | Panasonic ECH-U1H224GX9
3.3 nF | C643,C644,C645,C646 | Capacitor_SMD:C_0603_1608Metric | C190576 | FH 0603CG332J500NT
100 nF | C647,C648,C649,C650,C651,C652,C653,C654 | Capacitor_SMD:C_1206_3216Metric | C46348 | FH 1206CG104J500NT
Nexperia BAT54,215 | D104,D105 | JLC_Imported:SOT-23_L2.9-W1.3-P1.90-LS2.4-BR | C85084 | Nexperia BAT54,215
BAT54S | D405,D406,D407,D408 | JLC_Imported:SOT-23-3_L3.0-W1.7-P0.95-LS2.9-BR | C47546 | Nexperia BAT54S,215
PMEG2010AEH | D411,D412 | JLC_Imported:SOD-123F_L2.8-W1.8-LS3.7-RD | C110921 | Nexperia PMEG2010AEH,115
BAT54 | D413,D414 | JLC_Imported:SOT-23_L2.9-W1.3-P1.90-LS2.4-BR | C85084 | Nexperia BAT54,215
BAS70-04 | D609,D610 | JLC_Imported:SOT-23-3_L2.9-W1.3-P1.90-LS2.4-BR | C389351 | Nexperia BAS70-04,215
5 V | D701,D702,D703,D704,D707,D708 | JLC_Imported:SOD-523_L1.2-W0.8-LS1.6-BI | C41399463 | GOODWORK LESD5D5.0CT1G
Green | D705 | JLC_Imported:LED0805-R-RD | C2297 | Hubei KENTO KT-0805G
Red | D706 | JLC_Imported:LED-SMD_L1.6-W0.8-R-RD | C2286 | Hubei KENTO KT-0603R
600 Ω @ 100 MHz | FB202,FB301,FB302 | Inductor_SMD:L_0603_1608Metric | C1002 | Sunlord GZ1608D601TF
120 Ω @ 100 MHz | FB501 | Inductor_SMD:L_0603_1608Metric | C14709 | Murata BLM18PG121SN1D
GCT USB4105-GF-A | J101 | DAC_HPA:J101_USB4105-GF-A_12lands_4stakes | C3020560 | GCT USB4105-GF-A
X6511WVS-08H-C60D48R1 | J201 | DAC_HPA:PinHeader_1x08_P2.54mm_SMD_XKB_X6511WVS-08H-C60D48R1 | C2883805 | XKB X6511WVS-08H-C60D48R1
X6511WVS-05H-C60D48R1 | J202 | DAC_HPA:PinHeader_1x05_P2.54mm_SMD_XKB_X6511WVS-05H-C60D48R1 | C2883802 | XKB X6511WVS-05H-C60D48R1
HRO PJ-332A-6A | J702 | DAC_HPA:J702_PJ-332A-6A_peg_holes | C2848643 | HRO PJ-332A-6A
AO3400A | Q207,Q502,Q503,Q504,Q505,Q506,Q616,Q617,Q619,Q620,Q622 | JLC_Imported:SOT-23-3_L2.9-W1.3-P1.90-LS2.4-BR | C20917 | AOS AO3400A
MMBT3904 | Q507,Q612,Q614 | JLC_Imported:SOT-23-3_L2.9-W1.3-P1.90-LS2.4-BR | C20526 | JSCJ MMBT3904 (RANGE:100-300)
2N7002 | Q618,Q621 | JLC_Imported:SOT-23-3_L2.9-W1.3-P1.90-LS2.4-BR | C8545 | JSCJ 2N7002
MMBT3904 | Q623,Q624,Q625,Q626,Q627 | JLC_Imported:SOT-23-3_L2.9-W1.6-P1.90-LS2.8-BR | C81464 | onsemi MMBT3904LT1G
5.1 kΩ | R101,R102 | Resistor_SMD:R_0402_1005Metric | C25905 | UNI-ROYAL 0402WGF5101TCE
10 kΩ | R103,R104,R201,R202,R207,R208,R212,R213,R216,R217,R218,R227,R231,R232,R234,R236,R238,R239,R305,R508,R522,R951,R952,R953 | Resistor_SMD:R_0402_1005Metric | C25744 | UNI-ROYAL 0402WGF1002TCE
100 kΩ | R105,R108,R235,R240,R303,R505,R511,R512,R513,R535,R537,R538,R646,R647,R648,R667,R669,R680,R687,R691,R693,R695,R696,R939,R950,R954,R955 | Resistor_SMD:R_0402_1005Metric | C25741 | UNI-ROYAL 0402WGF1003TCE
47 kΩ | R106,R536 | Resistor_SMD:R_0402_1005Metric | C25792 | UNI-ROYAL 0402WGF4702TCE
0 Ω | R107 | Resistor_SMD:R_0402_1005Metric | C17168 | UNI-ROYAL 0402WGF0000TCE
470 kΩ | R109,R532,R688,R689,R935,R936,R937 | Resistor_SMD:R_0402_1005Metric | C25790 | UNI-ROYAL 0402WGF4703TCE
33 Ω | R203,R204,R205,R206,R210,R211,R215,R224,R225 | Resistor_SMD:R_0402_1005Metric | C25105 | UNI-ROYAL 0402WGF330JTCE
330 Ω | R228,R229,R230,R242,R243,R244,R245,R246,R665 | Resistor_SMD:R_0402_1005Metric | C25104 | UNI-ROYAL 0402WGF3300TCE
4.7 kΩ | R237,R643,R644 | Resistor_SMD:R_0402_1005Metric | C25900 | UNI-ROYAL 0402WGF4701TCE
2.2 Ω | R301,R302 | Resistor_SMD:R_0805_2012Metric | C17521 | UNI-ROYAL 0805W8F220KT5E
1.30 kΩ | R401,R403,R405,R407,R409,R411,R413,R415 | Resistor_SMD:R_0603_1608Metric | C705738 | YAGEO RT0603BRD071K3L
2.00 kΩ | R402,R404,R406,R408,R410,R412,R414,R416 | Resistor_SMD:R_0603_1608Metric |  | Susumu RG1608N-202-W-T1
0 Ω | R417,R418,R419,R420 | Resistor_SMD:R_0402_1005Metric | C4044221 | YAGEO PA0402-R-070RL
698 Ω | R423,R424,R425,R426 | Resistor_SMD:R_0603_1608Metric | C861525 | YAGEO RT0603BRD07698RL
9.76 kΩ | R431 | Resistor_SMD:R_0603_1608Metric | C861616 | YAGEO RT0603BRD079K76L
10.0 kΩ | R432 | Resistor_SMD:R_0603_1608Metric | C95204 | YAGEO RT0603BRD0710KL
680 Ω | R438,R439,R440,R441,R442,R443,R444,R445 | Resistor_SMD:R_0603_1608Metric | C861519 | YAGEO RT0603BRD07680RL
221 kΩ | R501 | Resistor_SMD:R_0603_1608Metric | C705748 | YAGEO RT0603BRD07221KL
100 kΩ | R502,R504 | Resistor_SMD:R_0603_1608Metric | C122538 | YAGEO RT0603BRD07100KL
205 kΩ | R503 | Resistor_SMD:R_0603_1608Metric | C861217 | YAGEO RT0603BRD07205KL
3.74 kΩ | R510 | Resistor_SMD:R_0603_1608Metric | C861382 | YAGEO RT0603BRD073K74L
22 kΩ | R526,R528 | Resistor_SMD:R_0402_1005Metric | C25768 | UNI-ROYAL 0402WGF2202TCE
10 Ω | R527,R529 | Resistor_SMD:R_0603_1608Metric | C22859 | UNI-ROYAL 0603WAF100JT5E
4.7 Ω | R530 | Resistor_SMD:R_0603_1608Metric | C23164 | UNI-ROYAL 0603WAF470KT5E
15.0 kΩ | R533 | Resistor_SMD:R_0603_1608Metric | C326733 | YAGEO RT0603BRD0715KL
11.0 kΩ | R534 | Resistor_SMD:R_0603_1608Metric | C728581 | YAGEO RT0603BRD0711KL
6.8 kΩ | R624,R625,R626,R627,R658,R661 | Resistor_SMD:R_0402_1005Metric | C33900832 | YAGEO RP0402BRD076K8L (RT0402BRD076K8L alt.)
5.1 kΩ | R628,R629,R630,R631,R639,R663 | Resistor_SMD:R_0402_1005Metric | C852856 | YAGEO RT0402BRD075K1L
16.9 kΩ | R632,R633,R634,R635,R640 | Resistor_SMD:R_0402_1005Metric | C852560 | YAGEO RT0402BRD0716K9L
24.9 Ω | R641,R642 | Resistor_SMD:R_0402_1005Metric | C852667 | YAGEO RT0402BRD0724R9L
1 kΩ | R645,R692,R701 | Resistor_SMD:R_0402_1005Metric | C11702 | UNI-ROYAL 0402WGF1001TCE
100 kΩ | R653,R654,R655,R656,R662,R673,R925 | Resistor_SMD:R_0402_1005Metric | C852472 | YAGEO RT0402BRD07100KL
10.0 kΩ | R657,R659,R670 | Resistor_SMD:R_0402_1005Metric | C190095 | YAGEO RT0402BRD0710KL
330 kΩ | R660,R690,R694,R916,R917,R918,R919,R926,R927,R928,R929 | Resistor_SMD:R_0402_1005Metric | C25778 | UNI-ROYAL 0402WGF3303TCE
1.00 MΩ | R666,R668,R930,R931,R932,R933,R938,R940 | Resistor_SMD:R_0402_1005Metric | C26083 | UNI-ROYAL 0402WGF1004TCE
2.2 MΩ | R671 | Resistor_SMD:R_0402_1005Metric | C54530777 | SAE 1RC0402F2204
237 kΩ | R672 | Resistor_SMD:R_0402_1005Metric | C852654 | YAGEO RT0402BRD07237KL
2.2 kΩ | R674,R702 | Resistor_SMD:R_0402_1005Metric | C25879 | UNI-ROYAL 0402WGF2201TCE
44.2 kΩ | R675,R682 | Resistor_SMD:R_0402_1005Metric | C705633 | YAGEO RT0402BRD0744K2L
200 kΩ | R676,R683 | Resistor_SMD:R_0402_1005Metric | C728556 | YAGEO RT0402BRD07200KL
300 kΩ | R677,R684 | Resistor_SMD:R_0603_1608Metric | C705762 | YAGEO RT0603BRD07300KL
1.00 MΩ | R678,R685,R901,R903,R905,R907,R909,R911,R913,R915 | Resistor_SMD:R_0603_1608Metric | C326730 | YAGEO RT0603BRD071ML
22 MΩ | R679,R686 | Resistor_SMD:R_0402_1005Metric | C407703 | UNI-ROYAL 0402WGF2205TCE
4.7 MΩ | R681 | Resistor_SMD:R_0402_1005Metric | C54530892 | SAE 1RC0402F4704
487 kΩ | R900,R902,R904,R906,R908,R910,R912,R914 | Resistor_SMD:R_0603_1608Metric | C861426 | YAGEO RT0603BRD07487KL
110 kΩ | R920,R921,R922,R923 | Resistor_SMD:R_0402_1005Metric | C705063 | YAGEO RT0402BRD07110KL
69.8 kΩ | R924 | Resistor_SMD:R_0402_1005Metric | C852893 | YAGEO RT0402BRD0769K8L
360 kΩ | R934 | Resistor_SMD:R_0402_1005Metric | C45956 | UNI-ROYAL 0402WGF3603TCE
88.7 kΩ | R941 | Resistor_SMD:R_0402_1005Metric | C25922 | UNI-ROYAL 0402WGF8872TCE
910 kΩ | R942,R943,R944,R945,R946,R947,R948,R949 | Resistor_SMD:R_0402_1005Metric | C25800 | UNI-ROYAL 0402WGF9103TCE
ST USBLC6-2SC6 | U101 | JLC_Imported:SOT-23-6_L2.9-W1.6-P0.95-LS2.8-BL | C7519 | ST USBLC6-2SC6
TI TPS25200DRVR | U102 | DAC_HPA:WSON-6_L2.0-W2.0-P0.65-TL-EP_PAD | C128401 | TI TPS25200DRVR
TI TPD2E2U06DRLR | U103 | JLC_Imported:SOT-553-5_L1.6-W1.2-P0.50-LS1.6-TL-1 | C1972959 | TI TPD2E2U06DRLR
CH32V307RCT6 | U201 | JLC_Imported:LQFP-64_L10.0-W10.0-P0.50-LS12.0-BL | C2988083 | WCH CH32V307RCT6
AGRV2KQ32 | U202 | DAC_HPA:QFN-32_L4.0-W4.0-P0.40-BL-EP2.7_EP | C18208899 | AGM AGRV2KQ32
74LVC1G157 | U205 | JLC_Imported:SOT-363_L2.0-W1.3-P0.65-LS2.1-BR | C135822 | Nexperia 74LVC1G157GW,125
74LVC1G11 | U206 | JLC_Imported:SC-88-6_L2.0-W1.3-P0.65-LS2.1-BL | C548242 | Nexperia 74LVC1G11GW-Q100H
74LVC3G34 | U208 | JLC_Imported:VSSOP-8_L2.1-W2.4-P0.50-LS3.2-BR | C130024 | TI SN74LVC3G34DCUR
ES9018K2M | U301 | DAC_HPA:QFN-28_L5.0-W5.0-P0.50-BL-EP3.3_EP | C2688377 | ESS ES9018K2M
3.3 V, 250 mA | U302 | JLC_Imported:SOT-23-5_L3.0-W1.7-P0.95-LS2.8-BR | C80670 | TI LP5907MFX-3.3/NOPB
1.300 V (R533/R534) | U303 | JLC_Imported:SOT-23-5_L3.0-W1.7-P0.95-LS2.8-BR | C2877852 | TI TLV75801PDBVR
OPA1622IDRCR | U401,U402 | DAC_HPA:VSON-10_L3.0-W3.0-P0.50-BL-EP1.65_PAD | C2876559 | TI OPA1622IDRCR
OPA2210IDGKR | U403,U404 | JLC_Imported:VSSOP-8_L3.0-W3.0-P0.65-LS5.0-BL | C2876414 | TI OPA2210IDGKR
+3.85 / -3.72 V | U501 | DAC_HPA:WSON-12_L3.0-W2.0-P0.50-BL-EP_PAD | C473398 | TI LM27762DSSR
3.3 V, 150 mA | U502 | JLC_Imported:SOT-23-5_L3.0-W1.7-P0.95-LS2.8-BR | C89347 | TI TPS70933DBVR
TI TPS259621DDAR | U503 | DAC_HPA:ESOP-8_L4.9-W3.9-P1.27-LS6.0-BL-EP_PAD | C2155774 | TI TPS259621DDAR
3.3 V, 1 A | U504 | DAC_HPA:WSON-6_L2.0-W2.0-P0.65-TL-EP_PAD | C2848334 | TI TLV76733DRVR
TI TMUX1101DBVR | U505 | JLC_Imported:SOT-23-5_L2.9-W1.6-P0.95-LS2.8-BR | C1852057 | TI TMUX1101DBVR
TLV1704 | U603,U606,U609,U610,U611,U612 | JLC_Imported:TSSOP-14_L5.0-W4.4-P0.65-LS6.4-BL | C181596 | TI TLV1704AIPWR
OPA2333 | U604 | JLC_Imported:SOP-8_L4.9-W3.9-P1.27-LS6.0-BL | C38732 | TI OPA2333AIDR
TLV3402 | U605 | JLC_Imported:SOIC-8_L4.9-W3.9-P1.27-LS6.0-BL | C91242 | TI TLV3402IDR
74AUP1G17 | U607 | JLC_Imported:TSSOP-5_L2.1-W1.3-P0.65-LS2.2-BR | C545626 | Nexperia 74AUP1G17GW,125
74LVC1G74 | U608 | JLC_Imported:VSSOP-8_L2.3-W2.0-P0.50-LS3.1-BR | C503431 | Nexperia 74LVC1G74DC,125
TLV3402 | U613,U614,U615,U616,U617,U618,U619,U620 | JLC_Imported:VSSOP-8_L3.0-W3.0-P0.65-LS5.0-BL | C140314 | TI TLV3402IDGKR
SN74AUP2G17DCKR | U621 | JLC_Imported:SC-70-6_L2.2-W1.3-P0.65-LS2.1-BL | C507231 | TI SN74AUP2G17DCKR
80.000 MHz | X201 | DAC_HPA:X201_KC2520K80_Kyocera | C1988889 | Kyocera KC2520K80.0000C1GE00
49.152 MHz | X202 | DAC_HPA:X202_X203_NDK_NZ2520SDA |  | NDK NZ2520SDA-49.152MHZ-NSC5083D
45.1584 MHz | X203 | DAC_HPA:X202_X203_NDK_NZ2520SDA |  | NDK NZ2520SDA-45.1584MHZ-NSC5083D
8 MHz | Y201 | JLC_Imported:CRYSTAL-SMD_L5.0-W3.2 | C115962 | YXC X50328MSB2GI

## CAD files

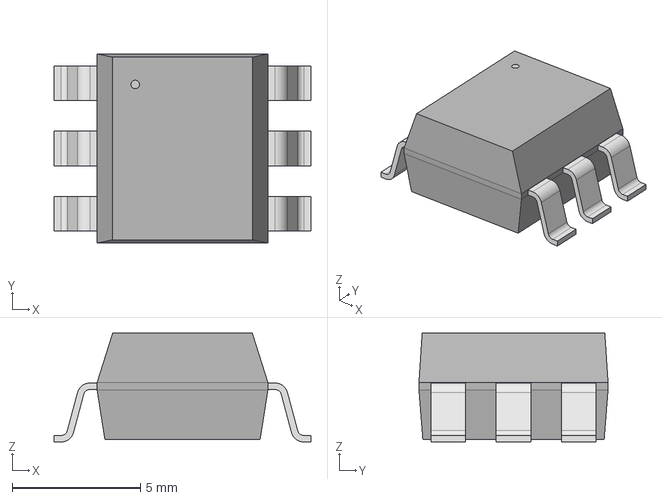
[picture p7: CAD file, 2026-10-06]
hardware/DAC_HPA_3D/TLP3545A_LF1_UltraLibrarian.step
10.0 x 7.37 x 4.24 mm

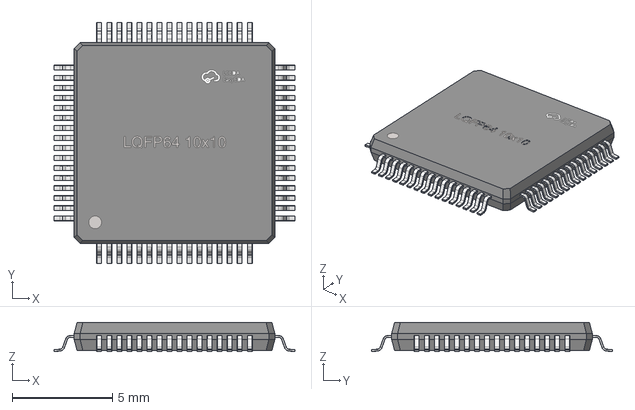
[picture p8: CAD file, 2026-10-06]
hardware/EASYEDA_MODELS/LQFP-64_L10.0-W10.0-H1.4-LS12.0-P0.50.step
12.0 x 12.0 x 1.45 mm

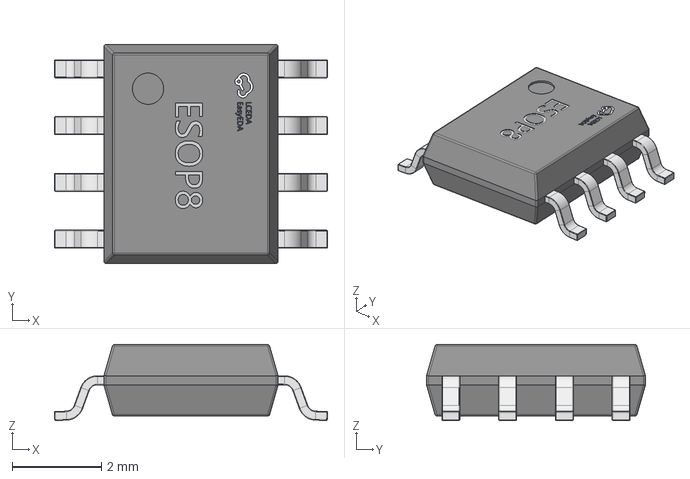
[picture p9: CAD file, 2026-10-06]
hardware/EASYEDA_MODELS/ESOP-8_L4.9-W3.9-H1.6-LS6.0-P1.27.step
6.11 x 4.90 x 1.70 mm

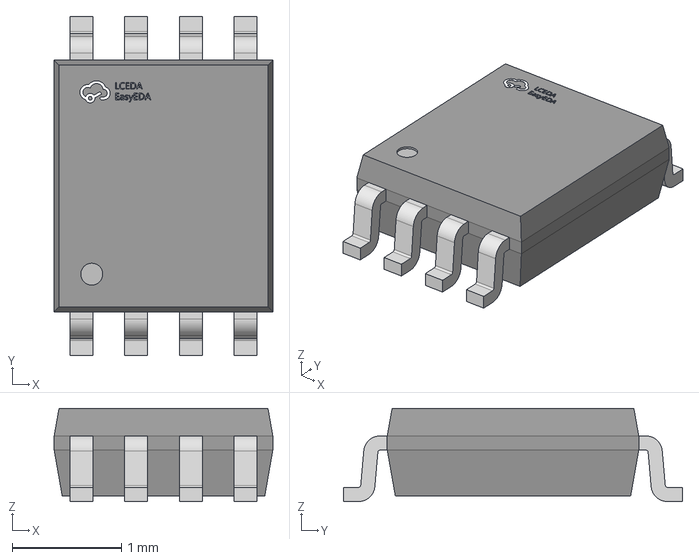
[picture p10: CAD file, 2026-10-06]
hardware/EASYEDA_MODELS/VSSOP-8_L2.3-W2.0-P0.50-LS3.1-BL.step
2.00 x 3.10 x 0.851 mm

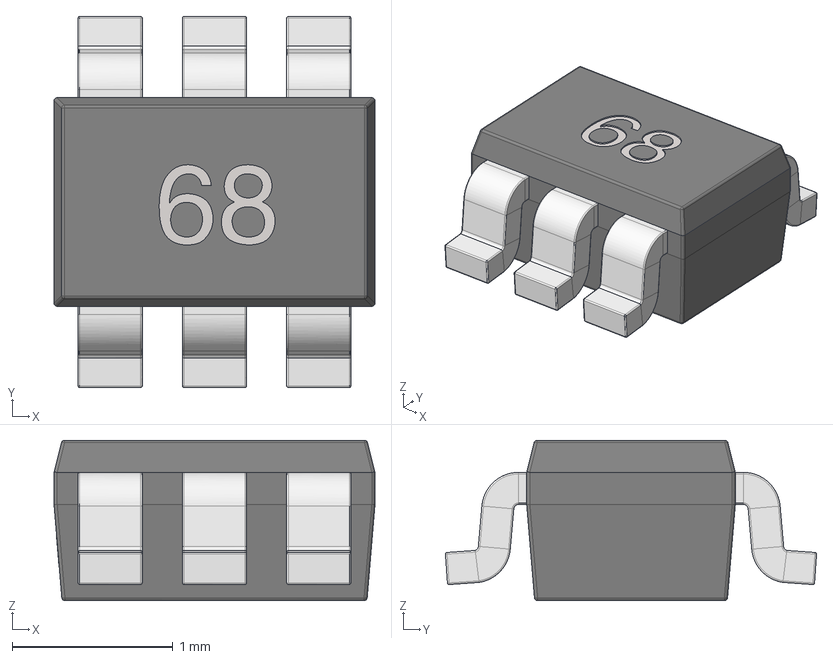
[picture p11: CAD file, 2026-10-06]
hardware/EASYEDA_MODELS/SC-88-6P_L2.0-W1.3-H1.0-LS2.1.step
2.00 x 2.31 x 1.00 mm

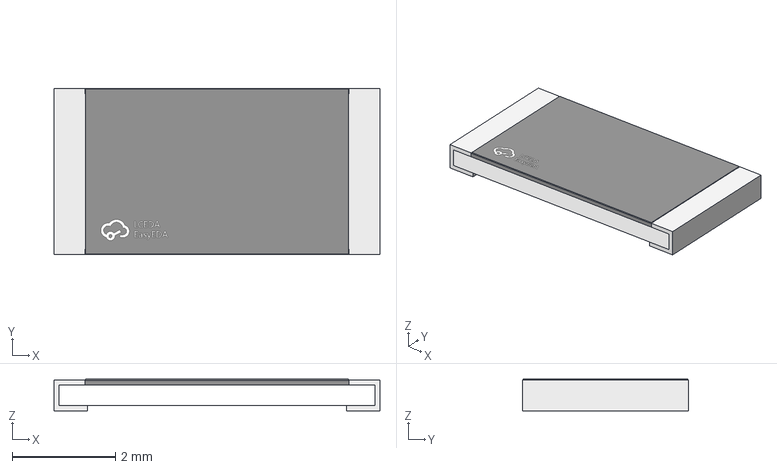
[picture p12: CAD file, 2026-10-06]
hardware/EASYEDA_MODELS/R2512_L6.3-W3.2-H0.6.step
6.30 x 3.20 x 0.611 mm

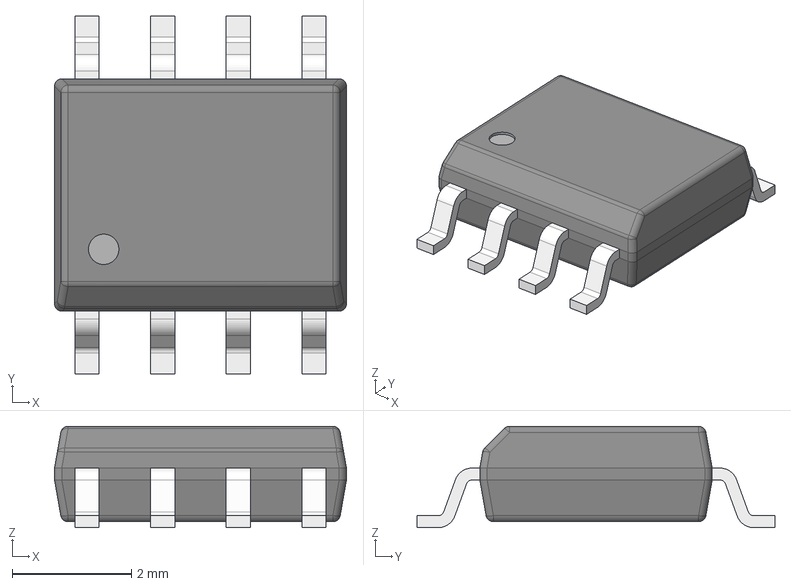
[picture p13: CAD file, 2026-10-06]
hardware/EASYEDA_MODELS/SOIC-8_L4.9-W3.9-H1.7-LS6.0-P1.27.step
4.90 x 6.00 x 1.70 mm

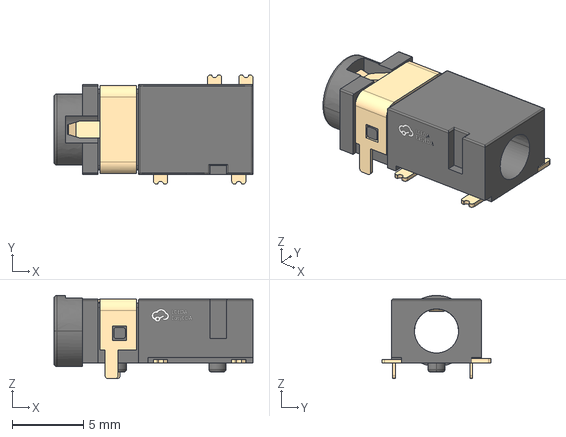
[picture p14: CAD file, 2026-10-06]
hardware/EASYEDA_MODELS/AUDIO-SMD_PJ-332A-6A.step
14.0 x 7.70 x 5.85 mm

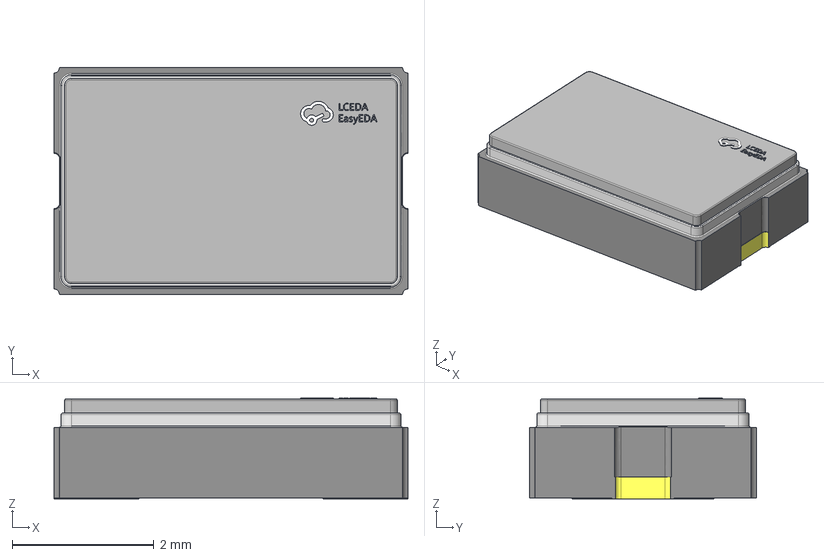
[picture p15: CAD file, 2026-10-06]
hardware/EASYEDA_MODELS/CRYSTAL-SMD_L5.0-W3.2.step
5.00 x 3.20 x 1.42 mm

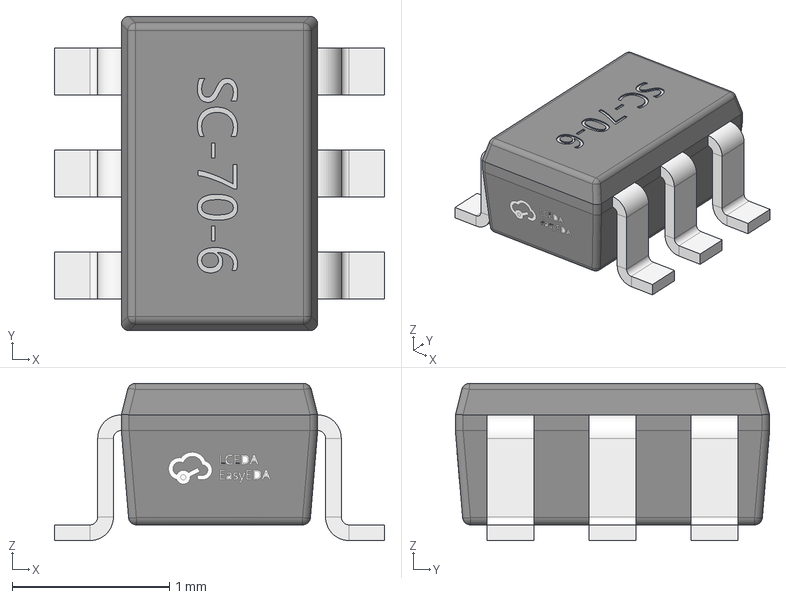
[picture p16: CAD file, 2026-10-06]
hardware/EASYEDA_MODELS/SC-70-6_L2.0-W1.3-H1.0-P0.65.step
2.10 x 2.00 x 1.00 mm

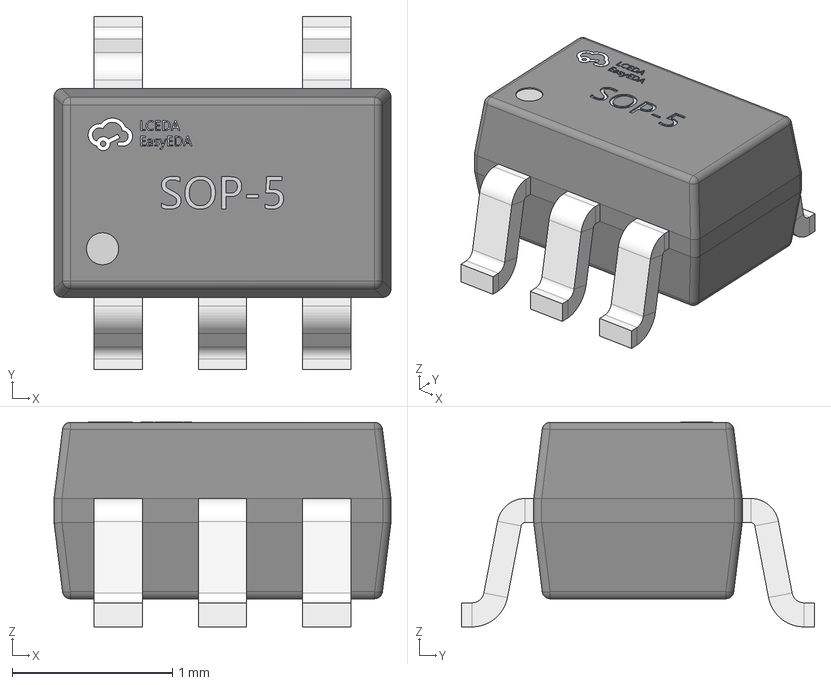
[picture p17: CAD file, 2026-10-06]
hardware/EASYEDA_MODELS/TSSOP-5_L2.1-W1.3-H1.1-LS2.2-P0.65.step
2.10 x 2.20 x 1.28 mm

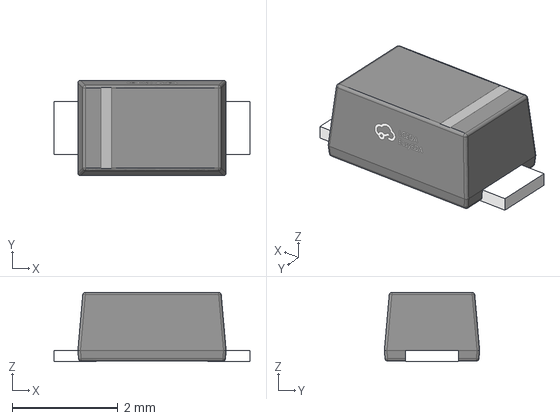
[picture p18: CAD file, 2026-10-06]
hardware/EASYEDA_MODELS/SOD-123FL_L2.8-W1.8-LS3.7-RD-1.step
3.70 x 1.80 x 1.31 mm

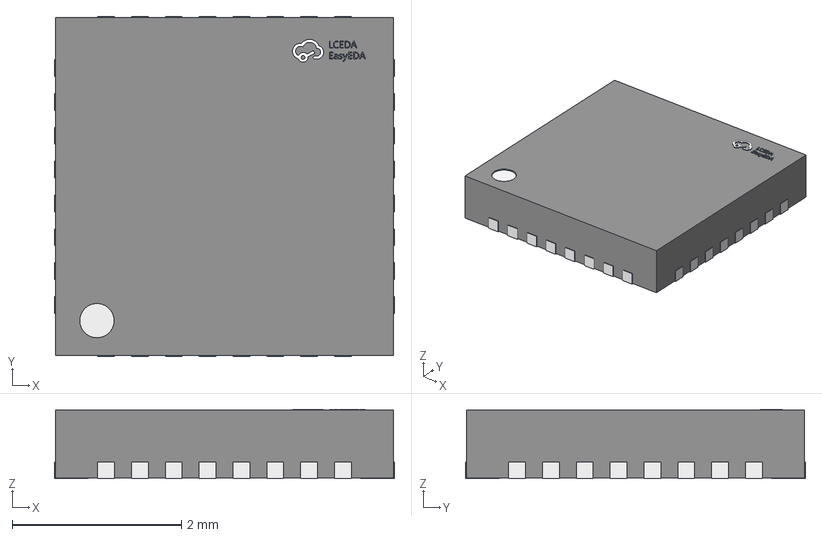
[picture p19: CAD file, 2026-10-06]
hardware/EASYEDA_MODELS/QFN-32_L4.0-W4.0-H0.8-P0.40.step
4.02 x 4.02 x 0.82 mm

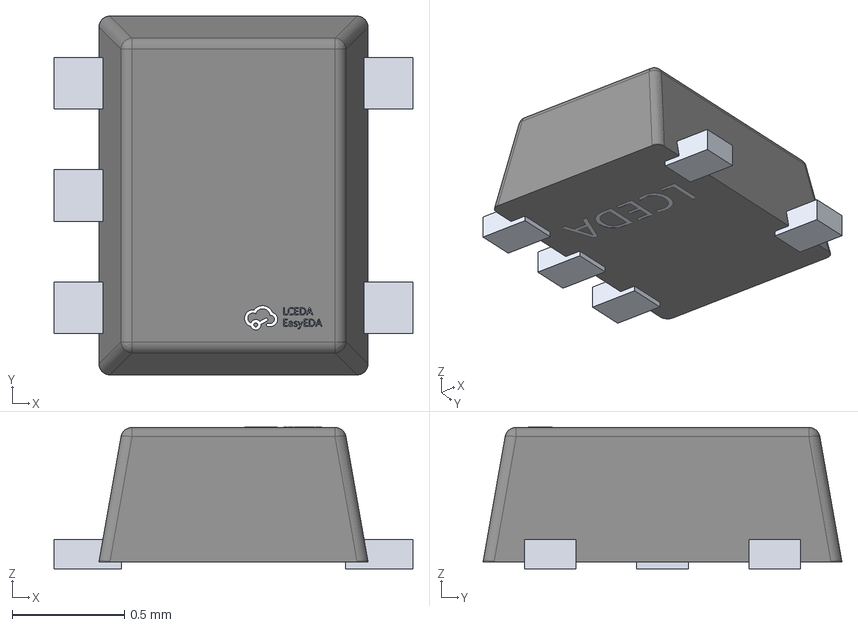
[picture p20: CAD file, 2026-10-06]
hardware/EASYEDA_MODELS/SOT-553-5_L1.6-W1.2-P0.50-LS1.6-TL-1.step
1.60 x 1.60 x 0.631 mm

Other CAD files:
hardware/EASYEDA_MODELS/LED0603_L1.6-W0.8-H0.6.step
hardware/EASYEDA_MODELS/SOT-23-6_L2.9-W1.6-H1.5-LS2.8-P0.95.step
hardware/EASYEDA_MODELS/VSON-10_L3.0-W3.0-P0.50-BL-EP1.65.step
hardware/EASYEDA_MODELS/VSSOP-8_L3.0-W3.0-H1.1-LS4.9-P0.65.step
hardware/EASYEDA_MODELS/AUDIO-TH_GT-3321667P-01.step
hardware/EASYEDA_MODELS/CASE-D_L7.3-W4.3-H2.9.step
hardware/EASYEDA_MODELS/LED0805-RD.step
hardware/EASYEDA_MODELS/QFN-28_L5.0-W5.0-H0.9-P0.50.step
hardware/EASYEDA_MODELS/SOD-523_L1.2-W0.8-LS1.6-BI.step
hardware/EASYEDA_MODELS/SOP-8_L4.9-W3.9-P1.27-LS6.0-BL-1.step
hardware/EASYEDA_MODELS/SOT-23-3L_L2.9-W1.6-H1.1-LS2.8-P0.95.step
hardware/EASYEDA_MODELS/SOT-23-3P_L2.9-W1.3-H1.0-LS2.4-P0.95.step
hardware/EASYEDA_MODELS/SOT-23-5_L2.9-W1.6-H1.1-LS2.8-P0.95.step
hardware/EASYEDA_MODELS/SOT-23-5_L2.9-W1.6-P0.95-LS2.8-BR.step
hardware/EASYEDA_MODELS/SOT-363-6P_L2.0-W1.3-H1.1-LS2.0-P0.65.step
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

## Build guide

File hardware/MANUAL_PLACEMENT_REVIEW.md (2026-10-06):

# DAC-HPA manual 120 × 100 mm layout review — 27 September 2026

**Routing release: HOLD.** The editable primary board is [`DAC_HPA.kicad_pcb`](DAC_HPA.kicad_pcb), now 120 × 100 mm. Every footprint movement in this iteration uses explicit, engineer-selected coordinates in `manual_relayout.py`, `manual_100mm_timer_study.py`, `manual_120x100_study.py`, `manual_120x100_top_access_study.py`, and `manual_clock_escape_study.py`. No placement search or packing was run. `manual_esd_route_probe.py` draws only four manually selected J701 TVS escapes, four short GND stubs and vias, and a continuous L2 GND zone. `place_board.py` now regenerates the separate 100 × 100 mm baseline comparison, not the primary board.

See the [whole board](DAC_HPA_120x100_manual_preview.png), [J701 output detail](DAC_HPA_120x100_output_zoom.png), [timer detail](DAC_HPA_120x100_timer_zoom.png), [clock/analog boundary detail](DAC_HPA_120x100_clock_zoom.png), and [100 × 100 mm timer comparison](DAC_HPA_100x100_timer_preview.png). These images show F.Cu, F.Fab, F.CrtYd and Edge.Cuts from the KiCad PCB, not a conceptual floorplan.

| Read-only check | 100 × 100 mm comparison | 120 × 100 mm primary |
| --- | ---: | ---: |
| Footprints / named nets | 536 / 246 | 536 / 246 |
| Footprint bounding-box overlaps | 0 | 0 |
| JLC classified package-body spacing proxy findings | 0 | 0 |
| JLC classified body-to-edge proxy findings | 0 | 0 |
| Obstructions in the two reserved L1 output corridors | 0 | 0 |
| Worst timer C/R/Q Manhattan pad-distance lower bound | 7.91 mm | 7.91 mm |
| Sensitive-to-clock pad-gap findings | 15 | 0 |
| KiCad DRC errors / warnings | 9 / 0 | 0 / 0 |
| Tracks / vias / filled zones | 0 / 0 / 0 | 8 / 4 / 1 |
| Other unconnected items reported by KiCad | 499 | 499 |

The 100 × 100 mm comparison still has nine J701 top-side solder-access errors. The owner kept 1.5 mm top-side iron clearance and allowed the wider 120 × 100 mm outline. The larger board moves the four TVS diodes outside J701's hand-access courtyard, makes room for the two relay rows, and leaves the L1 output corridors clear. It also removes the previous sensitive-pad proximity to MCLK/I²S/clock-monitor pads without requiring a split ground plane. The L2 zone in the primary is one filled GND polygon; L1 output, digital and analog return paths still require review after all routes are drawn.

## Provisional J701 ESD escape

The owner approved a **provisional ≤4.2 mm signal path** in place of the old 3 mm target, with short TVS ground returns and a system IEC ESD test. This is a design decision for the primary review board, not a JLCPCB assembly limit. The four hand-drawn 0.5 mm F.Cu tracks are D701→J701.7 = 3.83 mm, D702→J701.5 = 4.03 mm, D703→J701.6 = 4.03 mm, and D704→J701.2 = 4.03 mm. Each D701–D704 GND pad has a 1.02 mm 0.5 mm-wide stub to a Ø0.60/0.20 mm via into the filled L2 GND plane. `audit_esd_routes.py` checks the committed copper, and KiCad DRC reports zero errors and warnings. ESD testing, return-current measurement and protection validation are still required.

J701's fixed plated contact pitch cannot meet the project's general 2 mm L/R output-copper separation at its pads. The KiCad custom-rule exception is limited to a track within J701's courtyard against a J701 pad, with 0.20 mm minimum copper clearance. The 2 mm L/R rule remains outside that fanout. A routed crosstalk and return-path review must verify the short exception does not harm audio performance.

## JLCPCB DFA/DFM screen

The KiCad project minima and read-only package/fabrication screens are described in [`JLCPCB_DFA_DFM_RULES.md`](JLCPCB_DFA_DFM_RULES.md). The JLC package-pair screen covers 435 classified parts of 455 listed JLC-placed parts and reports zero body-spacing findings; 20 unclassified parts need individual review. The J101 body crosses the left board edge by 0.05 mm and J702 is 0.33 mm from the right edge, both outside JLC's general 2.5 mm body-to-finished-edge term. The connector/panel arrangement requires JLC acceptance. Enlarged slot lands have a ≥0.31 mm worst ring under JLC's +0.13 mm plated-slot tolerance; physical G-3 overlays, mask geometry and JLC DFM acceptance remain open. After trimming the J702 legend and adjusting D102/X201 polarity marks, KiCad's silkscreen warning pass is clear.

## Work still needed before routing release

1. **Complete actual routing.** The primary has only the four TVS signal and GND returns. KiCad still reports 499 unconnected items. The 0.5 mm L1 headphone outputs, ≥3 mm dedicated headphone GND return, relay contacts, L/R grounded separation, power feeds, USB pair, I²S and MCLK routes are not complete. Check clearances and return continuity after each routed group.
2. **Close length and signal-integrity checks.** The four timer branches have only a ≤7.91 mm Manhattan pad-distance lower bound against the 8 mm route rule. The I²S source→series resistor→DAC straight lower bounds are 22.82/19.91/22.05 mm against 25 mm; routed lengths and skew are unknown. The MCLK path through TP711 has a 10.77 mm straight lower bound against the 10 mm limit, so that branch needs a disposition. DAC-to-I/V, feedback-loop area, USB impedance and high-impedance-versus-clock copper clearance still require routes and extraction.
3. **Close audio and assembly gates.** Relay-to-jack routes and the meaning of the 20 mm requirement for J701 paired contacts need a routed review. G-3 sample overlays and G-4 polarity checks remain open. Obtain JLC's treatment of J101/J702 edge placement, plated-slot soldering, J701 mask openings, unclassified package gaps and panel rails before ordering. The source DOCX/XLSX design set still states the older outline and ESD target and needs a controlled revision before manufacturing freeze.

A passing placement, JLC proxy, or KiCad DRC check does not demonstrate completed routing, USB impedance, THD+N, crosstalk, EMI immunity, output impedance or a buildable PCBA package. Do not submit this partial board for production.

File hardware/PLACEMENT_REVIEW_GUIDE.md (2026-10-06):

# Placement, routability and PCBA peer-review guide

Start with the 120 × 100 mm integrated-audio study and its [electrical-margin review](INTEGRATED_AUDIO_ROUTE_STUDY.md), then use the newer [DAC/core route checkpoint](DAC_CORE_ROUTE_STUDY.md) for the current DAC/CPLD route measurements. Compare with the [functional-ECO capture baseline](DAC_HPA_120x100_FUNCTIONAL_ECO_STUDY_ONLY.kicad_pcb), its [whole-board preview](DAC_HPA_FUNCTIONAL_ECO_PLACEMENT_REVIEW.png) and [layout review](FUNCTIONAL_ECO_LAYOUT_REVIEW.md). The GitLab `deliver_review_package` artifact provides zoomable SVG and GLB 3D views for the reviewed commit. Record board coordinates, layer and references for findings. The earlier 536-footprint primary and 100 × 80/100 × 100 mm boards do not match the eight-part ECO schematic.

The [earlier macro-placement review](MACRO_PLACEMENT_REVIEW.md) explains the first subcircuit regrouping. The functional-ECO baseline improves the DAC supply-capacitor row and hold-up-reservoir access, and adds the J702 local TVS/readback parts. The [intermediate 270° output study](OUTPUT_MACRO_ROUTE_STUDY.md) proves four amplifier-to-relay inputs and feedback loops. The integrated study continues those paths to the physical jack contacts and adds DAC/I/V-to-T and U501 local copper under the [A/B-channel schematic ECO](FUNCTIONAL_ECO_2026-09-28.md). Use the [constraint disposition](CONSTRAINT_DISPOSITION_V2.md) for each board.

For scalable per-layer views, run the one-command [CLI visual inspection workflow](PCB_CLI_VISUAL_REVIEW.md) on the integrated board without modifying it.

**Board and route snapshots:** The functional-ECO capture baseline has 544 footprints, 250 named PCB nets, 28 F.Cu tracks, seven vias and one filled L2 GND zone; it contains J701/J702 TVS branches and the 8.311 mm X201→R203→U301 MCLK trunk. The later integrated-audio candidate has 544 footprints, 250 named nets and 855 track/via items (143 vias), with **zero KiCad DRC violations, 499 DRC-reported unconnected items and 864 full ratsnest links**. Its current manual record is **138 explicit moves, eight removed source copper items and 828 added copper items**, zero exact 90° and free 80–100° track bends, zero classified JLC spacing findings, four DAC→I/V routes, eight I/V→first-T feeds, eight connected local T triplets, U501 local switching/feedback copper and four connected amplifier-to-jack output paths. The newer [DAC/core checkpoint](DAC_CORE_ROUTE_STUDY.md) measures MCLK at **8.381 mm**, BCLK/LRCLK/SDATA at **22.213/22.324/22.879 mm**, and the connected U303→DAC 1V3 route at **25.393 mm** with two vias. Two U202 and five U301 EP vias are filled/capped; the via-pad audit reports 45 nearby unfilled sites for JLC mask/process review. U401/U402 output-amplifier EP thermal paths remain open. Full routing, system ESD, EMI, audio testing and JLC process acceptance remain open. All 478 populated component footprints resolve 3D bodies.

## Review order

| Priority | What to establish | Present evidence and open test |
| --- | --- | --- |
| 1. Connector and hand access | Physical jack/USB fit, board-edge mating, top-side soldering access and package-to-package space. | [G-3 1:1 overlays](G3_OVERLAY_INDEX.md) and [G-4 polarity](G4_POLARITY_CHECKLIST.md) are open. J101 and J702 need JLCPCB acceptance at finished edges and a confirmed soldering process for plated slots. J701's 1.5 mm top-side iron access is preserved in the manual primary. |
| 2. Critical simultaneous routes | Establish drawable paths with feedback and returns present. | See the route-risk table below. DAC/I/V signal copper is drawn, but long right-side cross-layer feeds, true feedback/return loops, amplifier source rails and U501 return currents still need extraction and validation. The board remains partly unrouted. |
| 3. Audio and EMI topology | Preserve a single continuous L2 GND reference, quiet I/V/VREF, isolated high-impedance nodes, and a dedicated jack return. | The present L2 GND zone covers the board, but no complete output/clock/power return-current review is possible until routes, stitching and L4 pours exist. Use [Audio/EMI placement review](AUDIO_EMI_PLACEMENT_REVIEW.md), reading its old 100 × 100 mm examples as historical. |
| 4. Fabrication and assembly | Check actual JLCPCB policy, design rules, custom lands, pick-and-place access and BOM fit. | [JLC DFA/DFM rules](JLCPCB_DFA_DFM_RULES.md) and audits are screens only. The current conservative proxy classifies the new U621 and SOD-523 devices; 16 placed references remain outside its package table. Enlarged jack lands, panel rails and slot soldering need order-specific review. |

## Route-risk ledger for the capture baseline and integrated study

| Circuit | Current geometry | Reviewer decision or evidence needed |
| --- | --- | --- |
| X201 → R203 → U301 MCLK | Current hand-drawn L1 route passes through TP711: X201→R203 **1.832 mm**, R203→U301 **6.549 mm**, combined **8.381 mm**. The earlier functional-ECO baseline measured 8.311 mm. R227 has a local GND via and R665→U607 pin 2 is connected; DNF R703 remains unrouted. | Inspect clock edge quality, oscillator supply/return loop, probe loading, actual duty and U607 monitor behavior. The route meets the geometric 2/8/10 mm screens, but extracted parasitics and powered validation remain open. |
| U609/U610 timer branches | All 12 named-pad timer branches pass the ≤8 mm screen without timer-net vias. U609 LP C/Q/R lengths are **6.089/5.340/4.943 mm** and LN **6.038/5.814/6.685 mm**; U610 lengths are in the [integrated route study](INTEGRATED_AUDIO_ROUTE_STUDY.md). The four C631–C634 GND returns reach L2 in 3.580/3.656/2.650/2.650 mm; C635/C636 bypasses use 11 vias. | Complete upstream rail feeds and U609 VT/control escapes; check reset levels, leakage, cleaning/guarding and clock coupling. Timer route screens do not establish powered performance or EMI. |
| I²S BCLK/LRCLK/SDATA | Current source→series resistor→DAC paths measure **22.213/22.324/22.879 mm**, with **0.666 mm** spread, against the 25 mm path and ±5 mm matching screens. The three central 0.15 mm traces have 0.45 mm copper-edge gaps and sampled L2 support; J703 has no PCB pads. | Complete remaining branches and controls; check edge-rate timing, branch loading and return behavior. This 2D route audit does not establish timing or return impedance. |
| U202/U302/U303 local supply routes | C213/C214/C215→U202 pins 32/16/6 measure **1.103/2.056/3.057 mm**. U302 VIN→C301 is **0.875 mm**, OUT→C302 **2.131 mm**, and OUT→FB302 **5.025 mm**. U303→DAC 1V3 is connected at **25.393 mm with two vias**; 35 local GND pads reach L2. | Complete upstream source rails and remaining bypass paths; extract supply/return impedance and check loaded behavior. The audit is a 2D copper screen, not rail qualification. |
| DAC → U403/U404 I/V | The explicit A/B-channel ECO puts DACL/DACR on physical B and DACLB/DACRB on A. DACL/DACLB/DACR/DACRB no-via F.Cu routes measure **4.294/6.030/6.837/4.786 mm**, under the owner-approved **provisional 7 mm** target; DACR has only **0.163 mm** margin. Saved L2 GND lies directly below all four input traces at 0.01 mm route samples and offsets 0, ±0.05, ±0.10 mm. R423–R426/C417–C420 feedback copper has a maximum **4.875 mm² projected 2D centreline** area; central VREF copper reaches **14.422 mm**. | Extract summing-node capacitance, actual return impedance, 3D feedback/return loop area and VREF noise, then test I/V stability. DACL's U403→C417 feedback branch still lacks direct L2 beneath **1.9426 mm** of centreline, **0.0597 mm** more than the like-for-like prior baseline. The plan-view area and sampled plane support are not electrical sign-off. Check C423/C426's **0.150–0.194 mm** courtyard gaps with assembly. |
| U403/U404 I/V → input T → U401/U402 | Four I/V outputs now feed all eight first T resistors; the longest feed is **47.752 mm** (`N4_IVR_P`→R409), while right `N4_IVR_N` feeds to R411/R413 are **27.289/41.648 mm**. All eight T triplets have F.Cu signal copper and L2 capacitor returns; local branch maxima are 6.53/7.25/8.29 mm (Rin→Rout/capacitor→Rout/Rout→amplifier). | Extract the long right-side cross-layer feed capacitance, coupling and return path, then test stability and loaded audio behavior. R444/C433 were rotated to avoid crossings. Inspect C437/J701/K602 clearance and via mask in JLC DFM. Geometric connectivity alone does not establish a stable DAC-to-amplifier path. |
| U501 switching and regulator macro | Switching capacitors, local VIN, VPOS/VNEG caps, feedback dividers and local GND-to-L2 links have copper. Three **0.20 mm** WSON VIN escapes measure 1.050/0.860/1.146 mm; other `5V_ANA_F` track is ≥0.8 mm. The B.Cu feeder detours around F.Cu `N5_FBP`, removing projected track overlap (**0.1663→0 mm²**) and unshielded pad-inclusive projection (**0.0861→0 mm²**); VIN3→C507 is **6.014 mm** within its 6.1 mm bound. C510/C511 GND vias are **8.160/6.767 mm** from the U501 GND via across L2 by straight spacing. | Extract switching supply/return loops, especially the cap-to-IC L2 paths, and check noise/thermal behavior. The original power-via antipad remains; via spacing is not an extracted return length. Complete upstream supply and downstream main VPOS/VNEG feeds before powered sign-off. |
| U401/U402 → K601–K604 output legs | The integrated study keeps the original A/B pins, hand-places both amplifiers and their Rf/Cf, and physically connects all four outputs through R417–R420 to relay pad 4. It uses 0.932 mm local VSON escapes, four L4 low-impedance output trunks and L1-only `LEG_*`; all four feedback centreline areas are 4.833 mm². K601/R417 moved 2.4 mm with their copper rerouted; J701/J702 stayed fixed. V+ pin 2, both pin-8 EN inputs and C409/C411 share local VPOS copper. V− pin 4/exposed pad reaches its local 100 nF cap; the cap GND pads return to L2. | Finish main VPOS/VNEG source feeds and U401/U402 exposed-pad thermal routes; the five filled/capped vias belong to U301's DAC exposed pad. Reserve L3/L4 return, extract parasitics and test stability/THD+crosstalk. A local EN tie does not power the amplifier. These are partial-copper connections, not amplifier sign-off. |
| Relay → ESD → J701/J702 audio | The integrated study connects each relay output to its intended J701 pads and LP/RP to J702; paired J701 contacts avoid switch pads and mounting pegs. All six local TVS signal paths measure 3.255–4.03 mm. | Check 1:1 fit and solder access, complete return/power copper and system ESD, then measure R-15. With the [review-only 1 mΩ-max output links](OUTPUT_LINK_BOM_ECO.md), conditional 4.4 mm worst-pad estimates are 0.3862/0.3737 Ω (L/R) at 1 kHz and 0.3990/0.3864 Ω in the 20 kHz model sensitivity. The 3.5 mm signal-only lower bounds are 0.2255/0.2188 Ω; the sleeve return is unextracted. Jack-contact maxima, return paths and loaded measurements remain open. |
| Jack GND and ESD return | The integrated board's jack sleeve pads and both amplifier GND pins physically reach one continuous L2 GND polygon. | Design the L3/L4 reference and all HF bypass/ESD discharge returns; extract shared impedance, then measure loaded crosstalk and perform system IEC ESD. A single filled L2 polygon does not prove the return-current path. |
| USB D+/D− at J101 | Fine-pitch escape has no credible rectangular-grid probe result. | Route the intended 90 Ω differential pair with nominal 0.235 mm width, permitted short 0.15 mm neck-downs and zero vias; check JLC stackup and field-solver impedance. Keep CC/VBUS/protection clear and inspect J101 shield return. |

The manual primary removed the historical 15 sensitive-to-clock *pad* gap findings, but routed copper must still satisfy the 5/10 mm high-impedance separation rules. The integrated board's custom DRC also applies **2 mm F.Cu left/right clearance before the 0 Ω links**: `N4_*_OUT` tracks are checked against the opposite channel's pre-link and `LEG_*`/`JACK_*` copper. The existing 2 mm post-link rule remains. The integrated checker rejects exact 90° and free-copper 80–100° bends; pad exits and true T/cross joins are classified separately. J701's fixed contact pitch needs a narrow local exception for tracks crossing its courtyard against J701 pads, at ≥0.20 mm clearance. Inspect that fanout and the L4 output trunks for crosstalk and manufacturability.

## DFA/DFM and physical checks

- Overlay actual J101/J701/J702, relay, oscillator, U621, ESD and polarized parts on the [30-pattern G-3 sheets](G3_OVERLAY_INDEX.md); verify terminal overlap, pin 1, body/peg/slot fit and the enlarged jack copper. J701/J702 worst calculated slot ring is ≥0.31 mm under JLC's published +0.13 mm slot-size tolerance; slot-to-copper registration and the 0.25 mm nearest J701 pad gap still require JLC DFM.
- Inspect C423/C426's **0.150–0.194 mm** courtyard gaps, the tight C437/J701/K602 input corridor and small-capacitor via mask/tenting in the JLC order DFM. The zero-violation proxy does not prove solder mask or assembly access there.
- Inspect J101 and J702 mating edges and panel rails with JLCPCB. The current proxy flags them as assembly exceptions to the general 2.5 mm body-to-finished-edge screen. J101's 3D shell was aligned to the existing maker PCB-edge datum; solder lands did not move.
- Confirm soldering of J101 S1–S4 and J702 1/2 plated slots. They currently have no F.Paste apertures. Check the proposed bottom-side J702 hand-solder fallback and access before changing fit class. [PCBA process review](PCBA_PROCESS_REVIEW.md) contains the exact JLC question.
- Check owner-fitted relay and film-capacitor iron access, 3D heights and thermal exposure. The C631–C634 body is a review envelope, and X201–X203 use a generic 2520 model; use physical parts and maker drawings at G-3.
- Review the current `INTEGRATED_AUDIO_DFA_AUDIT.json` in CI: zero classified spacing/edge findings and 16 unclassified placed references. Zero proxy findings do not guarantee machine access or final soldering. Confirm BOM/rotation in JLC's order preview after layout.

## Reproduce the read-only checks

Use KiCad 10's Python interpreter with `pcbnew` (`python3` in the GitLab KiCad image; on macOS the bundled interpreter path is shown in [README](README.md)). From the repository root:

```sh
board=hardware/DAC_HPA_120x100_INTEGRATED_AUDIO_STUDY_ONLY.kicad_pcb
python3 hardware/audit_placement.py "$board" --height 100 > /tmp/placement.json
python3 hardware/audit_dfa_dfm.py "$board" > /tmp/dfa_dfm.json
python3 hardware/audit_jlc_fab.py "$board" > /tmp/jlc_fab.json
kicad-cli pcb drc --format json --severity-error --severity-warning -o /tmp/pcb_drc.json "$board"
python3 hardware/audit_local_tvs_paths.py "$board" --output /tmp/local_tvs.json
python3 hardware/audit_audio_output_traces.py "$board" --output /tmp/trace_budget.json
python3 hardware/check_integrated_audio_study.py "$board" /tmp/placement.json /tmp/dfa_dfm.json /tmp/jlc_fab.json /tmp/pcb_drc.json /tmp/local_tvs.json /tmp/trace_budget.json --output /tmp/integrated_summary.json
python3 hardware/audit_3d_models.py "$board" --output /tmp/model_3d.json
```

Use [Review findings template](REVIEW_FINDINGS_TEMPLATE.md) to separate **observed board defects** from **route feasibility concerns** and **physical/JLC answers still needed**. A passing script is evidence for its stated screen only. Routing release remains on hold until G-3/G-4 and the listed geometric and audio/EMI checks are closed.

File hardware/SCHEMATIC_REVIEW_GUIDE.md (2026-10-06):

# Schematic peer-review guide

Review the committed [root schematic](DAC_HPA.kicad_sch) and eight linked sheets in KiCad 10, or start with the [nine-page PDF](DAC_HPA_review_only.pdf). The root is PDF page 1; circuit sheets 1–8 are PDF pages 2–9. Record the Git SHA and sheet/page in every finding.

## Source and automated-check boundary

The v0.9 workbook supplies 1,445 baseline pin rows across 247 workbook nets including NC. The [asserted ECO](FUNCTIONAL_ECO_2026-09-28.md) produces a capture with 1,465 pins, 1,422 connected pins, 43 no-connect pins and 250 named nets. `verify_schematic.py` compares the exact 34 pin/net deltas, MPN/fit fields and footprint pads with that baseline; `verify_design_notes.py` checks 1,002 selected rules, and ERC reports zero violations. These are **consistency checks**. Inspect datasheet pin function, power limits, startup/fault behavior, analog stability and physical pad mapping independently.

[Source reconciliation](SOURCE_RECONCILIATION.md) and the [functional ECO](FUNCTIONAL_ECO_2026-09-28.md) list controlled deviations from the versioned Office set. A reviewer should test the reason for each exception. Do not silently replace the approved OPA2210 VSSOP or its explicit A/B channel assignment, corrected LED polarity, connector maps, U621 readback buffer or D707/D708 with an older source value. `generate_schematic.py` rewrites generated schematic files; use a clean checkout if testing regeneration.

## Sheet-by-sheet path

| Circuit sheet / PDF page | Review first | Specific questions and evidence |
| --- | --- | --- |
| [1 USB-C input / OVP / sensing](01_usb_input.kicad_sch), page 2 | J101, D102, U101–U103, VBUS, CC1/CC2, USB D+/D− and shield. | Check GCT's composite 12-land contact map versus JLC's split 16-pad CAD, ESD/OVP orientation and ratings, USB line protection/loading, and shell-to-ground strategy. D102 is owner-fitted before first USB connection. J101 stakes S1–S4 are plated slots without paste apertures pending JLC process confirmation. |
| [2 USB bridge / CPLD / clocks](02_usb_bridge.kicad_sch), page 3 | U201/U202, X201–X203, clock selection and capture taps. | Confirm pin functions, reset/boot states, U202 exposed-pad GND, source switching and U201 PC15/pin 4 to `N6_ORTEST`. The published U201 I²S clock limit is 8 MHz, so the existing I²S2 firmware plan fails above 96 kHz. The [DAC/core route checkpoint](DAC_CORE_ROUTE_STUDY.md) measures BCLK/LRCLK/SDATA at 22.213/22.324/22.879 mm and MCLK at 8.381 mm, with U202 bypass paths of 1.103/2.056/3.057 mm and two filled/capped EP vias; these path measurements do not prove timing or capture function. Review the [SPI2/DMA proposal](MCU_SPI2_CAPTURE_ECO.md), including its still-open physical WS fault coverage and absent firmware/RTL. |
| [3 ES9018K2M DAC](03_dac.kicad_sch), page 4 | U301 rails, I²S/MCLK, analog outputs, VREF and ground pins. | Compare every high-consequence pin to the manufacturer pinout and intended power domain. Check required decoupling, analog/digital return topology and DAC-output polarity before I/V conversion. The current PCB marks five vias in U301's exposed pad filled and capped; the U303→DAC 1V3 route is connected at 25.393 mm with two vias. Confirm the via-in-pad order process and maintain a continuous L2 return. |
| [4 I/V converters / output legs](04_iv_output_legs.kicad_sch), page 5 | U403/U404 I/V, U401/U402 OPA1622 outputs, Rf/Cf, VREF, differential legs and relay paths. | Verify the OPA2210IDGKR (DGK VSSOP-8) map and the explicit A/B channel swap: positive legs use physical B, negative legs A. For OPA1622, pin 8 is **EN** on VPOS and its exposed pad belongs to V−. The [integrated board study](INTEGRATED_AUDIO_ROUTE_STUDY.md) routes all four DAC-to-I/V inputs in 4.294–6.837 mm without vias, eight I/V-to-first-T feeds and eight local T triplets through U401/U402. DACR's 6.837 mm route leaves just 0.163 mm under the provisional 7 mm limit. Saved filled L2 is directly below all four inputs at 0.01 mm route samples and offsets 0, ±0.05, ±0.10 mm; DACL's U403→C417 feedback branch still has a 1.9426 mm direct-L2 gap. The board also draws I/V feedback, VREF and local bypass copper, and ties both OPA1622 EN pins to local VPOS. The largest I/V feedback projected 2D area is 4.875 mm²; extracted three-dimensional loop area, stability, VREF coupling and return impedance remain open. Main VPOS/VNEG source feeds and U401/U402 output-amplifier exposed-pad thermal paths are incomplete; the two U202 and five U301 filled/capped vias are not output-amplifier EP routing. Check gain, stability, DC offset, loaded crosstalk and relay off-state. The F.Cu pre-link outputs face a 2 mm left/right clearance rule. |
| [5 power domains / rails](05_power.kicad_sch), page 6 | Source conversion, regulators, rail sequencing and decoupling. | Check voltage/current ratings, inrush and fault current, enable order, negative-rail behavior and noise coupling. The fitted 3V3M capacitance is now 6.5 µF with C667; [43.695 µC](ATTACH_CHARGE_RECONCILIATION.json) is a planning bound pending capacitance/attach measurement, not the older package's 6.05 µF premise. |
| [6 protection / output switch](06_protection.kicad_sch), page 7 | U605/U621 readbacks, over-range, persistence, timer reset, permit and self-test. | Trace the new R688/R689→U621→R952/R953→MCU path and R954/R955 fail-high pulls while keeping Q619/Q620 interlocks independent. Check both readback logic margins, comparator output loading, power states and U621's exact C507231 pad map. Also review the v1.1 detector and latch paths, especially Q622 in series after Q617. |
| [7 outputs / indicators](07_outputs.kicad_sch), page 8 | J701/J702/J703, D701–D708, relay-to-jack nets and sleeve returns. | J702 pins 5/6 are no-connect break contacts. J701 pads 9/10 are a detect switch; 11/12 are mounting tabs. D705/D706 physical pad 1 is anode. D707/D708 now protect J702 LP/RP locally; review added nonlinear capacitance/leakage and ESD return. Confirm TRS-only 3.5 mm operation, balanced polarity and that J703 has no PCB pads. |
| [8 test pads / PCB items](08_test_pads.kicad_sch), page 9 | Probe access and mounting items. | Confirm every critical rail/fault/clock probe has a safe test purpose and that no test point forces a timing net through an impossible route. |

## Cross-sheet checks to return explicitly

1. **End-to-end path:** USB attach and bridge enable → stable clocks/I²S → DAC and analog rails → output permit/relay → both jacks. Identify any state where an output can connect before rails and offsets are safe.
2. **Protection:** for over-range, low-level persistence, rail loss, hot-plug, short and self-test, trace both channels from detector to muted output. Challenge single-fault and stuck-high/low assumptions using the Spec and Calculation Package. The [review-only R417–R420 output-link candidate](OUTPUT_LINK_BOM_ECO.md) replaces the v1.1 model's 50 mΩ per link with a 1 mΩ manufacturer maximum. The integrated board's conditional left 4.4 mm model is 0.3862 Ω at 1 kHz and 0.3990 Ω at 20 kHz; the latter assumes the same ≤0.5 Ω limit applies there. The 50 mΩ per jack-contact estimate, 3.5 mm sleeve return and loaded behavior remain unverified. Measure both jacks over the intended band before closing R-15.
3. **Source corrections:** verify C102 2.2 µF, R227 at `N2_X201_OUT`, R665 330 Ω, Q622 in permit, U403/U404 DGK VSSOP and their A/B channel swap, and D705/D706 polarity against [Source reconciliation](SOURCE_RECONCILIATION.md).
4. **Physical mapping:** compare symbol pin numbers to footprint pads for J101/J701/J702, U202 exposed pad, polarized parts, oscillators and owner-fitted relays. Use [G-3 overlays](G3_OVERLAY_INDEX.md) and [G-4 record](G4_POLARITY_CHECKLIST.md). G-1/G-2 are owner-accepted with raw-log waiver; this waiver does not extend to G-3/G-4.
5. **Assembly split:** check the placed/owner-fitted/DNF classification in the three review CSVs. The 463 JLC-placed references and 14 references without LCSC codes are a review snapshot, not an order-ready BOM. Verify the process holds in [PCBA process review](PCBA_PROCESS_REVIEW.md).

For each checked path, report **pass**, **issue**, **needs measurement** or **not reviewed** in the [findings template](REVIEW_FINDINGS_TEMPLATE.md). Include the governing datasheet/table or measured waveform when proposing a change; a clean ERC result alone is not sufficient evidence.

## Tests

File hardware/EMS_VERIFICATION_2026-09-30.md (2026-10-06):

# DAC-HPA EMS verification — layout iteration 1 · 30 September 2026

**Verdict: layout-level EMS screen done for the routed areas; not yet certified.** The board is
USB-powered (no mains transformer) and has a continuous L2 GND plane, stitched GND
pours on L1/L3/L4, protected I/O and low-noise regulation.

- **Hum and USB ripple:** the models put magnetic hum ≥ 40 dB below the output noise
  floor at 1 µT (≥ 20 dB at 10 µT, close to a transformer), and USB ripple > 40 dB below.
- **USB ground loop (line-out into an earthed amplifier):** not modelled; test 5 covers it.
- **Wi-Fi, Bluetooth, DECT and GSM1800:** predicted far below the noise floor.
- **Main residual risk — VHF/UHF (30 MHz–1 GHz) on the headphone cable:**
  - as built, the model shows demodulated buzz above the noise floor at 3 V/m;
  - the no-new-footprint part of the fix is R417–R420 → ferrite bead;
  - the full fix also adds a 220 pF C0G per leg, which is a schematic ECO (Section 5);
  - with the ECO, 380 MHz–6 GHz drops ≥ 37 dB below noise, but 30–300 MHz keeps a
    modelled residual of up to +19 dB that must be measured.

This is a design and layout verification (circuit review, geometry screens and
LTspice/MATLAB review models), not an immunity test. Section 6 lists the tests
that decide it.

Board: [DAC_HPA_120x100_INTEGRATED_AUDIO_STUDY_ONLY.kicad_pcb](DAC_HPA_120x100_INTEGRATED_AUDIO_STUDY_ONLY.kicad_pcb).
Screens: [audit_ems_layout.py](audit_ems_layout.py) → [INTEGRATED_AUDIO_EMS_AUDIT.json](INTEGRATED_AUDIO_EMS_AUDIT.json),
[audit_return_path.py](audit_return_path.py). Simulations: [sim/README.md](sim/README.md).

> **Update 1 October — 6-layer stack.** The study board is now 6 layers:
> L1 sig / L2 GND / L3 PWR / L4 sig / L5 GND / L6 sig. L6 (B.Cu) and L4 now
> reference the solid L5 plane, so B.Cu track lacking a GND reference fell
> from 45 % to 11 % (`INTEGRATED_AUDIO_EMS_AUDIT.json`). Hum-loop heights
> shrink with the thinner dielectrics. The worst audio loop, LEG_LP at
> 108 mm², gives about 0.41 µV at 10 µT / 60 Hz, below the 1.56 µV output
> noise floor. The stack-up is assumed and must be confirmed with JLC; the
> USB pair must be re-dimensioned for 90 Ω on the thinner L1–L2 dielectric.

> **Update 6 October — routing closed, layout iteration 1 complete.** The board
> now has 0 ratsnest links and 0 DRC errors or warnings, with all 544
> footprints placed. The audit was re-run on the final copper
> (`INTEGRATED_AUDIO_EMS_AUDIT.json`).
>
> | Screen | 1 Oct | 6 Oct | Note |
> | --- | ---: | ---: | --- |
> | GND vias + PTH | 644 | 723 | MCU/CPLD and comparator areas stitched now that routing is closed (block 15) |
> | Worst pour point to a GND via (F.Cu / L3 / L4 / B.Cu) | 9.05 mm | 6.76 / 6.76 / 6.76 / 5.95 mm | Under λ/20 up to ≈ 2.2 GHz; the 5 mm grid was placed wherever via sites exist |
> | Largest board-edge fence gap | 47.5 mm | 13.7 mm | The 13.7 / 12.8 / 11.1 mm gaps are where edge passives (C651/C652/R946/R947 top, C509/R501/R502 bottom) sit on the fence line, plus a right-edge stretch near the jacks; all are < λ/20 at 1 GHz (15 mm) |
> | Worst audio hum loop | LEG_LP 108 mm² | LEG_LP 120 mm² | 0.45 µV at 10 µT / 60 Hz (−10.7 dB re the 1.56 µV floor); 45 nV at 1 µT (−30.7 dB) |
> | L2 plane fill | 89.5 % | 89.3 % | Still one continuous outline |
> | Left–right headphone copper | 0.392 mm | 0.392 mm | LEG_LP/LEG_RP on L3 at the J701 contacts (DRU jack-pitch exception); ≥ 2 mm elsewhere. Both are low-impedance amplifier outputs, so coupling is negligible at audio frequencies |
>
> - **Hum loops.** The LEG_LP/LN growth comes from plain-net vias
>   punching L2 antipads beside the legs (7.8 mm of LEG_LP lacks L2
>   directly beneath). This still leaves > 10 dB margin at a transformer-close
>   10 µT field.
> - **Digital routes.** The routes added since 1 October are slow control
>   lines: the CPLD/MCU link bus, CPLD_IRQ (ECO F09), the JTAG pins and
>   enables. They stay inside the digital area, and none crosses the DAC
>   core, I/V or output stages (`check_dac_core_routes` passes).
> - **Unchanged.** The residual VHF/UHF finding and its ECO (Section 5) are
>   unchanged. So is the N6_MCK_RC 80 MHz monitor node, 0.49–0.58 mm from
>   N6_CML / N6_V3R_B on facing layers; review it in the next ECO.
>
> **Verdict.** For a home environment (1–3 V/m RF, ≤ 10 µT hum, USB supply), the
> layout screen finds no new coupling path. Hum, ripple, Wi-Fi/BT/cellular and
> ESD stay inside the margins of Sections 2–4. The VHF/UHF cable-borne residual
> still needs the Section 5 ECO and the Section 6 measurements before
> immunity can be claimed.

## 1. Home threat model

| Threat | Level assumed | Coupling path on this board |
| --- | --- | --- |
| Wi-Fi 2.4/5 GHz, Bluetooth, DECT 1.9 GHz | 1–3 V/m at 1 m from a router/phone | Headphone and USB cables (antennas); board traces are short vs λ |
| Cellular 0.7–2.7 GHz incl. 217 Hz TDMA/TDD bursts | 3 V/m (IEC 61000-4-3 residential), ~10 V/m for a phone ≈1 m away | Cable common mode → output stage → demodulation ("GSM buzz") |
| VHF/UHF broadcast, TETRA, 433 MHz ISM remotes | 1–3 V/m | Same; the 1.2 m headphone cable is near-resonant at 60–250 MHz |
| 50/60 Hz magnetic field (chargers, transformers) | 1 µT typical, 10 µT close to a transformer | Loop area of audio nets over their return plane |
| USB host/charger ripple and ground noise | 50 mV p-p at 100/120 Hz (poor charger) | VBUS → regulators → op-amp/reference PSRR |
| Ground loop via USB (line-out use into an earthed amplifier) | mA-level 50/60 Hz loop current | Shared GND between USB receptacle and jack sleeve |
| User ESD at jacks/USB | IEC 61000-4-2 ±4 kV contact / ±8 kV air | TVS diodes to L2 GND |

## 2. Layout screen results ([INTEGRATED_AUDIO_EMS_AUDIT.json](INTEGRATED_AUDIO_EMS_AUDIT.json))

| Item | Result | Assessment |
| --- | --- | --- |
| L2 GND plane | 1 continuous filled outline, 90.6 % of the board area | Solid reference under all L1 routing; no splits |
| Outer and L3 GND pours | GND pours on F.Cu, L3 and B.Cu, 0.3 mm clearance, refilled with the `.kicad_dru` rules (high-Z 0.5 mm, USB 0.6 mm) | Shields L1/L4 traces and gives short return vias |
| GND stitching | 645 GND vias and plated holes; 375 stitching vias on a 4 mm grid plus a 2.5 mm edge fence | Worst pour point to via 9.0 mm and one 47.5 mm edge-fence gap, both in the MCU/CPLD and protection-comparator areas that are **stitched after their routing closes** |
| Return path | 428 mm of 3 407 mm F.Cu track (12.6 %) lacks L2 copper directly beneath; see note | Gaps sit at via antipads and the board-edge pull-back; the DAC inputs, MCLK and I²S keep continuous L2 (gated by `check_iv_macro` / `check_dac_core_routes`) |
| Hum loops (60 Hz) | Largest audio-net loops: LEG_RP 41 mm², LEG_RN 36 mm², LEG_LN 27 mm², I/V rails ≤ 22 mm² | ≤ 15 nV at 1 µT and ≤ 0.15 µV at 10 µT, against a 1.56 µV output noise floor |
| Headphone L/R | Minimum left–right copper gap 2.03 mm | Meets the 2 mm DRU rule |
| Jack sleeve returns | J701.1, J702.1 and J702.2 each have five 0.6/0.2 mm GND vias on 0.5 mm F.Cu straps | J701.1's vias sit 1.9–3.4 mm away, because the DRU forbids vias inside the J701 courtyard |
| VREF | R446/R447/TP709 moved to the divider; the reference no longer crosses the digital area | Removes a 0.45 mm LINK_SCK adjacency and a 30 mm antenna stub |
| Clock / USB separation | MCLK↔DAC inputs ≥ 1.6 mm (≥ 2 mm outside U301, gated); I²S L1-only at 0.15 mm | Residual: an existing DAC-core VREF stub is 1.14 mm from MCLK, and the 80 MHz monitor RC node N6_MCK_RC is 0.58 mm from N6_V3R_B (neither is in a DRU rule). Review in the next ECO. |

Return-path note: B.Cu tracks are referenced to L3. There, the GND pour shares the layer
with the ± rail pair and power spurs, so 45 % of B.Cu length lies over L3 power copper
rather than L3 GND. L2 still sits one core (1.07 mm) away. The L4 audio nets (LEG_*,
I/V feeds) are slow, low-impedance nodes; their loops are counted in the hum row above.

## 3. I/O protection

| Port | Protection | Layout |
| --- | --- | --- |
| USB-C J101 | USBLC6-2SC6 flow-through on D+/D−; TPS25200 eFuse on VBUS; CC ESD; shield via R107 0 Ω (C101 4.7 nF option) | Pair on L1 at 0.235/0.15 mm over continuous L2, no vias |
| J701 / J702 jacks | LESD5D5.0 TVS on each tip/ring (D701–D704, D707, D708), 12 pF | TVS within the 4.2 mm local-path screen (`audit_local_tvs_paths.py`); returns to L2 through the sleeve vias above |

## 4. Circuit-level immunity (schematic review + simulation)

**Supply chain.** VBUS → TPS25200 eFuse → 5V_SYS → TPS259621 → 5V_ANA → FB501
(BLM18PG121SN1D) + 10 µF → LM27762 (2 MHz charge pump + low-noise ±LDOs) →
VPOS/VNEG. 3V3A comes from an LP5907 behind FB302; the DAC 1V3 from a TLV758; the
MCU and CPLD have their own LDOs.

**Filter resonance.** LTspice ([ems_5vana_filter.cir](sim/ems_5vana_filter.cir))
shows the FB501/10 µF resonance, with the MLCCs derated to 40 %:

| | Without R531/C513 | With R531/C513 at FB501.2 |
| --- | ---: | ---: |
| Line-transfer peak | +5.4 dB | +1.8 dB |
| U501 input-impedance peak | 1.25 Ω | 0.74 Ω |

The damper was moved from 20 mm away to the FB501.2 node in this iteration. The
filter keeps the LM27762 2 MHz ripple 52–60 dB down on 5V_ANA.

**Mains-frequency ripple.** MATLAB [ems_budget.m](sim/ems_budget.m) uses datasheet
PSRR curves:

| Datasheet curve | At 100 Hz |
| --- | ---: |
| LM27762 OUT+ | ≈65 dB |
| LM27762 OUT− | ≈52 dB |
| LP5907 | 90 dB |
| OPA1622 (RTI) | 140 dB |

For 50 mV p-p of 100 Hz on VBUS, the results at the headphone output are:

- **via the ± rails:** 0.025 nV;
- **via 3V3A → VREF (common mode, 1 % resistor match):** 7.9 nV.

Both are more than 40 dB below the 1.56 µV output noise, so USB ripple is not a hum
path.

**RF filtering already in the signal path.**

| Stage | Filter |
| --- | --- |
| I/V stage | 698 Ω ∥ 820 pF feedback (278 kHz pole); the DAC current output node is an RF short (820 pF ≈ 0.2 Ω at 900 MHz) |
| Difference stage | 680 Ω + 10 pF input RCs (23 MHz) and 2 kΩ ∥ 10 pF feedback |
| Protection comparators | 1 MΩ/3.3 nF, 910 kΩ/100 nF and 330 kΩ/1 nF RC inputs (48 Hz, 1.7 Hz, 482 Hz poles) |

The OPA2210 EMIRR is ≈36–47 dB up to 1 GHz and ≥70 dB above 1.8 GHz (datasheet
Fig. 6-39).

**Headphone output (the weak point).** The OPA1622 output reaches the jack through a
0 Ω link (R417–R420), the photo-relay and a 12 pF TVS. Its open-loop Z<sub>O</sub>
rises inductively above 1 MHz (5.5 Ω → ≈40 Ω at 100 MHz, datasheet Fig. 40), so
cable RF is barely absorbed by the amplifier. The feedback 10 pF then couples it
into the inverting input.

LTspice ([ems_headphone_rf.cir](sim/ems_headphone_rf.cir)) finds an LC resonance near
350–450 MHz with ≈0 dB coupling. MATLAB turns this into a 217 Hz buzz estimate:
OPA2210 EMIRR used as a proxy (the OPA1622 publishes none), square law,
−20 dB cable CM→DM conversion. Values are relative to the 1.56 µV output noise:

| Band | As built, 3 V/m | As built, 10 V/m | ECO, 3 V/m | ECO, 10 V/m |
| --- | ---: | ---: | ---: | ---: |
| VHF 30-80 MHz | +53 dB | +74 dB | +18 dB | +39 dB |
| FM broadcast | +60 dB | +81 dB | +0 dB | +21 dB |
| VHF 150-300 MHz | +47 dB | +68 dB | +19 dB | +40 dB |
| TETRA/433 ISM/DVB-T | +50 dB | +71 dB | -37 dB | -16 dB |
| LTE800/GSM900 | -9 dB | +12 dB | -104 dB | -83 dB |
| GSM1800/DECT | -124 dB | -103 dB | -215 dB | -194 dB |
| Wi-Fi 2.4 | -134 dB | -113 dB | -224 dB | -203 dB |
| Wi-Fi 5 | -133 dB | -112 dB | -248 dB | -227 dB |

## 5. Recommended ECO (owner decision)

1. **R417–R420: 0 Ω → 0402 ferrite bead**, 120 Ω @ 100 MHz, DCR ≤ 0.1 Ω, ≥ 1 A.
   - Same footprints; no layout change needed for this part.
   - The bead sits outside the OPA1622 feedback loop, adding about 0.05 Ω of output
     resistance (damping factor > 300 into 16 Ω).
2. **Add 220 pF C0G 0402 from each LEG_* net to GND**, beside R417–R420 on the relay
   side.
   - Four new parts, so this needs a schematic ECO and a BOM update.
   - [review_output_rf_filter.py](review_output_rf_filter.py) uses the unchanged
     calibrated OPA1622 model from Calculation Package v1.1
     ([results](OUTPUT_RF_FILTER_STABILITY_REVIEW.json)):
     - worst phase margin 47.1° (49.7° today);
     - worst gain margin 6.46 dB (7.86 dB today).
   - Larger values were rejected:
     - 600 Ω bead + 1 nF: phase margin 7°;
     - 120 Ω + 470 pF: gain margin 5.8 dB.
3. With 1 + 2, the model puts 380 MHz–6 GHz buzz ≥ 37 dB below the noise floor at
   3 V/m.
   - 30–300 MHz improves by 28–60 dB, but a modelled residual of up to +19 dB above noise
     remains at 3 V/m.
   - The model is uncertain there (cable CM→DM conversion, EMIRR proxy), so measure
     before adding more filtering.

## 6. Tests that decide immunity

1. IEC 61000-4-3, 80 MHz–6 GHz at 3 V/m, 1 kHz 80 % AM (EN 55035 residential).
   - Record A-weighted output noise and 1 kHz / 217 Hz spurs with a 32 Ω load and
     1.2 m cable, each jack.
2. IEC 61000-4-6 conducted, 150 kHz–80 MHz at 3 V EMF.
   - Inject on the USB cable and the headphone cable.
3. GSM/LTE phone test: calling phone at 10 cm and 1 m; 217 Hz and 1.73 kHz spurs.
4. Magnetic 50/60 Hz: a 10 µT Helmholtz field, or a laptop charger at 5 cm; output
   spectrum.
5. USB ground loop: line-out into an earthed amplifier through a PC; measure hum,
   with and without the C101/R107 shield option.
6. IEC 61000-4-2 ESD at J701/J702 sleeve/tip and USB shield.
   - Check there is no latch-up and that the relay/protection recovers.
7. Near-field scan of the LM27762 (2 MHz) and the CPLD/MCU clocks.
   - Confirm clock harmonics are not visible in the audio-band noise.

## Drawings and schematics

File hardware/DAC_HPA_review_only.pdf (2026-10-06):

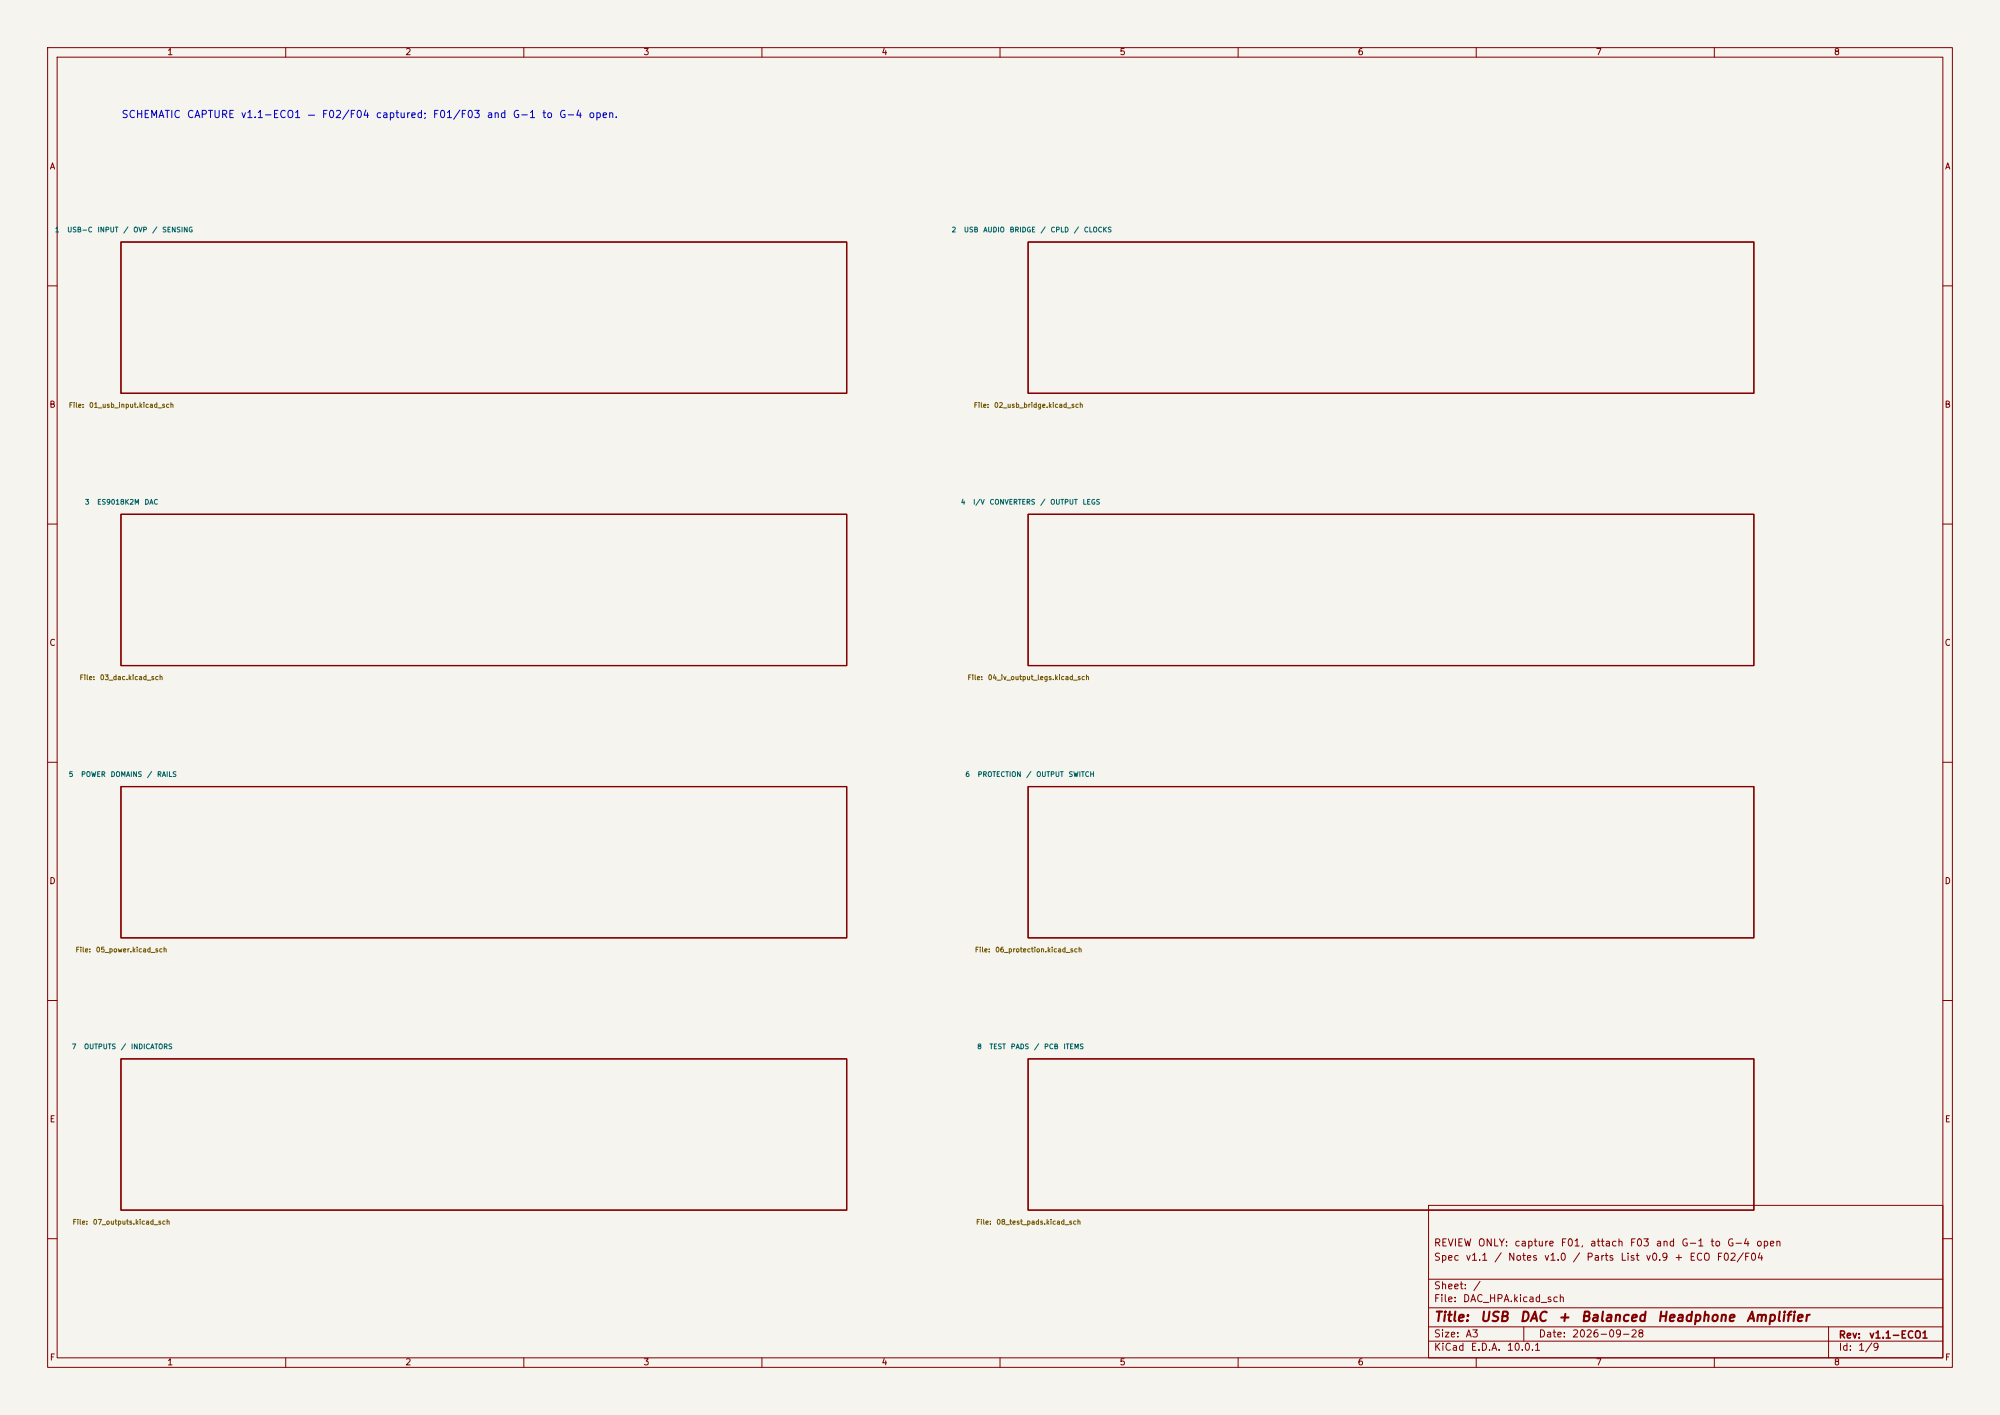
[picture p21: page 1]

SCHEMATIC CAPTURE v1.1-ECO1 — F02/F04 captured; F01/F03 and G-1 to G-4 open.

1 USB-C INPUT / OVP / SENSING

2 USB AUDIO BRIDGE / CPLD / CLOCKS

File: 02_usb_bridge.kicad_sch 4 I/V CONVERTERS / OUTPUT LEGS

File: 03_dac.kicad_sch 5 POWER DOMAINS / RAILS

File: 04_iv_output_legs.kicad_sch 6 PROTECTION / OUTPUT SWITCH

File: 06_protection.kicad_sch 8 TEST PADS / PCB ITEMS

REVIEW ONLY: capture F01, attach F03 and G-1 to G-4 open
Spec v1.1 / Notes v1.0 / Parts List v0.9 + ECO F02/F04

Sheet: /
File: DAC_HPA.kicad_sch
Title: USB DAC + Balanced Headphone Amplifier

Size: A3 | Rev: v1.1-ECO1 | F Date: 2026-09-28
KiCad E.D.A. 10.0.1 | Id: 1/9

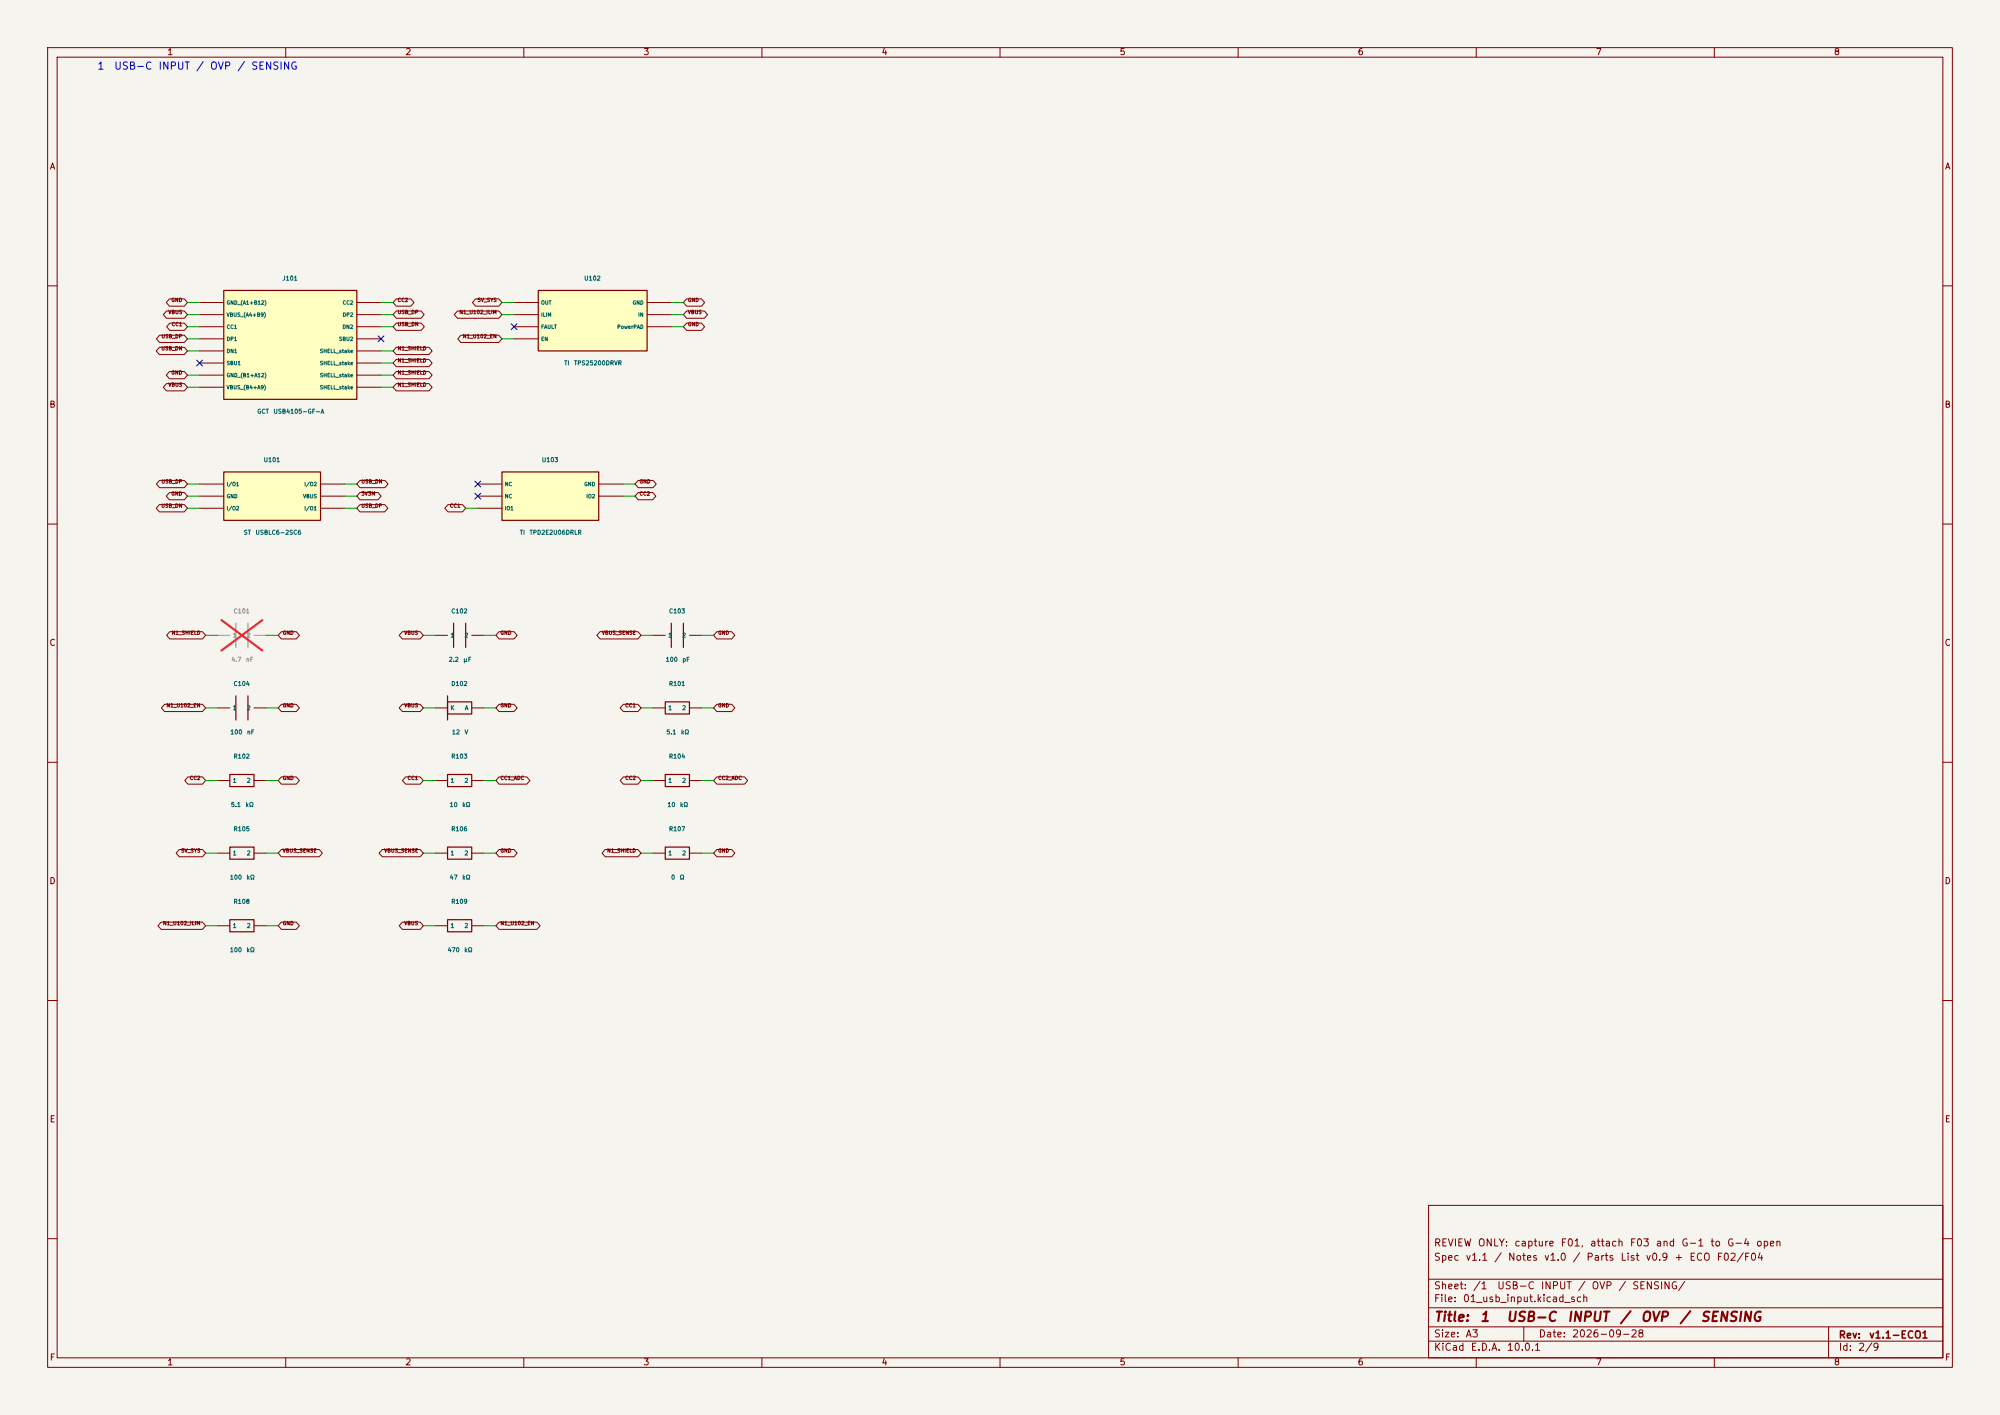
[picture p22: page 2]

GND 1 USB-C INPUT / OVP / SENSING

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

Sheet: /1 USB-C INPUT / OVP / SENSING/
File: 01_usb_input.kicad_sch
Title: 1 USB-C INPUT / OVP / SENSING

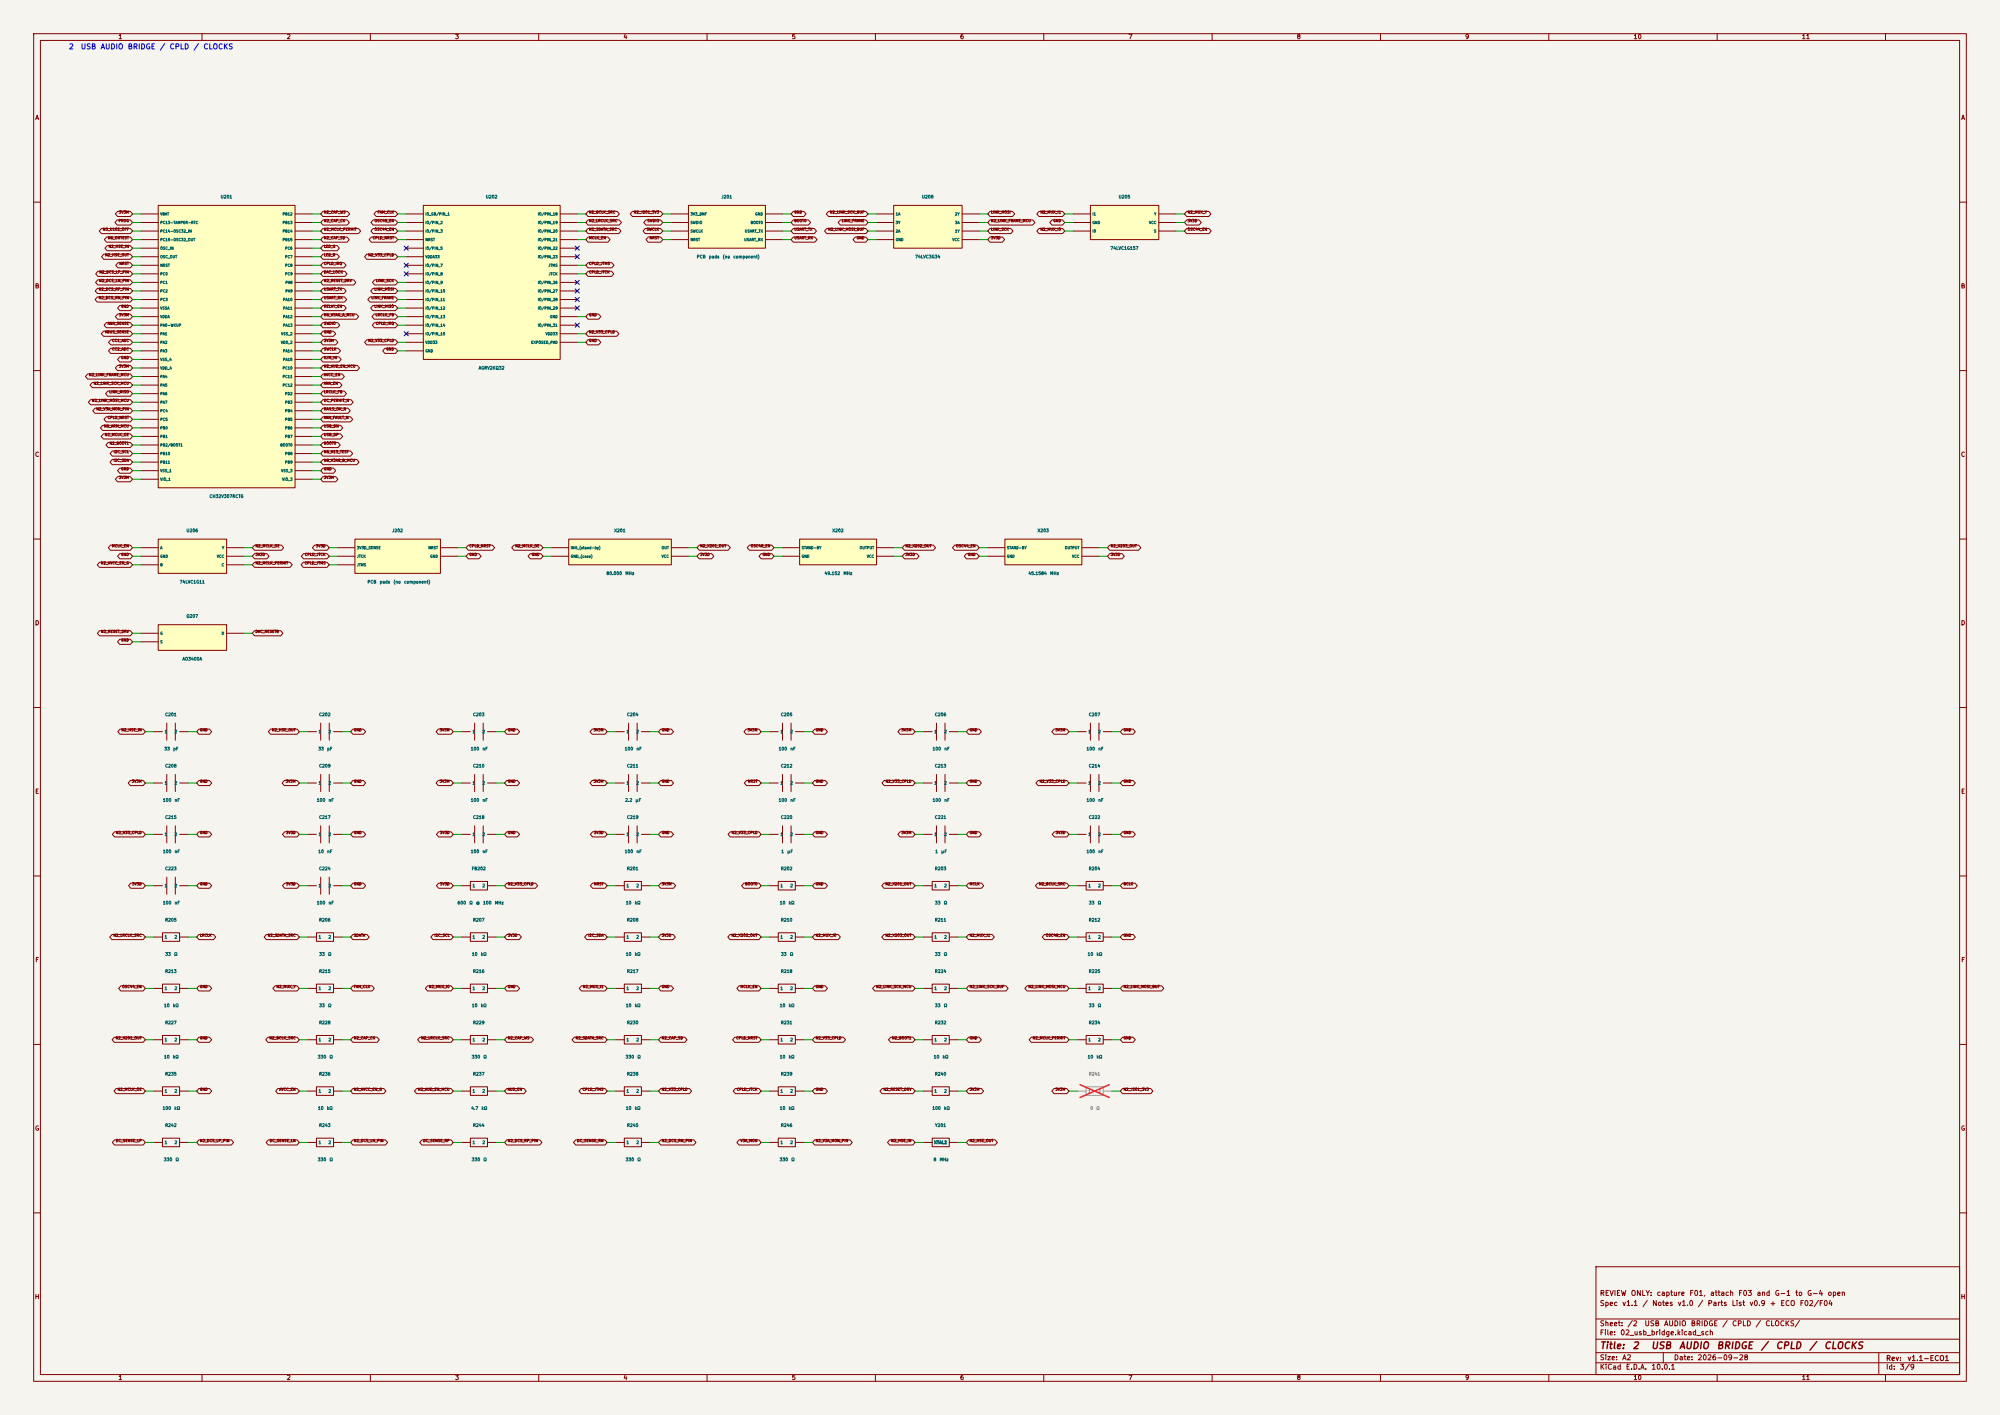
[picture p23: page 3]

2 USB AUDIO BRIDGE / CPLD / CLOCKS

J201 PCB pads (no component)

J202 PCB pads (no component)

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

Sheet: /2 USB AUDIO BRIDGE / CPLD / CLOCKS/
File: 02_usb_bridge.kicad_sch
Title: 2 USB AUDIO BRIDGE / CPLD / CLOCKS

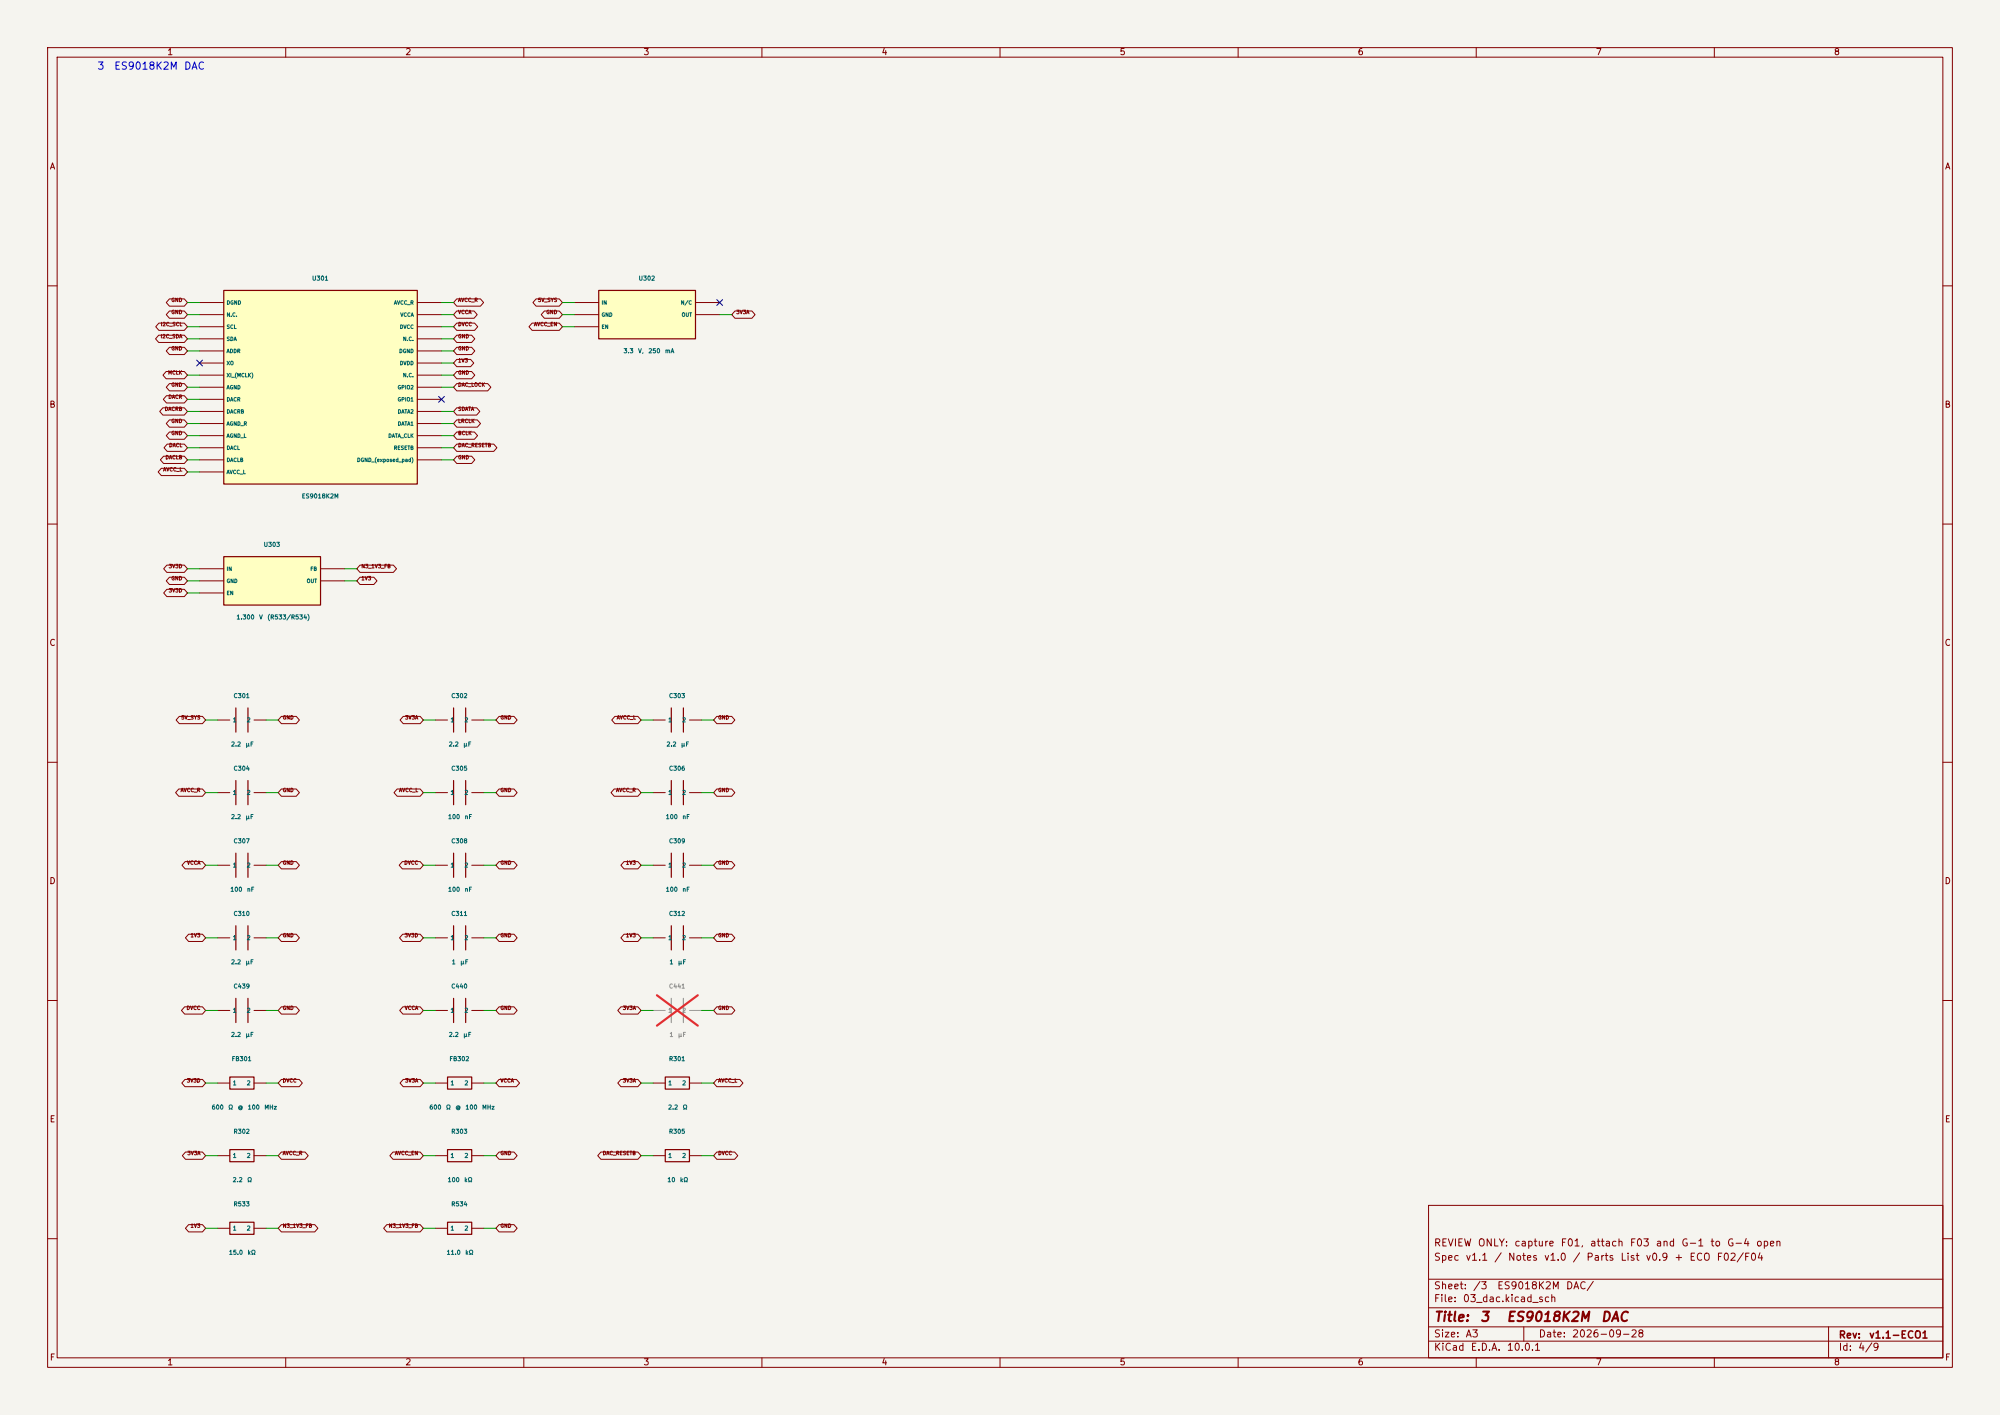
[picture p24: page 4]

3.3 V, 250 mA DGND N.C. SCL SDA

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

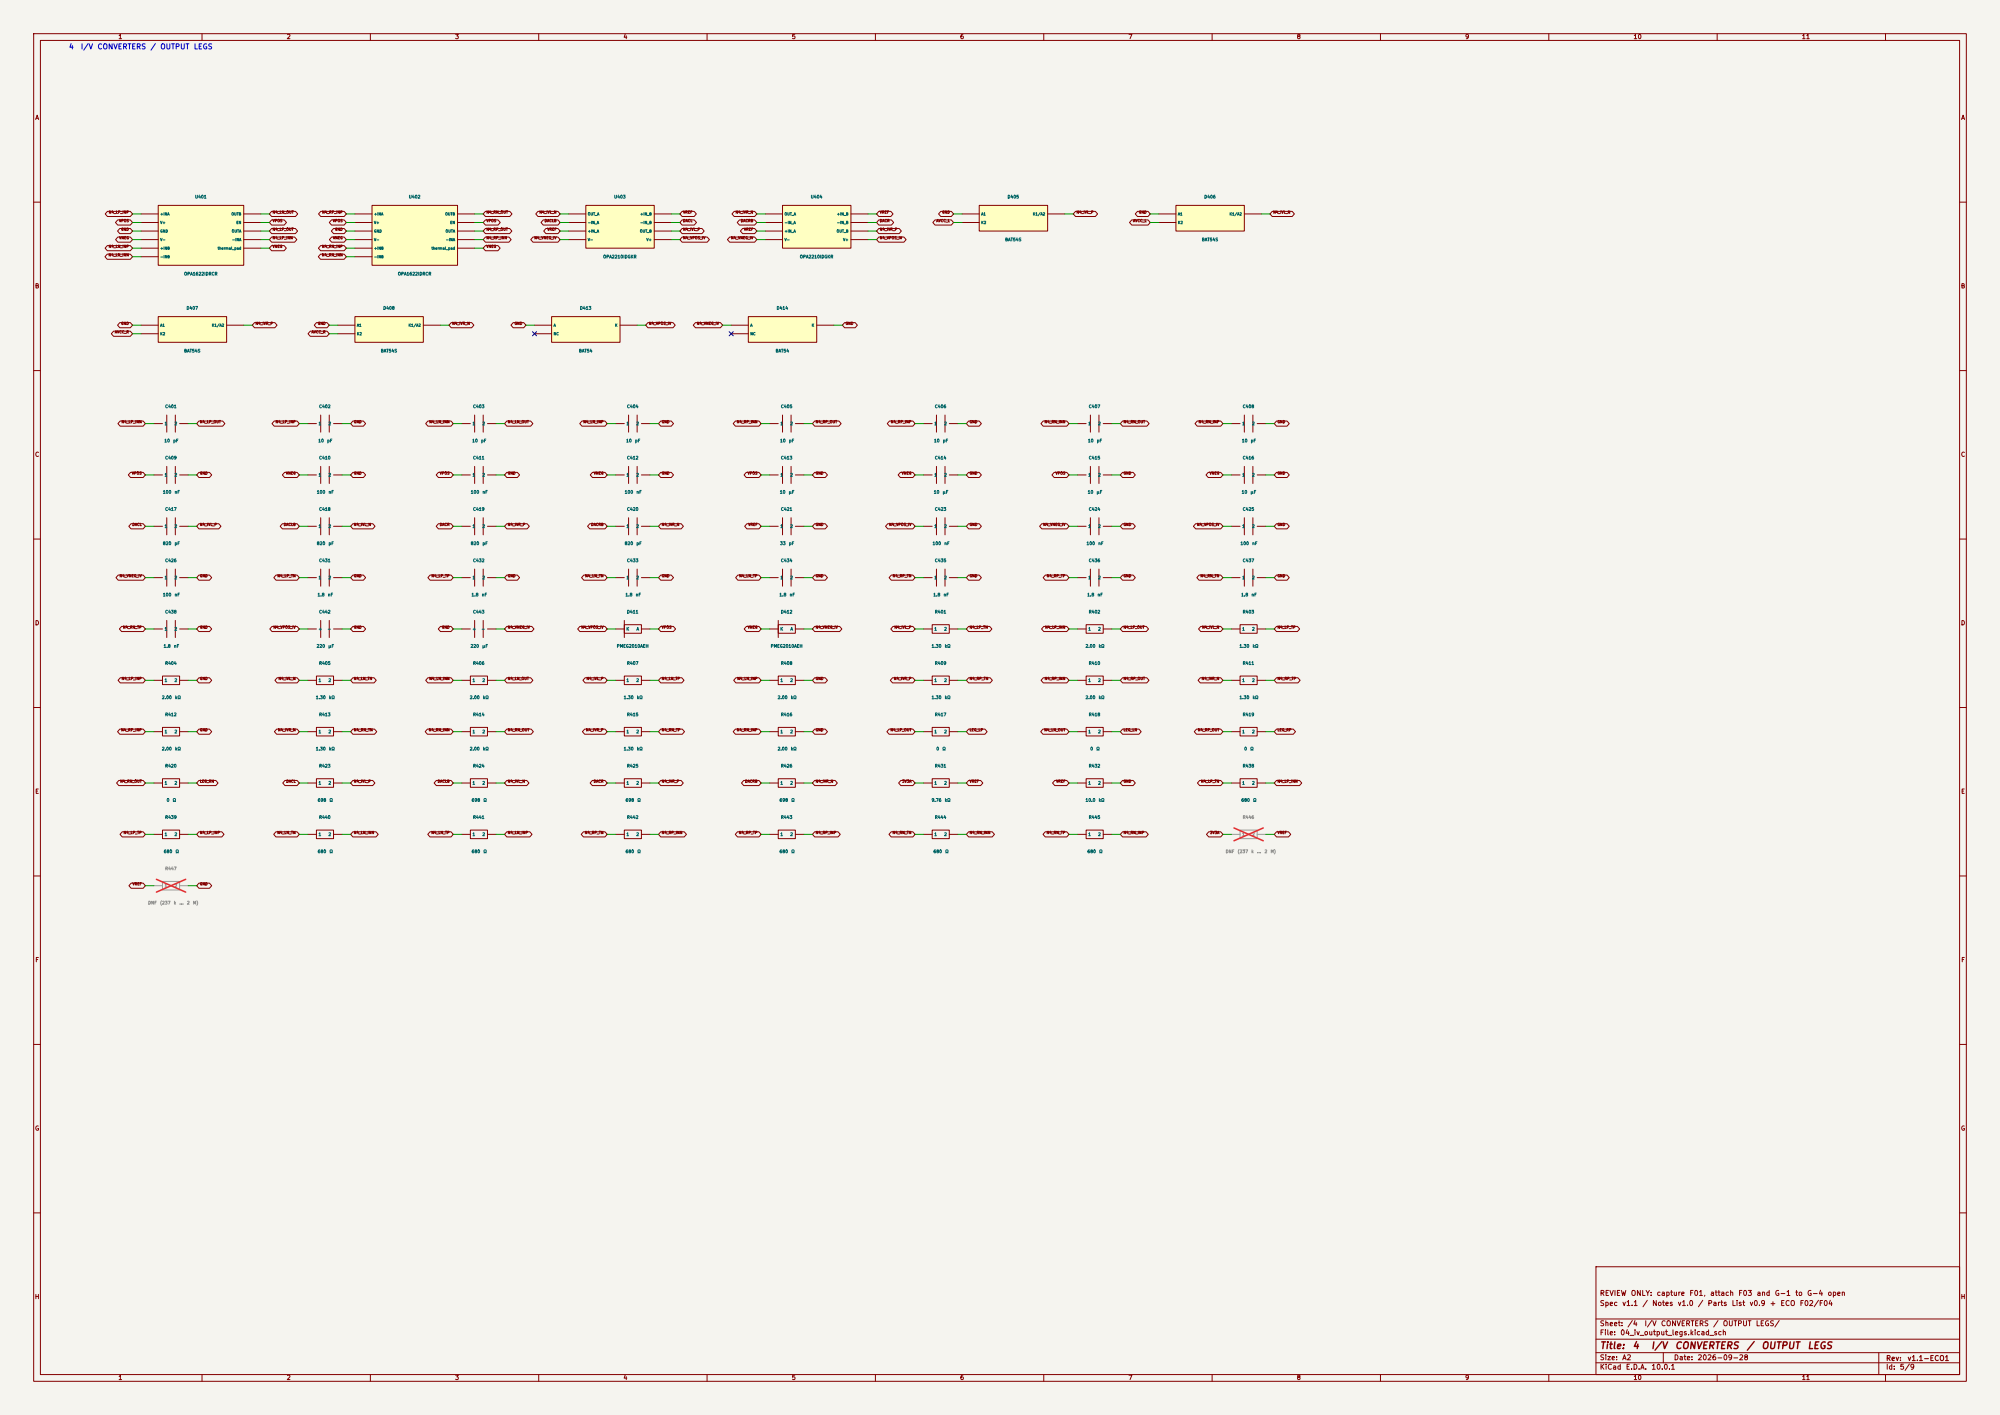
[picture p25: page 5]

Sheet: /4 I/V CONVERTERS / OUTPUT LEGS/
File: 04_iv_output_legs.kicad_sch
Title: 4 I/V CONVERTERS / OUTPUT LEGS

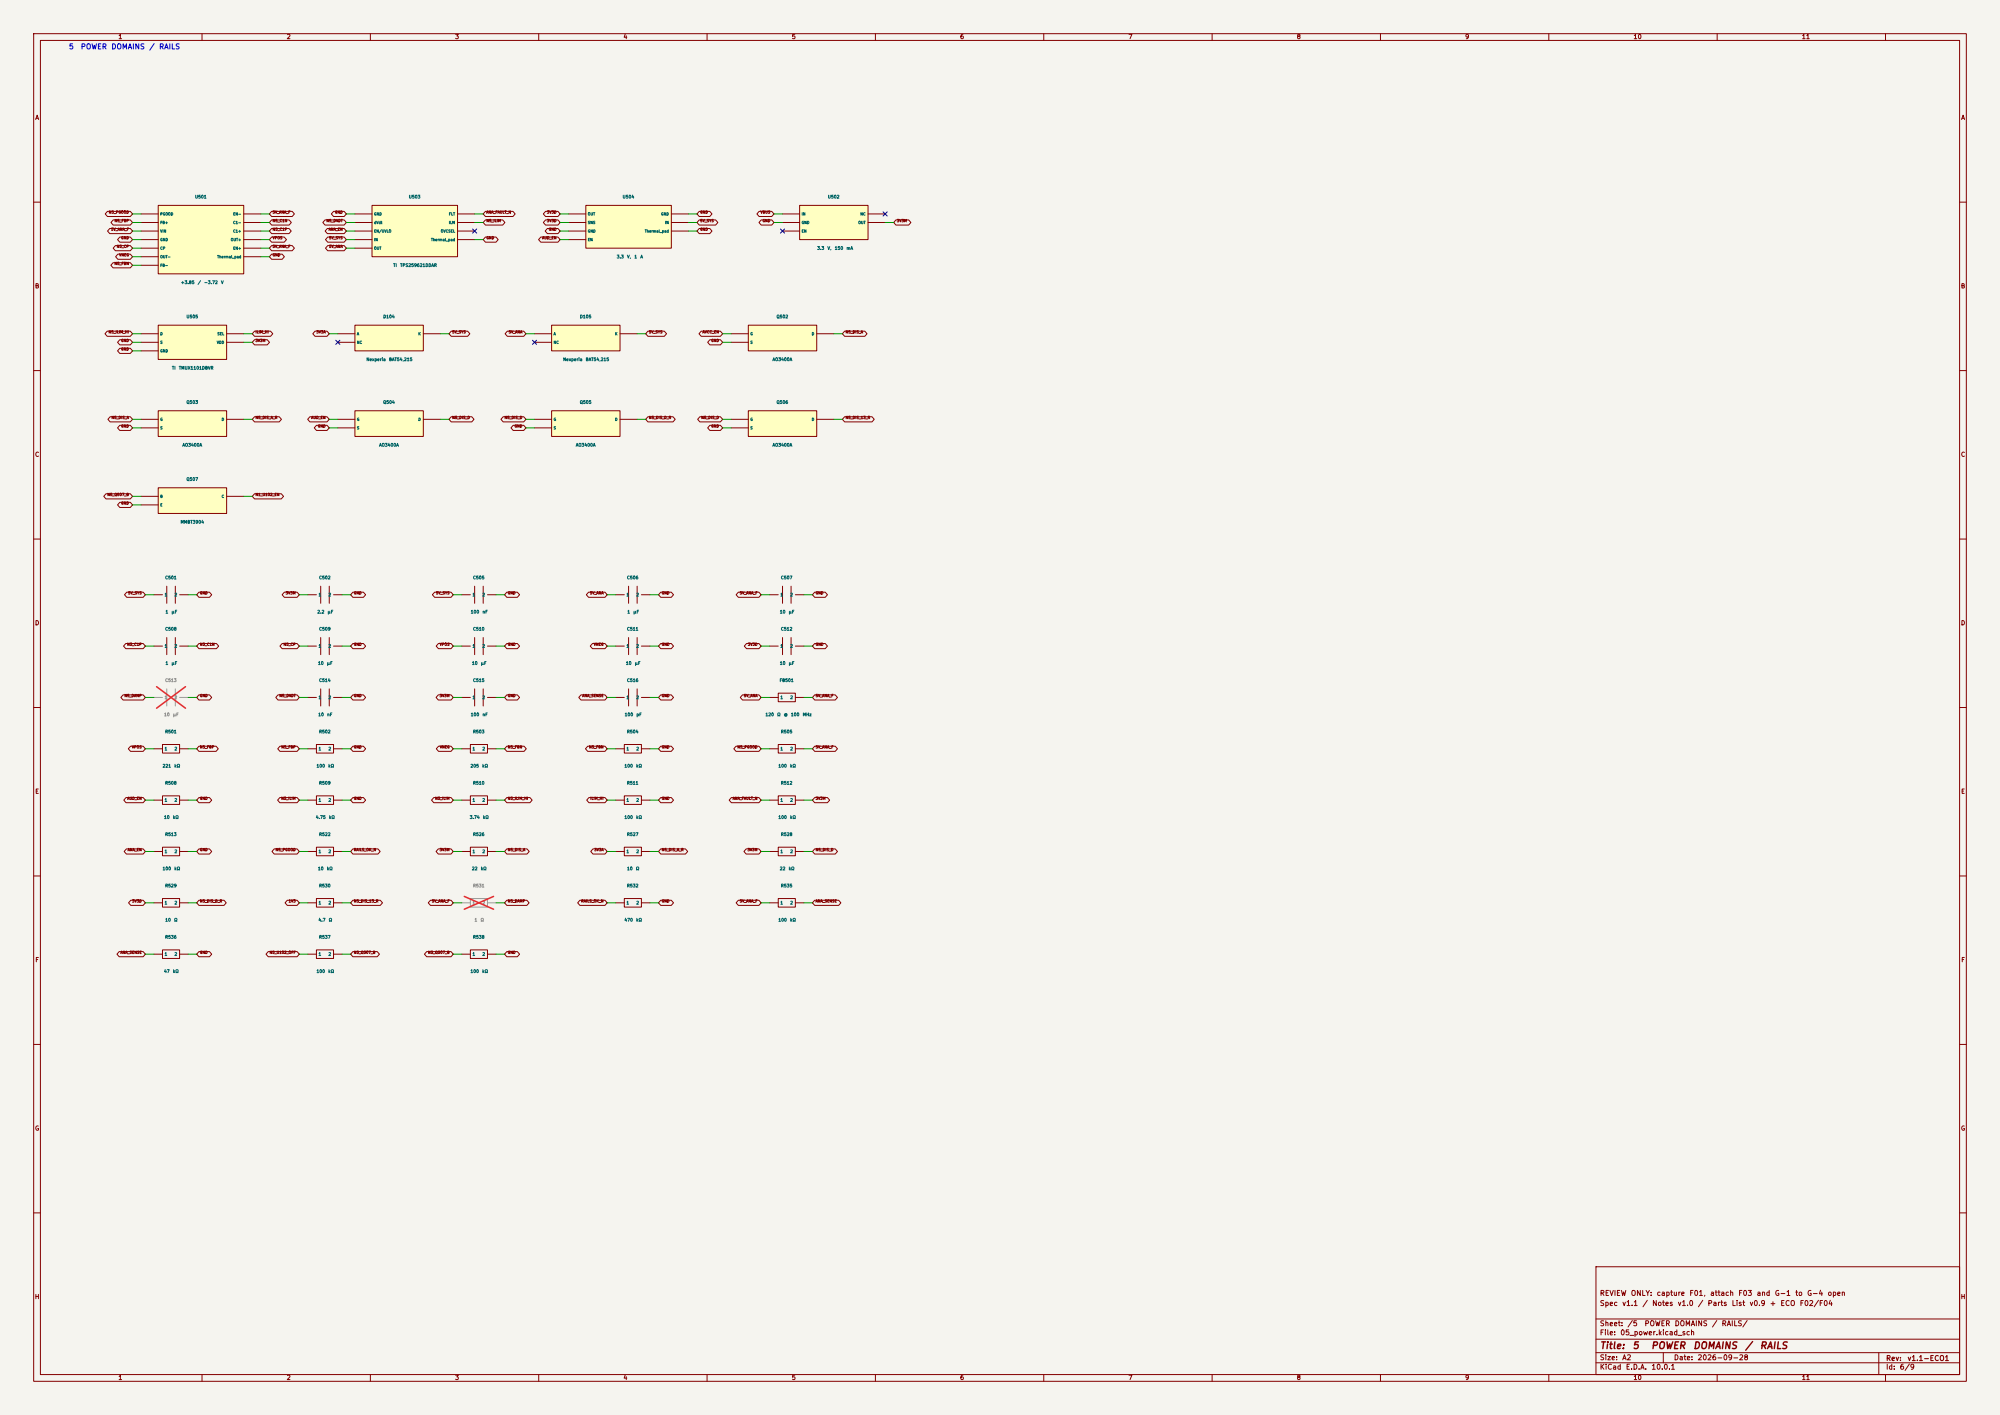
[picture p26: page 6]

GND 5 POWER DOMAINS / RAILS

Sheet: /5 POWER DOMAINS / RAILS/
File: 05_power.kicad_sch
Title: 5 POWER DOMAINS / RAILS

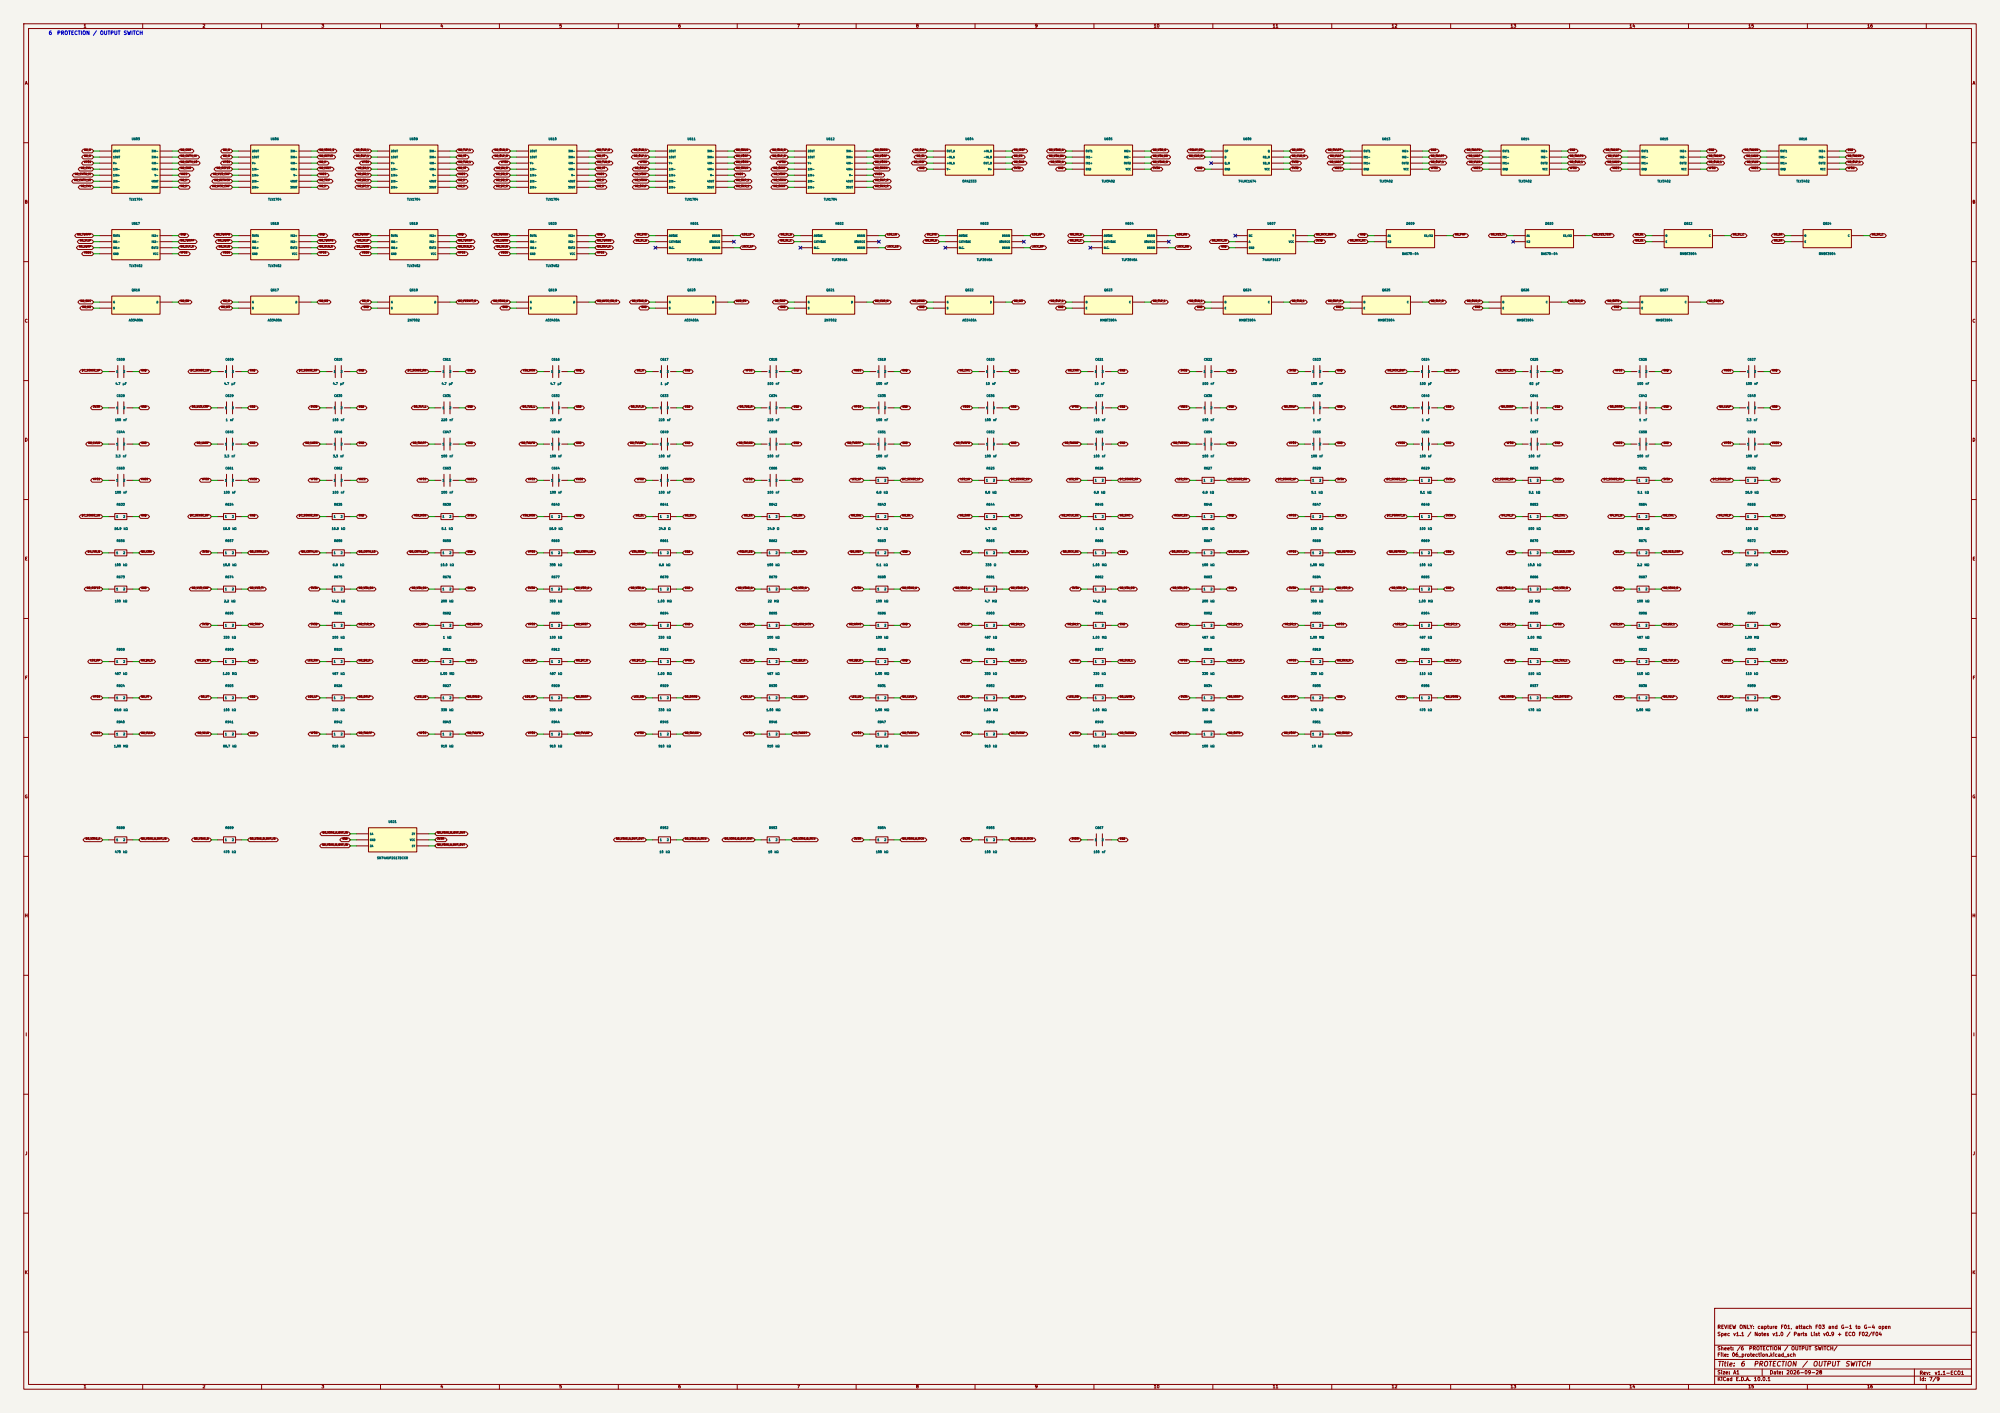
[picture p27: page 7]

Sheet: /6 PROTECTION / OUTPUT SWITCH/
File: 06_protection.kicad_sch
Title: 6 PROTECTION / OUTPUT SWITCH

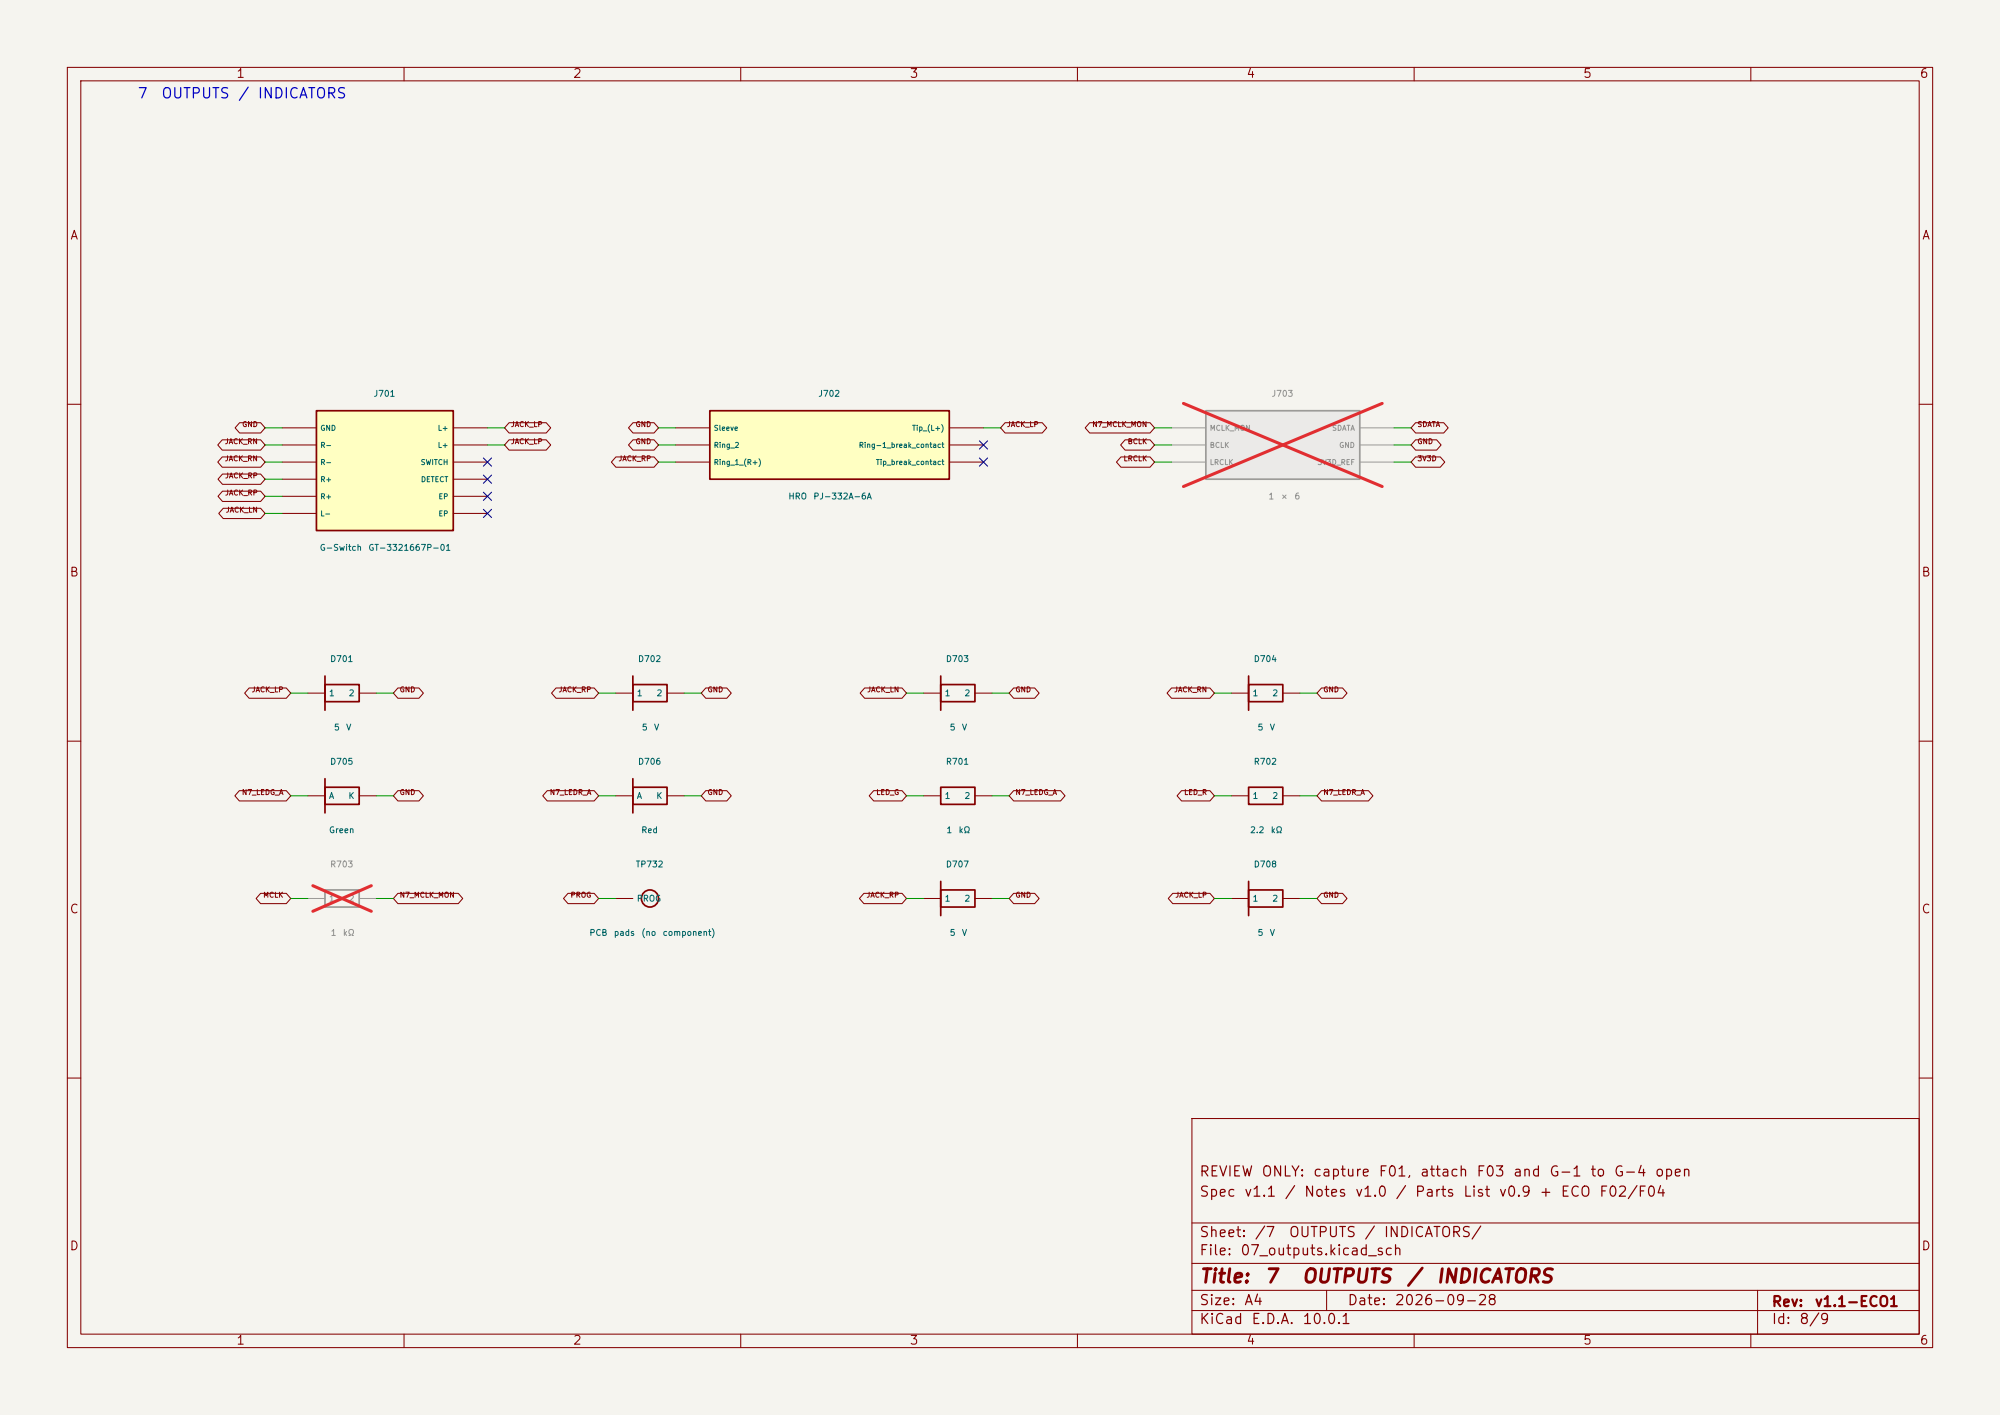
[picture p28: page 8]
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

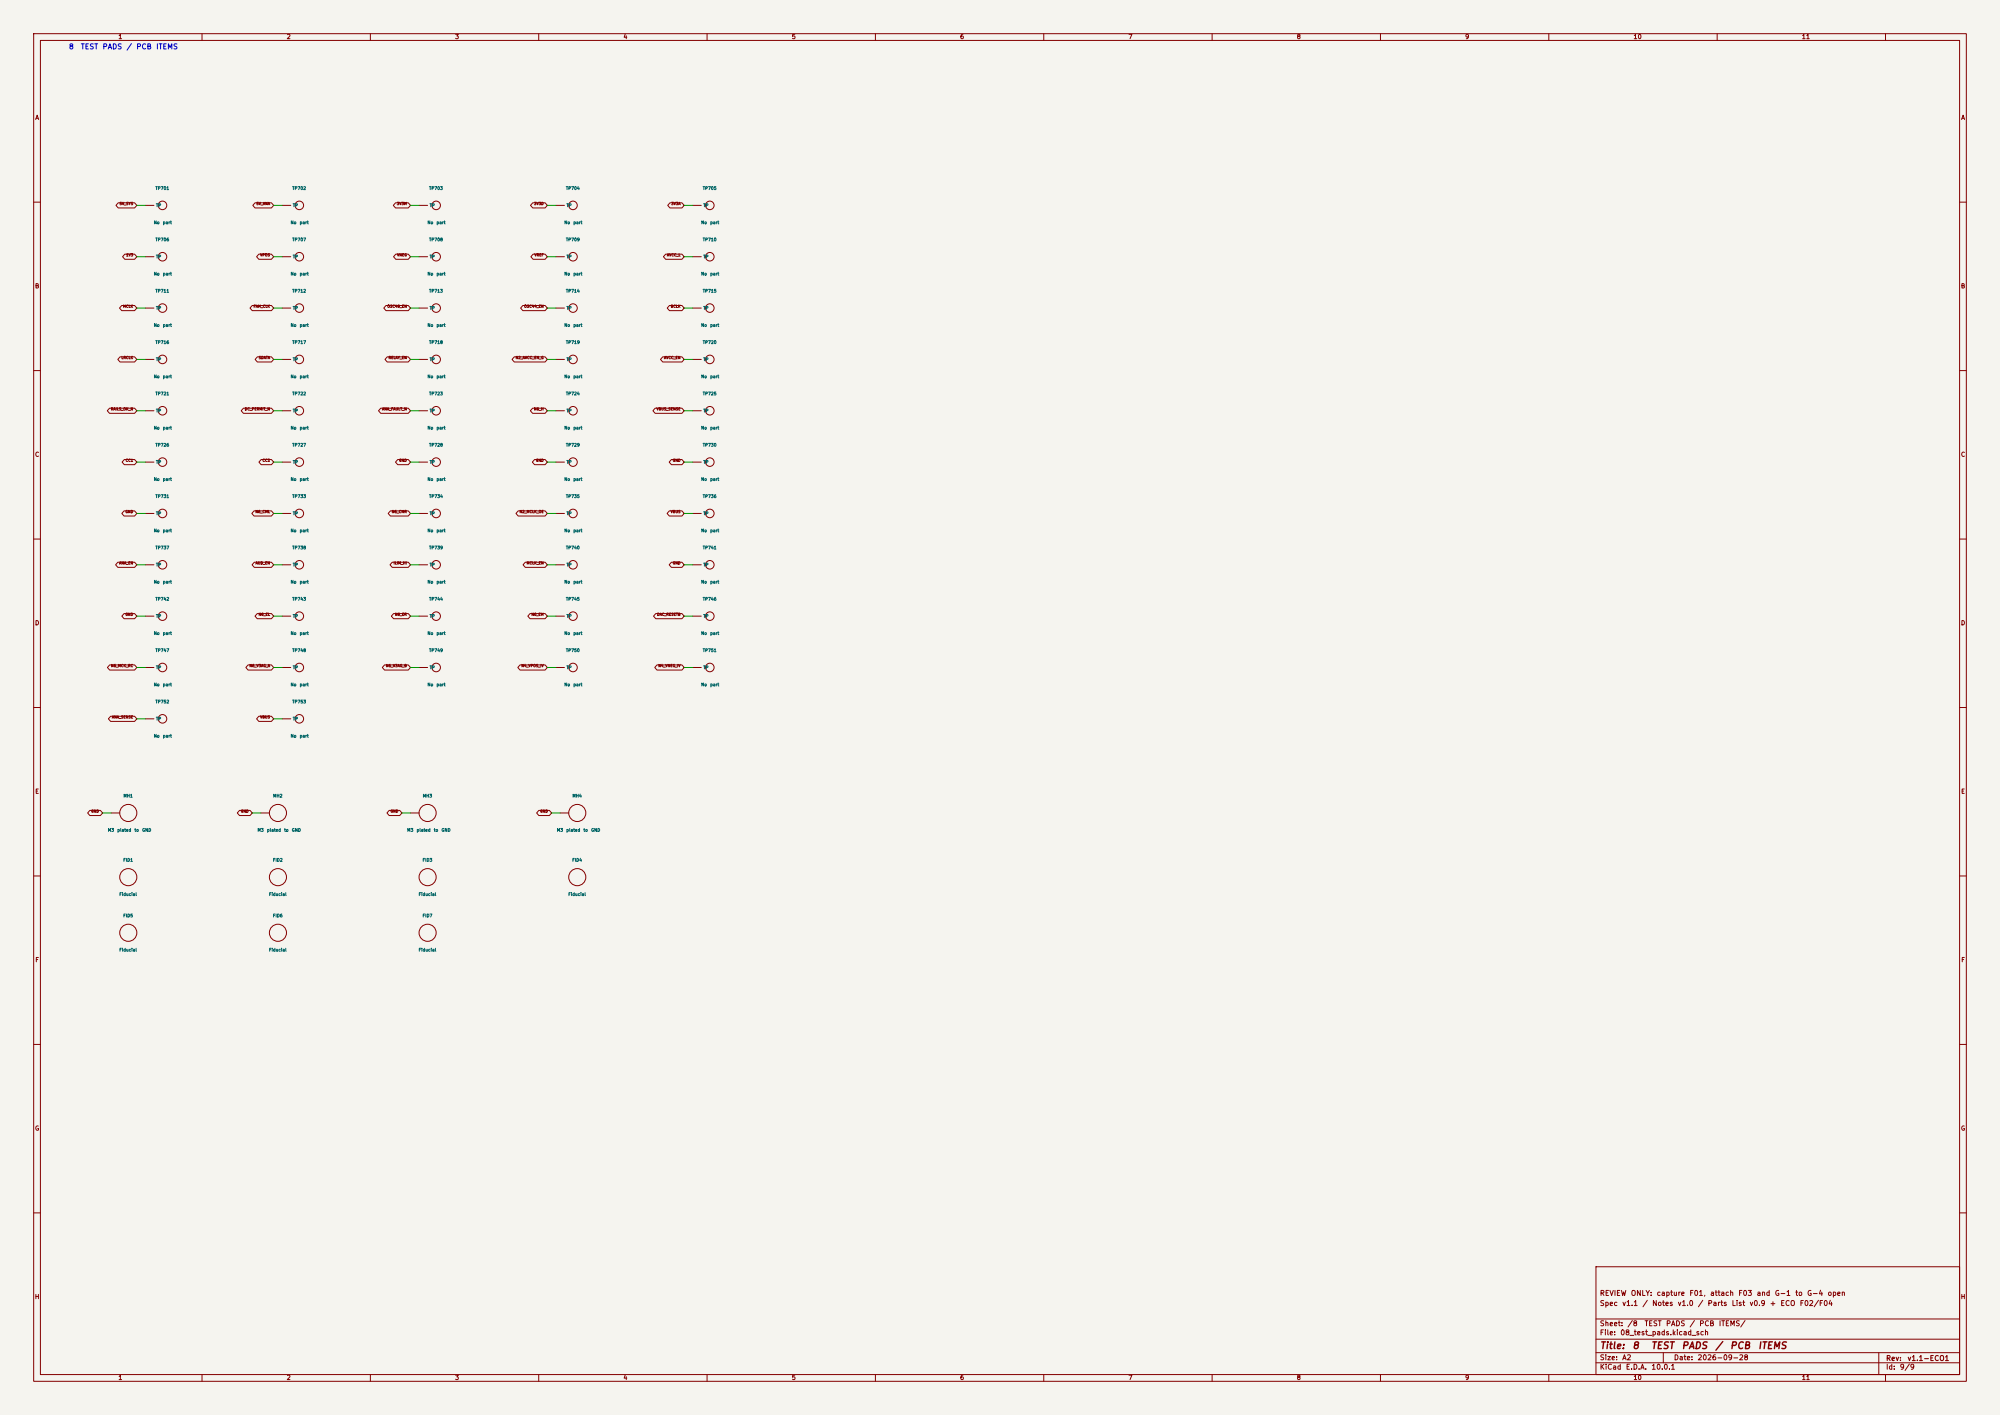
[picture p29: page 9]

8 TEST PADS / PCB ITEMS

TP738 No part MH1 M3 plated to GND

VBUS
Fiducial MH2 M3 plated to GND

Sheet: /8 TEST PADS / PCB ITEMS/
File: 08_test_pads.kicad_sch
Title: 8 TEST PADS / PCB ITEMS

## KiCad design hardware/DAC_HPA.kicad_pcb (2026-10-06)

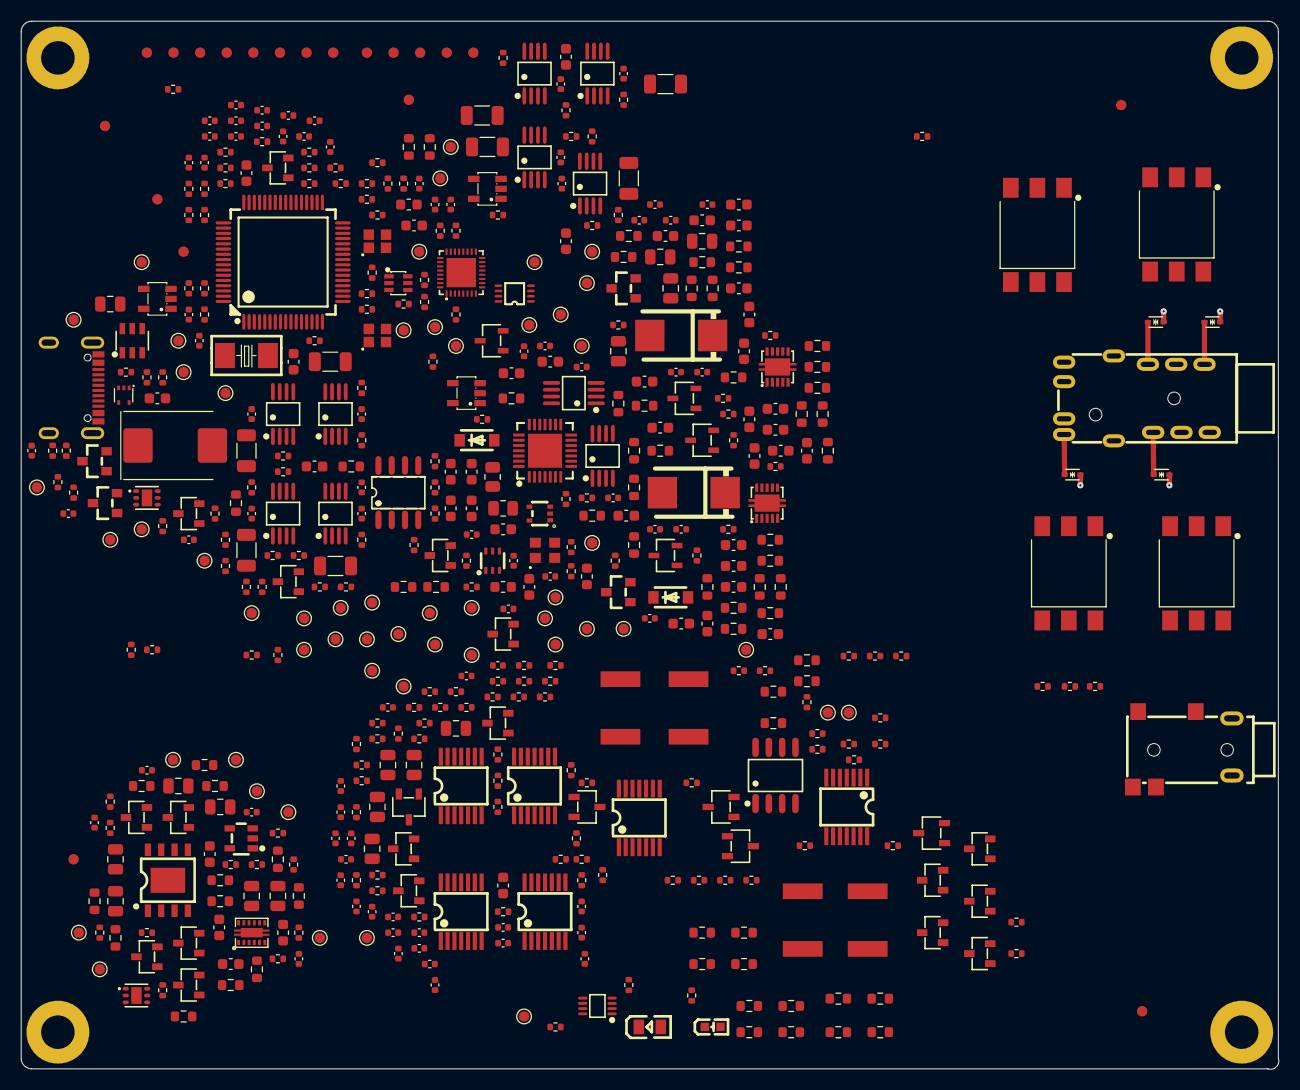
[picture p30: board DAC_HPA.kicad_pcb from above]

Board: 4 copper layers, 120.0 x 100.0 mm, 536 parts (0 on the bottom side), 245 nets.

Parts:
C101: 4.7 nF; C_0402_1005Metric
C102: 2.2 µF; C_0805_2012Metric
C103, C516, C624: 100 pF; C_0402_1005Metric
C104, C203, C204, C205, C206, C207, C208, C209, C210, C212, C213, C214, C215, C218, C219, C222, C223, C224, C305, C306, C307, C308, C309, C409, C410, C411, C412, C423, C424, C425, C426, C505, C515, C618, C619, C622, C623, C626, C627, C628, C630, C635, C636, C637, C638, C655, C656, C657, C658, C659, C660, C661, C662, C663, C664, C665, C666: 100 nF; C_0402_1005Metric
C201, C202, C421: 33 pF; C_0402_1005Metric
C211: 2.2 µF; C_0402_1005Metric
C217, C514, C620, C621: 10 nF; C_0402_1005Metric
C220, C221, C311, C312, C441, C501, C506, C508, C617: 1 µF; C_0603_1608Metric
C301, C302, C303, C304, C310, C439, C440, C502: 2.2 µF; C_0603_1608Metric
C401, C402, C403, C404, C405, C406, C407, C408: 10 pF; C_0603_1608Metric
C413, C414, C415, C416, C507, C509, C510, C511, C512, C513: 10 µF; C_0805_2012Metric
C417, C418, C419, C420: 820 pF; C_0603_1608Metric
C431, C432, C433, C434, C435, C436, C437, C438: 1.8 nF; C_0603_1608Metric
C442, C443: 220 µF; CASE-D_7343
C608, C609, C610, C611, C616: 4.7 µF; C_0805_2012Metric
C625: 82 pF; C_0402_1005Metric
C629, C639, C640, C641, C642: 1 nF; C_0402_1005Metric
C631, C632, C633, C634: 220 nF; C631_ECHU1H224GX9_D4
C643, C644, C645, C646: 3.3 nF; C_0603_1608Metric
C647, C648, C649, C650, C651, C652, C653, C654: 100 nF; C_1206_3216Metric
D102: 12 V; D102_SMDJ12A_HandSolder
D104, D105: Nexperia BAT54,215; SOT-23_L2.9-W1.3-P1.90-LS2.4-BR
D405, D406, D407, D408: BAT54S; SOT-23-3_L3.0-W1.7-P0.95-LS2.9-BR
D411, D412: PMEG2010AEH; SOD-123F_L2.8-W1.8-LS3.7-RD
D413, D414: BAT54; SOT-23_L2.9-W1.3-P1.90-LS2.4-BR
D609, D610: BAS70-04; SOT-23-3_L2.9-W1.3-P1.90-LS2.4-BR
D701, D702, D703, D704: 5 V; SOD-523_L1.2-W0.8-LS1.6-BI
D705: Green; LED0805-R-RD
D706: Red; LED-SMD_L1.6-W0.8-R-RD
FB202, FB301, FB302: 600 Ω @ 100 MHz; L_0603_1608Metric
FB501: 120 Ω @ 100 MHz; L_0603_1608Metric
FID1, FID2, FID3, FID4, FID5, FID6, FID7: Fiducial; Fiducial_1mm_Mask2mm
J101: GCT USB4105-GF-A; J101_USB4105-GF-A_12lands_4stakes
J201: PCB pads (no component); J201_8_DebugPads_P2.54mm
J202: PCB pads (no component); J202_5_JTAGPads_P2.54mm
J701: G-Switch GT-3321667P-01; J701_GT-3321667P-01_maker_slots
J702: HRO PJ-332A-6A; J702_PJ-332A-6A_peg_holes
K601, K602, K603, K604: TLP3545A; K601_TLP3545A_LF1_HandSolder
MH1, MH2, MH3, MH4: M3 plated to GND; MountingHole_M3_3.2mm_Pad6.0mm
Q207, Q502, Q503, Q504, Q505, Q506, Q616, Q617, Q619, Q620, Q622: AO3400A; SOT-23-3_L2.9-W1.3-P1.90-LS2.4-BR
Q507, Q612, Q614: MMBT3904; SOT-23-3_L2.9-W1.3-P1.90-LS2.4-BR
Q618, Q621: 2N7002; SOT-23-3_L2.9-W1.3-P1.90-LS2.4-BR
Q623, Q624, Q625, Q626, Q627: MMBT3904; SOT-23-3_L2.9-W1.6-P1.90-LS2.8-BR
R101, R102, R628, R629, R630, R631, R639, R663: 5.1 kΩ; R_0402_1005Metric
R103, R104, R201, R202, R207, R208, R212, R213, R216, R217, R218, R227, R231, R232, R234, R236, R238, R239, R305, R508, R522, R951: 10 kΩ; R_0402_1005Metric
R105, R108, R235, R240, R303, R505, R511, R512, R513, R535, R537, R538, R646, R647, R648, R653, R654, R655, R656, R662, R667, R669, R673, R680, R687, R691, R693, R695, R696, R925, R939, R950: 100 kΩ; R_0402_1005Metric
R106, R536: 47 kΩ; R_0402_1005Metric
R107, R241, R417, R418, R419, R420: 0 Ω; R_0402_1005Metric
R109, R532, R688, R689, R935, R936, R937: 470 kΩ; R_0402_1005Metric
R203, R204, R205, R206, R210, R211, R215, R224, R225: 33 Ω; R_0402_1005Metric
R228, R229, R230, R242, R243, R244, R245, R246, R665: 330 Ω; R_0402_1005Metric
R237, R643, R644: 4.7 kΩ; R_0402_1005Metric
R301, R302: 2.2 Ω; R_0805_2012Metric
R401, R403, R405, R407, R409, R411, R413, R415: 1.30 kΩ; R_0603_1608Metric
R402, R404, R406, R408, R410, R412, R414, R416: 2.00 kΩ; R_0603_1608Metric
R423, R424, R425, R426: 698 Ω; R_0603_1608Metric
R431: 9.76 kΩ; R_0603_1608Metric
R432: 10.0 kΩ; R_0603_1608Metric
R438, R439, R440, R441, R442, R443, R444, R445: 680 Ω; R_0603_1608Metric
R446, R447: DNF (237 k … 2 M); R_0603_1608Metric
R501: 221 kΩ; R_0603_1608Metric
R502, R504: 100 kΩ; R_0603_1608Metric
R503: 205 kΩ; R_0603_1608Metric
R509: 4.75 kΩ; R_0603_1608Metric
R510: 3.74 kΩ; R_0603_1608Metric
R526, R528: 22 kΩ; R_0402_1005Metric
R527, R529: 10 Ω; R_0603_1608Metric
R530: 4.7 Ω; R_0603_1608Metric
R531: 1 Ω; R_0603_1608Metric
R533: 15.0 kΩ; R_0603_1608Metric
R534: 11.0 kΩ; R_0603_1608Metric
R624, R625, R626, R627, R658, R661: 6.8 kΩ; R_0402_1005Metric
R632, R633, R634, R635, R640: 16.9 kΩ; R_0402_1005Metric
R641, R642: 24.9 Ω; R_0402_1005Metric
R645, R692, R701, R703: 1 kΩ; R_0402_1005Metric
R657, R659, R670: 10.0 kΩ; R_0402_1005Metric
R660, R690, R694, R916, R917, R918, R919, R926, R927, R928, R929: 330 kΩ; R_0402_1005Metric
R666, R668, R930, R931, R932, R933, R938, R940: 1.00 MΩ; R_0402_1005Metric
R671: 2.2 MΩ; R_0402_1005Metric
R672: 237 kΩ; R_0402_1005Metric
R674, R702: 2.2 kΩ; R_0402_1005Metric
R675, R682: 44.2 kΩ; R_0402_1005Metric
R676, R683: 200 kΩ; R_0402_1005Metric
R677, R684: 300 kΩ; R_0603_1608Metric
R678, R685, R901, R903, R905, R907, R909, R911, R913, R915: 1.00 MΩ; R_0603_1608Metric
R679, R686: 22 MΩ; R_0402_1005Metric
R681: 4.7 MΩ; R_0402_1005Metric
R900, R902, R904, R906, R908, R910, R912, R914: 487 kΩ; R_0603_1608Metric
R920, R921, R922, R923: 110 kΩ; R_0402_1005Metric
R924: 69.8 kΩ; R_0402_1005Metric
R934: 360 kΩ; R_0402_1005Metric
R941: 88.7 kΩ; R_0402_1005Metric
R942, R943, R944, R945, R946, R947, R948, R949: 910 kΩ; R_0402_1005Metric
TP701, TP702, TP703, TP704, TP705, TP706, TP707, TP708, TP709, TP710, TP711, TP712, TP713, TP714, TP715, TP716, TP717, TP718, TP719, TP720, TP721, TP722, TP723, TP724, TP725, TP726, TP727, TP728, TP729, TP730, TP731, TP733, TP734, TP735, TP736, TP737, TP738, TP739, TP740, TP741, TP742, TP743, TP744, TP745, TP746, TP747, TP748, TP749, TP750, TP751, TP752, TP753: No part; TestPad_D1.0mm
TP732: PCB pads (no component); TestPad_D1.0mm
U101: ST USBLC6-2SC6; SOT-23-6_L2.9-W1.6-P0.95-LS2.8-BL
U102: TI TPS25200DRVR; WSON-6_L2.0-W2.0-P0.65-TL-EP_PAD
U103: TI TPD2E2U06DRLR; SOT-553-5_L1.6-W1.2-P0.50-LS1.6-TL-1
U201: CH32V307RCT6; LQFP-64_L10.0-W10.0-P0.50-LS12.0-BL
U202: AGRV2KQ32; QFN-32_L4.0-W4.0-P0.40-BL-EP2.7_EP
U205: 74LVC1G157; SOT-363_L2.0-W1.3-P0.65-LS2.1-BR
U206: 74LVC1G11; SC-88-6_L2.0-W1.3-P0.65-LS2.1-BL
U208: 74LVC3G34; VSSOP-8_L2.1-W2.4-P0.50-LS3.2-BR
U301: ES9018K2M; QFN-28_L5.0-W5.0-P0.50-BL-EP3.3_EP
U302: 3.3 V, 250 mA; SOT-23-5_L3.0-W1.7-P0.95-LS2.8-BR
U303: 1.300 V (R533/R534); SOT-23-5_L3.0-W1.7-P0.95-LS2.8-BR
U401, U402: OPA1622IDRCR; VSON-10_L3.0-W3.0-P0.50-BL-EP1.65_PAD
U403, U404: OPA2210IDGKR; VSSOP-8_L3.0-W3.0-P0.65-LS5.0-BL
U501: +3.85 / -3.72 V; WSON-12_L3.0-W2.0-P0.50-BL-EP_PAD
U502: 3.3 V, 150 mA; SOT-23-5_L3.0-W1.7-P0.95-LS2.8-BR
U503: TI TPS259621DDAR; ESOP-8_L4.9-W3.9-P1.27-LS6.0-BL-EP_PAD
U504: 3.3 V, 1 A; WSON-6_L2.0-W2.0-P0.65-TL-EP_PAD
U505: TI TMUX1101DBVR; SOT-23-5_L2.9-W1.6-P0.95-LS2.8-BR
U603, U606, U609, U610, U611, U612: TLV1704; TSSOP-14_L5.0-W4.4-P0.65-LS6.4-BL
U604: OPA2333; SOP-8_L4.9-W3.9-P1.27-LS6.0-BL
U605: TLV3402; SOIC-8_L4.9-W3.9-P1.27-LS6.0-BL
U607: 74AUP1G17; TSSOP-5_L2.1-W1.3-P0.65-LS2.2-BR
U608: 74LVC1G74; VSSOP-8_L2.3-W2.0-P0.50-LS3.1-BR
U613, U614, U615, U616, U617, U618, U619, U620: TLV3402; VSSOP-8_L3.0-W3.0-P0.65-LS5.0-BL
X201: 80.000 MHz; X201_KC2520K80_Kyocera
X202: 49.152 MHz; X202_X203_NDK_NZ2520SDA
X203: 45.1584 MHz; X202_X203_NDK_NZ2520SDA
Y201: 8 MHz; CRYSTAL-SMD_L5.0-W3.2

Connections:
1V3: C309.1, C310.1, C312.1, R530.1, R533.1, R670.1, TP706.1, U301.21, U303.5
3V3A: C302.1, C441.1, D104.1, FB302.1, R301.1, R302.1, R431.1, R446.1, R527.1, R628.2, R629.2, R630.2, R631.2, R639.2, R657.1, R675.1, R682.1, R934.1, R938.1, TP705.1, U302.5
3V3D: C217.1, C218.1, C219.1, C222.1, C223.1, C224.1, C311.1, C512.1, C622.1, C623.1, C630.1, FB202.1, FB301.1, J202.1, R207.2, R208.2, R529.1, R690.1, R691.1, TP704.1, U205.5, U206.5, U208.8, U303.1, U303.3, U504.1, U504.2, U604.8, U607.5, U608.7, U608.8, X201.4, X202.4, X203.4
3V3M: C203.1, C204.1, C205.1, C206.1, C207.1, C208.1, C209.1, C210.1, C211.1, C221.1, C502.1, C515.1, C628.1, R201.2, R240.2, R241.1, R512.2, R526.1, R528.1, R648.2, R677.1, R680.1, R684.1, R687.1, TP703.1, U101.5, U201.1, U201.13, U201.19, U201.32, U201.48, U201.64, U502.5, U505.5, U605.8
5V_ANA: C506.1, D105.1, FB501.1, TP702.1, U503.5
5V_ANA_F: C507.1, FB501.2, R505.2, R531.1, R535.1, U501.3, U501.8, U501.12
5V_SYS: C301.1, C501.1, C505.1, D104.3, D105.3, K601.1, K603.1, R105.1, TP701.1, U102.1, U302.1, U503.4, U504.6
ANA_EN: R513.1, TP737.1, U201.53, U503.3
ANA_FAULT_N: R512.1, TP723.1, U201.57, U503.6
ANA_SENSE: C516.1, R535.2, R536.1, TP752.1, U201.14
AUD_EN: Q504.1, Q620.3, R237.2, R508.1, TP738.1, U504.4
AVCC_EN: Q502.1, R236.1, R303.1, TP720.1, U201.52, U302.3
AVCC_L: C303.1, C305.1, D405.2, D406.2, R301.2, TP710.1, U301.15
AVCC_R: C304.1, C306.1, D407.2, D408.2, R302.2, U301.16
BCLK: R204.2, TP715.1, U301.27
BOOT0: J201.6, R202.1, U201.60
CC1: J101.A5, R101.1, R103.1, TP726.1, U103.3
CC1_ADC: R103.2, U201.16
CC2: J101.B5, R102.1, R104.1, TP727.1, U103.5
CC2_ADC: R104.2, U201.17
CPLD_IRQ: U201.39, U202.14
CPLD_JTCK: J202.2, R239.1, U202.25
CPLD_JTMS: J202.3, R238.1, U202.24
CPLD_NRST: J202.4, R231.1, U201.25, U202.4
DACL: C417.1, R423.1, U301.13, U403.2
DACLB: C418.1, R424.1, U301.14, U403.6
DACR: C419.1, R425.1, U301.9, U404.2
DACRB: C420.1, R426.1, U301.10, U404.6
DAC_LOCK: U201.40, U301.23
DAC_RESETB: Q207.3, R305.1, TP746.1, U301.28
DC_PERMIT_N: Q618.3, R648.1, TP722.1, U201.55
DC_SENSE_LN: C609.1, R243.1, R625.2, R629.1, R633.1
DC_SENSE_LP: C608.1, R242.1, R624.2, R628.1, R632.1
DC_SENSE_RN: C611.1, R245.1, R627.2, R631.1, R635.1
DC_SENSE_RP: C610.1, R244.1, R626.2, R630.1, R634.1
DVCC: C308.1, C439.1, FB301.2, R305.2, U301.18
FAM_CLK: R215.2, TP712.1, U202.1
GND: C101.2, C102.2, C103.2, C104.2, C201.2, C202.2, C203.2, C204.2, C205.2, C206.2, C207.2, C208.2, C209.2, C210.2, C211.2, C212.2, C213.2, C214.2, C215.2, C217.2, C218.2, C219.2, C220.2, C221.2, C222.2, C223.2, C224.2, C301.2, C302.2, C303.2, C304.2, C305.2, C306.2, C307.2, C308.2, C309.2, C310.2, C311.2, C312.2, C402.2, C404.2, C406.2, C408.2, C409.2, C410.2, C411.2, C412.2, C413.2, C414.2, C415.2, C416.2, C421.2, C423.2, C424.2, C425.2, C426.2, C431.2, C432.2, C433.2, C434.2, C435.2, C436.2, C437.2, C438.2, C439.2, C440.2, C441.2, C442.2, C443.1, C501.2, C502.2, C505.2, C506.2, C507.2, C509.2, C510.2, C511.2, C512.2, C513.2, C514.2, C515.2, C516.2, C608.2, C609.2, C610.2, C611.2, C616.2, C617.2, C618.2, C619.2, C620.2, C621.2, C622.2, C623.2, C625.2, C626.2, C627.2, C628.2, C629.2, C630.2, C631.2, C632.2, C633.2, C634.2, C635.2, C636.2, C637.2, C638.2, C639.2, C640.2, C641.2, C642.2, C643.2, C644.2, C645.2, C646.2, C647.2, C648.2, C649.2, C650.2, C651.2, C652.2, C653.2, C654.2, C655.2, C656.2, C657.2, C658.2, D102.2, D405.1, D406.1, D407.1, D408.1, D413.1, D414.3, D609.1, D701.2, D702.2, D703.2, D704.2, D705.2, D706.2, J101.A1/B12, J101.B1/A12, J201.5, J202.5, J701.1, J702.1, J702.2, MH1.1, MH2.1, MH3.1, MH4.1, Q207.2, Q502.2, Q503.2, Q504.2, Q505.2, Q506.2, Q507.2, Q618.2, Q619.2, Q620.2, Q621.2, Q622.2, Q623.2, Q624.2, Q625.2, Q626.2, Q627.2, R101.2, R102.2, R106.2, R107.2, R108.2, R202.2, R212.2, R213.2, R216.2, R217.2, R218.2, R227.2, R232.2, R234.2, R235.2, R239.2, R303.2, R404.2, R408.2, R412.2, R416.2, R432.2, R447.2, R502.2, R504.2, R508.2, R509.2, R511.2, R513.2, R532.2, R534.2, R536.2, R538.2, R632.2, R633.2, R634.2, R635.2, R640.2, R646.2, R659.2, R661.2, R663.2, R666.2, R669.2, R673.2, R676.2, R678.2, R683.2, R685.2, R694.2, R696.2, R901.2, R907.2, R909.2, R915.2, R925.2, R935.2, R939.2, R941.2, TP728.1, TP729.1, TP730.1, TP731.1, TP741.1, TP742.1, U101.2, U102.5, U102.PAD, U103.4, U201.12, U201.18, U201.31, U201.47, U201.63, U202.17, U202.30, U202.EP, U205.2, U206.2, U208.4, U301.1, U301.2, U301.5, U301.8, U301.11, U301.12, U301.19, U301.20, U301.22, U301.EP, U302.2, U303.2, U401.3, U402.3, U501.4, U501.PAD, U502.2, U503.1, U503.PAD, U504.3, U504.5, U504.PAD, U505.2, U505.3, U604.4, U605.4, U607.3, U608.4, U613.5, U614.5, U615.5, U616.5, U617.5, U618.5, U619.5, U620.5, X201.2, X202.2, X203.2
I2C_SCL: R207.1, U201.29, U301.3
I2C_SDA: R208.1, U201.30, U301.4
ILIM_HI: R511.1, TP739.1, U201.50, U505.4
JACK_LN: D703.1, J701.6, K602.6
JACK_LP: D701.1, J701.7, J701.8, J702.4, K601.6
JACK_RN: D704.1, J701.2, J701.3, K604.6
JACK_RP: D702.1, J701.4, J701.5, J702.3, K603.6
LED_G: R701.1, U201.37
LED_R: R702.1, U201.38
LEG_LN: K602.4, R418.2, R625.1, R902.1, R906.1, R927.1, R931.1
LEG_LP: K601.4, R417.2, R624.1, R900.1, R904.1, R926.1, R930.1
LEG_RN: K604.4, R420.2, R627.1, R910.1, R914.1, R929.1, R933.1
LEG_RP: K603.4, R419.2, R626.1, R908.1, R912.1, R928.1, R932.1
LINK_FRAME: U202.11, U208.2
LINK_MISO: U201.22, U202.12
LINK_MOSI: U202.10, U208.5
LINK_SCK: U202.9, U208.7
LRCLK: R205.2, TP716.1, U301.26
LRCLK_FB: U201.54, U202.13
MCLK: R203.2, R665.1, R703.1, TP711.1, U301.7
MCLK_EN: R218.1, TP740.1, U202.21, U206.1
N1_SHIELD: C101.1, J101.S1, J101.S2, J101.S3, J101.S4, R107.1
N1_U102_EN: C104.1, Q507.3, R109.2, U102.4
N1_U102_ILIM: R108.1, U102.2
N2_AUD_EN_MCU: R237.1, U201.51
N2_AVCC_EN_G: Q619.3, R236.2, TP719.1, U206.3
N2_BCLK_SRC: R204.1, R228.1, U202.18
N2_BOOT1: R232.1, U201.28
N2_CAP_CK: R228.2, U201.34
N2_CAP_SD: R230.2, U201.36
N2_CAP_WS: R229.2, U201.33
N2_DCS_LN_PIN: R243.2, U201.9
N2_DCS_LP_PIN: R242.2, U201.8
N2_DCS_RN_PIN: R245.2, U201.11
N2_DCS_RP_PIN: R244.2, U201.10
N2_HSE_IN: C201.1, U201.5, Y201.1
N2_HSE_OUT: C202.1, U201.6, Y201.2
N2_J201_3V3: J201.1, R241.2
N2_LINK_FRAME_MCU: U201.20, U208.6
N2_LINK_MOSI_BUF: R225.2, U208.3
N2_LINK_MOSI_MCU: R225.1, U201.23
N2_LINK_SCK_BUF: R224.2, U208.1
N2_LINK_SCK_MCU: R224.1, U201.21
N2_LRCLK_SRC: R205.1, R229.1, U202.19
N2_MCLK_OE: R235.1, R645.1, TP735.1, U201.27, U206.4, X201.1
N2_MCLK_PERMIT: R234.1, U201.35, U206.6
N2_MUX_I0: R210.2, R216.1, U205.3
N2_MUX_I1: R211.2, R217.1, U205.1
N2_MUX_Y: R215.1, U205.4
N2_RESET_DRV: Q207.1, R240.1, U201.41
N2_SDATA_SRC: R206.1, R230.1, U202.20
N2_V3A_MON_PIN: R246.2, U201.24
N2_V33_CPLD: C213.1, C214.1, C215.1, C220.1, FB202.2, R231.2, R238.2, U202.6, U202.16, U202.32
N2_X201_OUT: R203.1, R227.1, X201.3
N2_X202_OUT: R210.1, X202.3
N2_X203_OUT: R211.1, X203.3
N3_1V3_FB: R533.2, R534.1, U303.4
N4_IVL_N: C418.2, D406.3, R403.1, R405.1, R424.2, R654.1, U403.7
N4_IVL_P: C417.2, D405.3, R401.1, R407.1, R423.2, R653.1, U403.1
N4_IVR_N: C420.2, D408.3, R411.1, R413.1, R426.2, R656.1, U404.7
N4_IVR_P: C419.2, D407.3, R409.1, R415.1, R425.2, R655.1, U404.1
N4_LN_INN: C403.1, R406.1, R440.2, U401.6
N4_LN_INP: C404.1, R408.1, R441.2, U401.5
N4_LN_OUT: C403.2, R406.2, R418.1, U401.7
N4_LN_TN: C433.1, R405.2, R440.1
N4_LN_TP: C434.1, R407.2, R441.1
N4_LP_INN: C401.1, R402.1, R438.2, U401.10
N4_LP_INP: C402.1, R404.1, R439.2, U401.1
N4_LP_OUT: C401.2, R402.2, R417.1, U401.9
N4_LP_TN: C431.1, R401.2, R438.1
N4_LP_TP: C432.1, R403.2, R439.1
N4_RN_INN: C407.1, R414.1, R444.2, U402.6
N4_RN_INP: C408.1, R416.1, R445.2, U402.5
N4_RN_OUT: C407.2, R414.2, R420.1, U402.7
N4_RN_TN: C437.1, R413.2, R444.1
N4_RN_TP: C438.1, R415.2, R445.1
N4_RP_INN: C405.1, R410.1, R442.2, U402.10
N4_RP_INP: C406.1, R412.1, R443.2, U402.1
N4_RP_OUT: C405.2, R410.2, R419.1, U402.9
N4_RP_TN: C435.1, R409.2, R442.1
N4_RP_TP: C436.1, R411.2, R443.1
N4_VNEG_IV: C424.1, C426.1, C443.2, D412.2, D414.1, TP751.1, U403.4, U404.4
N4_VPOS_IV: C423.1, C425.1, C442.1, D411.1, D413.3, TP750.1, U403.8, U404.8
N5_C1N: C508.2, U501.9
N5_C1P: C508.1, U501.10
N5_CP: C509.1, U501.5
N5_DAMP: C513.1, R531.2
N5_DIS_13_R: Q506.3, R530.2
N5_DIS_A: Q502.3, Q503.1, R526.2
N5_DIS_A_R: Q503.3, R527.2
N5_DIS_D: Q504.3, Q505.1, Q506.1, R528.2
N5_DIS_D_R: Q505.3, R529.2
N5_DVDT: C514.1, U503.2
N5_FBN: R503.2, R504.1, U501.7
N5_FBP: R501.2, R502.1, U501.2
N5_ILIM: R509.1, R510.1, U503.7
N5_ILIM_HI: R510.2, U505.1
N5_PGOOD: R505.1, R522.1, U501.1
N5_Q507_B: Q507.1, R537.2, R538.1
N5_U102_OFF: R537.1, U201.3
N6_ARM: R692.1, R695.1, U608.5
N6_ARMG: Q622.1, R692.2, R696.1
N6_ARM_MCU: R695.2, U201.26
N6_BL: Q612.1, R643.2
N6_BR: Q614.1, R644.2
N6_CLR_N: Q621.3, R691.2, U608.2, U608.6
N6_CML: C620.1, R653.2, R654.2, TP733.1, U603.4, U603.7
N6_CMR: C621.1, R655.2, R656.2, TP734.1, U603.8, U603.11
N6_CMTH_HI: R657.2, R658.1, U603.5, U603.9
N6_CMTH_LO: R658.2, R659.1, R660.2, U603.6, U603.10
N6_DA_L: R900.2, R901.1, U609.4
N6_DA_R: R908.2, R909.1, U610.4
N6_DB_L: R902.2, R903.1, U609.5
N6_DB_R: R910.2, R911.1, U610.5
N6_DC_L: R904.2, R905.1, U609.7
N6_DC_R: R912.2, R913.1, U610.7
N6_DD_L: R906.2, R907.1, U609.6
N6_DD_R: R914.2, R915.1, U610.6
N6_EL: Q612.2, R641.1, TP743.1, U604.2
N6_EM: Q616.3, R641.2, R642.2, TP745.1
N6_ER: Q614.2, R642.1, TP744.1, U604.6
N6_GMC: Q616.1, R645.2
N6_H: C617.1, Q617.1, Q618.1, R647.2, R671.1, TP724.1, U603.1, U603.2, U603.13, U603.14, U606.1, U606.2, U606.10, U606.14, U609.13, U609.14, U610.13, U610.14
N6_HREF: R693.2, R694.1, U606.11
N6_IREF: R662.2, R663.1, U604.3, U604.5
N6_LWLN: C644.1, R931.2, U615.3, U616.2
N6_LWLP: C643.1, R930.2, U613.3, U614.2
N6_LWRN: C646.1, R933.2, U619.3, U620.2
N6_LWRP: C645.1, R932.2, U617.3, U618.2
N6_M2: Q616.2, Q617.3
N6_M3: Q617.2, Q622.3
N6_MCK_BUF: C624.1, U607.4
N6_MCK_CMP: R667.2, U606.7
N6_MCK_IN: R665.2, U607.2
N6_MCK_RC: C625.1, D609.2, R666.1, R667.1, TP747.1
N6_OAL: R643.1, U604.1
N6_OAR: R644.1, U604.7
N6_OLN_L: Q624.1, R917.2, U609.1, U611.1, U611.14, U614.7, U615.7
N6_OLN_R: Q626.1, R919.2, U610.1, U612.1, U612.14, U618.7, U619.7
N6_OLP_L: Q623.1, R916.2, U609.2, U611.2, U611.13, U613.7, U616.7
N6_OLP_R: Q625.1, R918.2, U610.2, U612.2, U612.13, U617.7, U620.7
N6_ORLN: C640.1, R927.2, U611.8, U611.11
N6_ORLP: C639.1, R926.2, U611.4, U611.7
N6_ORQC: Q627.3, R951.2
N6_ORRN: C642.1, R929.2, U612.8, U612.11
N6_ORRP: C641.1, R928.2, U612.4, U612.7
N6_ORTB: Q627.1, R950.2
N6_ORTEST: R937.2, R950.1, U201.4
N6_PMP: C624.2, D609.3
N6_REF13: R672.2, R673.1, U606.4, U606.9
N6_REFMCK: R668.2, R669.1, U606.6
N6_SL_A: K601.2, K602.1
N6_SL_C: K602.2, Q612.3
N6_SR_A: K603.2, K604.1
N6_SR_C: K604.2, Q614.3
N6_TLN_L: C632.1, Q624.3, R921.2, U609.10
N6_TLN_R: C634.1, Q626.3, R923.2, U610.10
N6_TLP_L: C631.1, Q623.3, R920.2, U609.8
N6_TLP_R: C633.1, Q625.3, R922.2, U610.8
N6_TRIP: Q621.1, R690.2, U606.13
N6_TWLNN: C650.1, R945.2, U616.1, U616.6
N6_TWLNP: C649.1, R944.2, U615.1, U615.6
N6_TWLPN: C648.1, R943.2, U614.1, U614.6
N6_TWLPP: C647.1, R942.2, U613.1, U613.6
N6_TWRNN: C654.1, R949.2, U620.1, U620.6
N6_TWRNP: C653.1, R948.2, U619.1, U619.6
N6_TWRPN: C652.1, R947.2, U618.1, U618.6
N6_TWRPP: C651.1, R946.2, U617.1, U617.6
N6_V3AG_A: Q619.1, R679.1, R680.2, R681.1, R688.1, TP748.1, U605.1
N6_V3AG_A_MCU: R688.2, U201.45
N6_V3AG_B: Q620.1, R686.1, R687.2, R689.1, TP749.1, U605.7
N6_V3AG_B_MCU: R689.2, U201.62
N6_V3AG_S: R681.2, U606.8
N6_V3A_DA: R675.2, R676.1, U605.2
N6_V3A_DB: R682.2, R683.1, U605.6
N6_V3R_A: R677.2, R678.1, R679.2, U605.3
N6_V3R_B: R684.2, R685.1, R686.2, U605.5
N6_V13_CMP: C629.1, R670.2, R671.2, R674.1, U606.5
N6_V13_TEST: D610.3, U201.61
N6_V13_TI: D610.1, R674.2
N6_VLLN: R940.2, R941.1, U614.3, U616.3, U618.3, U620.3
N6_VLLP: R938.2, R939.1, U613.2, U615.2, U617.2, U619.2
N6_VORN: R936.2, R937.1, U611.6, U611.10, U612.6, U612.10
N6_VORP: R934.2, R935.1, R951.1, U611.5, U611.9, U612.5, U612.9
N6_VT: R924.2, R925.1, U609.9, U609.11, U610.9, U610.11
N7_LEDG_A: D705.1, R701.2
N7_LEDR_A: D706.1, R702.2
NRST: C212.1, J201.4, R201.1, U201.7
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

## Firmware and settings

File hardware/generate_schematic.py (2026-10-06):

#!/usr/bin/env python3
"""Capture the DAC-HPA workbook plus an asserted functional ECO in KiCad.

Parts List v0.9 and Calculation Package v1.1 remain immutable baselines. The
explicit overlay below corrects the LED pads, buffers U605's MCU readbacks,
and adds local J702 ESD devices. U403/U404 retain the owner-approved DGK
package substitution and swap their equivalent A/B I/V channels for the
reviewed physical macro. Physical and firmware qualification gates remain open.
"""

from __future__ import annotations

import json
import math
import re
import uuid
from collections import defaultdict
from dataclasses import dataclass, replace
from functools import lru_cache
from pathlib import Path

from openpyxl import load_workbook


HERE = Path(__file__).resolve().parent
ROOT = HERE.parent
WORKBOOK = ROOT / "doc" / "DAC_HPA_Parts_List_v0.9.xlsx"
PROJECT = "DAC_HPA"
GRID = 1.27
ROOT_UUID = "0c6c0976-e401-5c8a-8977-bc60da031e5e"


def uid(*parts: object) -> str:
    return str(uuid.uuid5(uuid.NAMESPACE_URL, "hi-res-dac/" + "/".join(map(str, parts))))


def q(value: object) -> str:
    return json.dumps(str(value), ensure_ascii=False)


def f(value: float) -> str:
    return f"{value:.4f}".rstrip("0").rstrip(".") or "0"


def mm(units: int | float) -> str:
    return f(float(units) * GRID)


def natural(ref: str) -> tuple[str, int, str]:
    match = re.fullmatch(r"([A-Za-z]+)(\d+)(.*)", ref)
    if match:
        return match.group(1), int(match.group(2)), match.group(3)
    return ref, 0, ""


@dataclass(frozen=True)
class Pin:
    number: str
    name: str
    net: str


@dataclass
class Part:
    row: int
    block: int
    refs: list[str]
    value: str
    mpn: str
    package: str
    rating_tolerance: str
    lcsc: str
    fit: str
    source: str
    datasheet: str
    description: str
    notes: str

    @property
    def symbol_id(self) -> str:
        return f"P{self.row:03d}"


def read_source() -> tuple[dict[str, Part], dict[str, list[Pin]], dict[str, Part]]:
    wb = load_workbook(WORKBOOK, read_only=True, data_only=True)
    net_pins: dict[str, list[Pin]] = defaultdict(list)
    for row in list(wb["Netlist"].values)[3:]:
        if row[0] is not None:
            net_pins[str(row[0])].append(Pin(str(row[1]), str(row[2]), str(row[3])))

    parts: dict[str, Part] = {}
    libparts: dict[str, Part] = {}
    for number, row in enumerate(list(wb["Parts list"].values)[3:], start=4):
        if row[1] is None or str(row[12]) == "Board":
            continue
        refs = [ref for ref in str(row[25] or "").split(",") if ref]
        if not refs:
            continue
        block = int(str(row[0]).split(" ", 1)[0])
        part = Part(
            row=number,
            block=block,
            refs=refs,
            value=str(row[4] or ""),
            mpn=str(row[7] or ""),
            package=str(row[5] or ""),
            rating_tolerance=str(row[6] or ""),
            lcsc=str(row[8] or ""),
            fit=str(row[12] or ""),
            source=str(row[10] or ""),
            datasheet=str(row[23] or ""),
            description=str(row[3] or ""),
            notes=str(row[24] or ""),
        )
        if set(refs) == {"U403", "U404"}:
            if (part.value, part.mpn, part.package, part.lcsc) != (
                "OPA2210IDR", "TI OPA2210IDR", "SOIC-8", "C1849415"
            ):
                raise ValueError("U403/U404 source MPN changed; review the approved DGK override")
            part.value = "OPA2210IDGKR"
            part.mpn = "TI OPA2210IDGKR"
            part.package = "VSSOP-8 (DGK)"
            part.lcsc = "C2876414"
            part.source = "JLCPCB Extended SMT (pre-order)"
            part.notes = (
                "Owner-approved 27 Sep 2026 package substitution; "
                "provisional DAC-to-I/V routed limit 7 mm, subject to extraction "
                "and I/V step-response bring-up. JLC extended part C2876414; "
                "quantity and sourcing must be confirmed before order."
            )
        if set(refs) == {"R417", "R418", "R419", "R420"}:
            if (part.value, part.mpn, part.package, part.lcsc,
                    part.rating_tolerance, part.fit) != (
                "0 Ω", "UNI-ROYAL 0402WGF0000TCE", "0402", "C17168",
                "jumper, ≤ 50 mΩ", "Yes"
            ):
                raise ValueError("Output-link source changed; review the low-DCR jumper ECO")
            # This is a same-value, same-size review candidate. The v0.9
            # workbook remains the immutable source baseline; R107 stays on
            # its own original BOM row. Yageo specifies <=1 mOhm for the
            # PA0402 07 jumper, but stock and assembly need an order check.
            part.mpn = "YAGEO PA0402-R-070RL"
            part.lcsc = "C4044221"
            part.rating_tolerance = "jumper, ≤ 1 mΩ (manufacturer maximum)"
            part.source = "JLCPCB Extended SMT; stock must be rechecked at order"
            part.datasheet = "https://www.yageogroup.com/content/Resource%20Library/Datasheet/PYU-PA_JUMPER_L_51_ROHS.pdf"
            part.notes = (
                "Review-only output-link BOM ECO, 28 Sep 2026: same nominal "
                "0 Ω and 0402 land; Yageo PA0402 07 maximum resistance "
                "1 mΩ versus the source workbook's 50 mΩ link assumption. "
                "Retain removable design-for-test links R417–R420. "
                "JLC C4044221 availability, footprint, assembly and R-15 "
                "measurement require order-stage confirmation."
            )
        libparts[part.symbol_id] = part
        for ref in refs:
            if ref in parts:
                raise ValueError(f"Repeated designator {ref} in Parts list")
            parts[ref] = part

    if set(parts) != set(net_pins):
        raise ValueError(
            f"Parts/netlist designator mismatch: parts-only={sorted(set(parts)-set(net_pins))}, "
            f"netlist-only={sorted(set(net_pins)-set(parts))}"
        )
    for part in libparts.values():
        signatures = {
            tuple((pin.number, pin.name) for pin in net_pins[ref]) for ref in part.refs
        }
        if len(signatures) != 1:
            raise ValueError(f"Different pin maps within Parts list row {part.row}")
    return parts, net_pins, libparts
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

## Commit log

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2026-09-27 Reassess DAC placement and add audio EMI geometry audit
    [04_iv_output_legs.kicad_sch, DAC_HPA.kicad_pcb, DAC_HPA_100x80_REVIEW_ONLY.kicad_pcb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]
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2026-09-27 Add corrected KiCad 3D board and USB-C previews
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2026-09-28 Replace right-angle audio bends with manual 45-degree routes
    [DAC_HPA_120x100_INTEGRATED_AUDIO_STUDY_ONLY.kicad_pcb]
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2026-09-29 Route U610 timer cluster and bound local PCB clearances
    [DAC_HPA_120x100_INTEGRATED_AUDIO_STUDY_ONLY.kicad_pcb]
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2026-09-30 feat: route power feeds, MCU fan-out and most signals on integrated board
    Checkpoint of the 30 September layout pass on the 120 x 100 mm integrated
    audio study (review-only, no PCBA release). CI replay passes with the
    committed project settings: 0 DRC errors/warnings, 183 ratsnest links left.
    - GND pours on F.Cu/L3/B.Cu in the manifest; replay refills them with
    kicad-cli so the .kicad_dru pour rules (high-Z 0.5 mm, USB 0.6 mm) hold
    - 5V_SYS to U302 and the photo-relays, 5V_ANA/5V_ANA_F at 0.8 mm, VBUS,
    U201 south fan-out with VDD pins straight to their decoupling caps
    - moves to clear blockages: R505, R531/C513 damper to FB501.2, R245, R703
    - check_dac_core_routes counts only the two 0.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
    [DAC_HPA_120x100_INTEGRATED_AUDIO_STUDY_ONLY.kicad_pcb]
2026-09-30 feat: route to 87 ratsnest links and add EMS simulations
    Second checkpoint of the integrated audio study (review-only). CI replay
    passes with the committed project settings: 0 DRC errors/warnings.
    - automl/rip-up passes over protection, MCU and control nets; router vias
    keep 0.8 mm from the DAC input copper so L2 stays solid under it
    - R703 relocated beside the MCLK trunk, >= 2 mm from the DAC inputs
    - LTspice decks: headphone-output RF ingress (TVS/relay/OPA1622 network),
    FB501 + R531/C513 damper; MATLAB EMIRR/PSRR/hum budget
    - review_output_rf_filter.py: calibrated OPA1622 stability sweep of the
    proposed R417-R420 ferrite bead + LEG C0G output RF filter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
    [DAC_HPA_120x100_INTEGRATED_AUDIO_STUDY_ONLY.kicad_pcb, ems_rf_demod.csv]
2026-09-30 feat: shorten VREF, open U201 escape ring, keep vias off clock copper
    Third checkpoint of the integrated audio study (review-only). CI replay
    passes with the committed project settings: 0 DRC errors/warnings,
    87 ratsnest links left.
    - R446/R447/TP709 moved to the R431/R432/C421 divider: the I/V reference
    no longer crosses the digital area next to LINK_SCK/MCLK
    - 17 resistors around U201 moved ~3.5 mm outward for fan-out room;
    their power/GND stubs and the stale N2_AUD_EN_MCU route redrawn
    - router via keep-away extended to the MCLK/FAM_CLK/I2S copper so L2
    stays under the critical clock routes
    [DAC_HPA_120x100_INTEGRATED_AUDIO_STUDY_ONLY.kicad_pcb]
2026-09-30 sim: evaluate recommended 120 ohm bead + 220 pF output filter; add VHF/FM bands
    [ems_rf_demod.csv]
2026-09-30 feat: GND stitching, jack sleeve returns and EMS verification report
    Fourth checkpoint (review-only). CI replay passes with the committed
    project settings: 0 DRC errors/warnings, 87 ratsnest links left.
    - 375 GND stitching vias (4 mm grid + 2.5 mm edge fence) and five
    strapped GND vias per jack sleeve pin; routing-hold areas stitched later
    - EMS_VERIFICATION_2026-09-30.md: threat model, layout screen
    (INTEGRATED_AUDIO_EMS_AUDIT.json), LTspice/MATLAB results, recommended
    output RF filter ECO and the immunity tests still required
    [DAC_HPA_120x100_INTEGRATED_AUDIO_STUDY_ONLY.kicad_pcb]
2026-09-30 fix: check the discharge fit option against its frozen 72c24c3 source
    The fit option is a package trial drawn on the integrated board at 72c24c3.
    The integrated board has since moved parts and added copper, which failed
    validate_discharge_fit_option. Freeze that snapshot as the option's source.
    [DAC_HPA_120x100_DISCHARGE_FIT_SOURCE_72c24c3.kicad_pcb]
2026-09-30 feat: U201 fan-in and 0.15 mm slow-digital rule; 82 ratsnest links
    Fifth checkpoint (review-only). CI replay passes with the committed
    project settings: 0 DRC errors/warnings.
    - 20 MCU pins sealed on the outside now fan in to vias under the
    package body (ring between pin rows and the GND-island core)
    - DRU: 47 slow MCU/CPLD control nets may be 0.15 mm apart from each
    other; all other pairs keep >= 0.2 mm (owner review)
    - further automl passes; trapped passives nudged where space allowed
    [DAC_HPA_120x100_INTEGRATED_AUDIO_STUDY_ONLY.kicad_pcb]
2026-09-30 feat: protection links at documented 0.2 mm high-Z spacing; 76 ratsnest links
    Sixth checkpoint (review-only). CI replay passes with the committed
    - CPLD neighbours moved outward; trapped protection passives nudged
    - protection-comparator high-Z links routed with 0.2 mm local spacing;
    the 29 pairs below the 0.5 mm design-note target are listed in
    LAYOUT_PROGRESS_2026-09-30.md for owner review
    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
    [DAC_HPA_120x100_INTEGRATED_AUDIO_STUDY_ONLY.kicad_pcb]
2026-09-30 feat: second U201 fan-in round; 74 ratsnest links
    Seventh checkpoint (review-only). CI replay passes with the committed
    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
    [DAC_HPA_120x100_INTEGRATED_AUDIO_STUDY_ONLY.kicad_pcb]
2026-09-30 feat: Freerouting gap fill with all copper fixed; GND pad ties; 67 ratsnest links
    Freerouting 2.4.1 routed CPLD_JTCK, DC_SENSE_LP, N6_GMC and N6_IREF with every
    existing track and via held fixed and the router rules carried into the DSN
    net classes. Imported copper was cleaned for the bend gate and screened by
    KiCad DRC. U202.17 and R212.2 GND pour pieces gained via ties.
    [DAC_HPA_120x100_INTEGRATED_AUDIO_STUDY_ONLY.kicad_pcb]
2026-09-30 feat: Freerouting rip-up of plain-net router copper; 64 ratsnest links
    Router-drawn copper of 93 plain control/test nets was made movable; hand
    copper and clock, I2S, audio, high-Z, L1-only and power nets stayed fixed,
    with via keepouts along clock/DAC tracks. DRC 0, VALIDATE_OK, high-Z
    deviations unchanged.
    [DAC_HPA_120x100_INTEGRATED_AUDIO_STUDY_ONLY.kicad_pcb]
2026-09-30 feat: fit JLC SMD programming headers on J201 (MCU) and J202 (CPLD)
    ECO F05: XKB X6511WVS-08H-C60D48R1 (C2883805) and X6511WVS-05H-C60D48R1
    (C2883802) 2.54 mm SMD vertical headers replace the bare debug pad rows.
    SMD keeps L2 whole and the inner-layer routes under the north edge intact.
    Pin line moved 0.5 mm south for edge clearance; R241 and FID5 re-placed.
    The replay gains a swapped_footprints manifest entry. Schematic CI steps
    and VALIDATE_OK pass; 64 ratsnest links, 0 DRC.
    [02_usb_bridge.kicad_sch, DAC_HPA_120x100_INTEGRATED_AUDIO_STUDY_ONLY.kicad_pcb, JLCPCB_BOM_REVIEW_ONLY.csv]
2026-09-30 feat: CPLD pin reassignment ECO F06 for routability
    AGRV2K U202 I/O moved to face their destinations: LINK_FRAME 11->26 and
    LINK_MOSI 10->27 (north, toward U208), LINK_MISO 12->5 and CPLD_IRQ 14->7
    (west, toward U201). Captured as a schematic overlay with an approved delta;
    the board replay gains renamed_pads. CPLD RTL constraints must follow.
    VALIDATE_OK, schematic checks pass, 0 DRC.
    [02_usb_bridge.kicad_sch, DAC_HPA_120x100_INTEGRATED_AUDIO_STUDY_ONLY.kicad_pcb]
2026-09-30 feat: rip-up routing after CPLD ECO F06; CPLD 3V3 spine under the body; 63 links
    Freerouting rip-up round on plain nets routed LINK_MOSI to the new north pin.
    The N2_V33_CPLD L3 spine moves from the U202 west pin row to under the package
    body, clear of the EP vias; decoupling path screens unchanged. VALIDATE_OK,
    0 DRC, high-Z deviations unchanged at 29.
    [DAC_HPA_120x100_INTEGRATED_AUDIO_STUDY_ONLY.kicad_pcb]
2026-10-01 feat: CPLD pin ECO F06 v2 and FAM_CLK corridor; 64 ratsnest links
    F06 v2 moves every reassignable AGRV2K signal off the west row, which FAM_CLK
    and its L2-protection via keep-out seal: LINK_FRAME/MOSI/MISO, CPLD_IRQ and
    OSC48_EN to the north row, OSC44_EN to pin 8. R215 stands level with pin 1 so
    FAM_CLK is a straight 1.5 mm run, opening a via site beside CPLD_NRST.
    Freerouting rounds re-routed plain control nets; VREF keeps its hand route.
    VALIDATE_OK, schematic checks pass, 0 DRC. CPLD RTL constraints must follow.
    [02_usb_bridge.kicad_sch, DAC_HPA_120x100_INTEGRATED_AUDIO_STUDY_ONLY.kicad_pcb]
2026-10-01 feat: move the study board to 6 layers; 53 ratsnest links
    Owner decision: L1 sig / L2 GND / L3 PWR / L4 SIG (new) / L5 GND5 (new) /
    L6 sig. The replay gains copper_layers: 6; block 72 adds the L5 GND plane and
    an L4 GND pour. Router passes and a Freerouting round use L4: 64 -> 53 links,
    0 DRC, VALIDATE_OK. B.Cu track without a GND reference falls from 45 % to
    11 %. Return-path and EMS audits follow the new stack. Open: confirm the JLC
    6-layer stack-up and re-dimension the USB pair for 90 ohm.
    [DAC_HPA_120x100_INTEGRATED_AUDIO_STUDY_ONLY.kicad_pcb]
2026-10-01 feat: Freerouting round 8 on 6 layers; USB pair re-sized; 51 ratsnest links
    Freerouting with fan-out enabled over the plain digital nets: 53 -> 51 links,
    0 DRC, VALIDATE_OK, high-Z deviation pairs unchanged at 30. Partial stubs that
    dangled were removed; the PROG via in TP732 is filled; one orthogonal branch
    on N2_AVCC_EN_G re-joined at its via.
    USB_DP/USB_DN narrowed from 0.235 to 0.16 mm at the unchanged 0.385 mm pitch
    (0.225 mm gap): about 91 ohm differential over the 0.10 mm L1-L2 prepreg of
    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
    [DAC_HPA_120x100_INTEGRATED_AUDIO_STUDY_ONLY.kicad_pcb]
2026-10-01 feat: rip up and re-route the digital nets over all 6 layers; 34 ratsnest links
    All copper of the 90 plain digital/control nets (about 3.4 m) was ripped and
    re-routed by Freerouting with fan-out over the four signal layers, followed by
    one automated pass. L4 use rises from 505 mm / 13 nets to 1560 mm / 50 nets.
    Links fall from 51 to 34, 0 DRC, VALIDATE_OK; high-Z deviation pairs fall from
    30 to 25. Freerouting slivers and right-angle elbows are chamfered; the PROG and
    OSC44_EN vias at their test points are filled.
    [DAC_HPA_120x100_INTEGRATED_AUDIO_STUDY_ONLY.kicad_pcb]
2026-10-01 feat: second 6-layer rip-up round; 30 ratsnest links
    The 90 plain digital/control nets were re-ripped and re-routed with 16
    Freerouting passes plus one automated pass: 34 -> 30 links, 0 DRC,
    VALIDATE_OK, high-Z deviation pairs 27. Router vias within 0.10 mm of an SMD
    pad are filled and capped.
    [DAC_HPA_120x100_INTEGRATED_AUDIO_STUDY_ONLY.kicad_pcb]
2026-10-01 fix: oscillator clocks on F.Cu only, re-tie stranded GND pads; 29 ratsnest links
    - X202/X203 outputs, mux inputs and mux output are L1-only with no vias, 1.7-4.3 mm
    each (MUX_I0/I1 were 25-31 mm over L3/L4). R216/R217 move beside U205; R224
    moves toward U208; R210 is turned so the two clocks never cross.
    - Nine GND pads cut off from L2 by the inner-layer re-route are re-tied (U201 VSS,
    U205.2, R216, R234, R640, C641); MUX_I0, DC_SENSE_RN and the U612 VORP/VORN pair
    are re-routed to make room.
    29 links, 0 DRC, VALIDATE_OK, high-Z deviation pairs 28.
    [DAC_HPA_120x100_INTEGRATED_AUDIO_STUDY_ONLY.kicad_pcb]
2026-10-02 feat: ECO F07, CPLD-driven I2S capture copies; 28 ratsnest links
    Owner decision: the 330 ohm bit-perfect capture taps R228-R230 could not branch
    from the side-by-side, F.Cu-only N2_*_SRC lines at the CPLD end. U202 now drives
    dedicated copies on spare pins 22/15/23 (N2_CPY_CK/WS/SD) into R228/R229/R230 as
    source series resistors; pad 2 still feeds N2_CAP_* to PB13/PB12/PB15. The DAC
    lines carry no capture stubs. The RTL must duplicate the three I2S output
    registers onto the copy pins.
    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
    [02_usb_bridge.kicad_sch, DAC_HPA_120x100_INTEGRATED_AUDIO_STUDY_ONLY.kicad_pcb]
2026-10-02 feat: rip-up round 11 over 6 layers; 23 ratsnest links
    The 88 plain digital nets (now including the ECO F07 copy nets) were re-ripped
    and re-routed with 16 Freerouting passes plus automated clean-up: 28 -> 23
    links, 0 DRC, VALIDATE_OK, every GND pad on L2 (R213.2 re-tied), high-Z
    deviation pairs 29. AVCC_EN gets an explicit 0.15 mm width so it is no longer
    caught by the AVCC_* supply rule.
    [DAC_HPA_120x100_INTEGRATED_AUDIO_STUDY_ONLY.kicad_pcb]
2026-10-02 feat: close N6_LWRN, N6_ORLP and the LEG_LP DC-sense tap; 20 ratsnest links
    - N6_LWRN: R933 turns about its LEG_RN pad so the high-Z pad sits inside the
    LEG_RN route; C646.2's GND via moves west.
    - N6_ORLP: U611 pins 4-7 loop south of the pin row (F.Cu, no vias); the
    N6_VORN link that enclosed pin 7 takes a short L4 hop instead.
    - LEG_LP reaches the R624 DC-sense divider (24 mm, mostly L4); the local
    DC_SENSE_LP copper is re-routed round it.
    20 links, 0 DRC, VALIDATE_OK, all GND pads on L2. Open EMS item: shorten the
    DC_SENSE_LP/LN perimeter routes.
    [DAC_HPA_120x100_INTEGRATED_AUDIO_STUDY_ONLY.kicad_pcb]
2026-10-02 feat: close both N6_VT comparator pins; all fixed nets complete; 18 ratsnest links
    U610.11 and U609.11 were boxed in beside the no-via N6_TLN pins. The VNEG vias
    of pin 12 step aside, LEG_RN jogs 0.65 mm on B.Cu under U609, and N6_TLN_L's
    north branch is re-shaped from the pad tip so the 8 mm charge-timer path rule
    still holds; both pins drop to vias that join N6_VT on L4.
    Every analog, high-Z, audio, clock and power net is now complete; the 18
    remaining links are plain digital/control nets. 0 DRC, VALIDATE_OK, high-Z
    deviation pairs 29.
    [DAC_HPA_120x100_INTEGRATED_AUDIO_STUDY_ONLY.kicad_pcb]
2026-10-02 feat: rip-up round 12; 12 ratsnest links
    89 plain digital/control nets re-ripped (AVCC_EN now included) and re-routed
    with 16 Freerouting passes plus automated clean-up: 18 -> 12 links, 0 DRC,
    VALIDATE_OK, all GND pads on L2, high-Z deviation pairs 28.
    [DAC_HPA_120x100_INTEGRATED_AUDIO_STUDY_ONLY.kicad_pcb]
2026-10-02 fix: route the DC-sense ADC lines directly; rip-up round 13; 15 ratsnest links
    DC_SENSE_LP / DC_SENSE_LN had 150-165 mm board-perimeter routes (mostly L3) to
    the MCU ADC. They are now direct centre-board routes of about 70-75 mm, mostly
    F.Cu over L2, held fixed (block 80). The digital nets were then re-routed
    around them: 15 links (12 before), 0 DRC, VALIDATE_OK, all GND pads on L2.
    [DAC_HPA_120x100_INTEGRATED_AUDIO_STUDY_ONLY.kicad_pcb]
2026-10-03 feat: close the U603 CM-window threshold cluster; rip-up round 15; 9 ratsnest links
    The R659/R658/R657 threshold divider is turned in place so its LO and HI pads
    face each other. N6_CMR drops to a via under the U603 body, and the four
    CMTH_HI/LO pins escape through staggered vias to L4. The netlist is unchanged.
    A digital rip-up round then re-routed around the now-fixed cluster:
    15 -> 9 links, 0 DRC, VALIDATE_OK, all GND pads on L2.
    [DAC_HPA_120x100_INTEGRATED_AUDIO_STUDY_ONLY.kicad_pcb]
2026-10-04 fix: ECO F07 revision - WS capture taps LRCLK_FB; drop the third CPLD copy pin
    R229.1 joins LRCLK_FB (U202 pin 13, already an LRCLK copy from its own
    output register, routed to MCU PD2). Pin 15 returns to NC and N2_CPY_WS
    is deleted, so the CPLD RTL needs only pins 22 (BCLK copy) and 23 (SDATA
    copy). Schematic regenerated; verify_schematic / verify_design_notes /
    validate_integrated_audio_study pass (252 named nets). Board: 0 DRC, 9 links.
    [02_usb_bridge.kicad_sch, DAC_HPA_120x100_INTEGRATED_AUDIO_STUDY_ONLY.kicad_pcb]
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2026-10-06 feat: close the last link by hand (ECO F09 CPLD_IRQ to pin 3); 0 ratsnest links, 0 DRC
    - ECO F09: CPLD_IRQ moves from U202 pin 29 (sealed under LINK_MISO's escape
    via) to west-row I/O pin 3; schematic overlay, approved delta and
    02_usb_bridge sheet regenerated; RTL pin constraint must follow.
    - Hand routes: U201.39 escape to a 0.5 mm via; 3V3D via-to-via link moved
    from B.Cu to L3; CPLD_IRQ B.Cu/L4/L3 path to pin 3; CPLD_NRST pin-4 stub
    re-routed; LINK_MISO via nudged clear of NC pin 29.
    - Result: 0 unconnected, 0 DRC errors/warnings, 544 footprints placed,
    VALIDATE_OK, schematic verification and ERC pass. EMS layout audit refreshed.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
    [02_usb_bridge.kicad_sch, DAC_HPA_120x100_INTEGRATED_AUDIO_STUDY_ONLY.kicad_pcb]
2026-10-06 feat: GND stitching of the MCU/CPLD and comparator areas; EMS screen on the closed layout
    - 69 GND stitching vias (block 15) in the areas held until their routing
    closed: worst pour-to-via distance 9.05 -> 6.76 mm, largest edge-fence gap
    47.5 -> 13.7 mm (all remaining gaps < lambda/20 at 1 GHz).
    - EMS verification updated for the closed layout: hum, ripple, RF and ESD
    margins hold; VHF/UHF cable residual still needs the Section 5 ECO and the
    Section 6 measurements.
    - 0 ratsnest links, 0 DRC errors/warnings, VALIDATE_OK.
    [DAC_HPA_120x100_INTEGRATED_AUDIO_STUDY_ONLY.kicad_pcb]
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2026-10-06 ci: fix checks broken by ECOs F05-F09 on the frozen study boards; GitHub job HOME
    - The functional-ECO and output-macro study boards were frozen on 29 Sep;
    pad/footprint parity now skips the parts changed later by ECOs F05-F09
    (J201/J202 headers, U202 pins, R228-R230 taps). The integrated study, which
    carries every ECO, is still checked in full.
    - check_manual_review accepts the F05 headers J201/J202 as known
    connector-edge items on the historical boards (like J101/J702).
    - MACRO_STUDY_SUMMARY: 18 unclassified JLC packages (the two F05 headers).
    - GitHub Actions: run jobs with HOME=/home/kicad so KiCad finds the image's
    global symbol/footprint library tables (ERC/DRC otherwise flag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
